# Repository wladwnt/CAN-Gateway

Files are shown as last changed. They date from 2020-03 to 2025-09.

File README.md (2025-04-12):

# CAN-Gateway for Hoval devices (TopTronic&reg; E series)
DEUTSCH: [Wiki](https://github.com/wladwnt/CAN-Gateway/wiki/Deutsche-Wiki) |  [Detailierte Bedienungsanleitung](https://raw.githubusercontent.com/wladwnt/CAN-Gateway/master/Bedienungsanleitung.pdf) | [Zum CAN-Gateway in 7 Schritten](https://github.com/wladwnt/CAN-Gateway/wiki/Schritte-zum-CAN-Gateway) | [Video dazu](https://youtu.be/HU5wEv3FgdE)

ENGLISH: [Wiki](https://github.com/wladwnt/CAN-Gateway/wiki/English-Wiki) |  [Detailed operating manual](https://raw.githubusercontent.com/wladwnt/CAN-Gateway/master/Operating_manual.pdf) | [7 steps to CAN-Gateway](https://github.com/wladwnt/CAN-Gateway/wiki/Steps-to-CAN-Gateway) | [Intro video](https://youtu.be/7HJrZkuCv4k)

Fragen? / Questions? Please contact me via Email: info@myhome-control.de. (I usually answer within of 24 h. Please check your spam folder if you dont receive an answer)

What you need:
 - CAN - Gateway dev board from [MyHome-Control Shop](https://shop.myhome-control.de/CAN-Gateway-development-board/HW10018) (Germany) with optional [housing](https://shop.myhome-control.de/Gehaeuse-fuer-CAN-Gateway-Boards/ZB10001) or board + housing from [WLED SHOP](https://wled.shop/produkt/wladis-can-gateway/) (worldwide shipment). If you have HomeVent with analogue control module (type BG02E with two rotary encoders), please order the CAN-Gateway board version with second CAN interface to be able to use the control module in parallel with CAN-Gateway.
 - CAN - Gateway Software from [MyHome-Control Shop](https://shop.myhome-control.de/CAN-Gateway-Software/SW10000.1)

When you buy the software, you will additionally get access to the [CAN-Gateway online services](https://can-gateway.myhome-control.de/api/) where you can find for example SW updates and the extended database of available parameters.

Android app:  Also in Amazon AppStore: [Link](http://www.amazon.com/gp/mas/dl/android?asin=B099S815PD).

Windows App: [Download Installer](https://raw.githubusercontent.com/wladwnt/CAN-Gateway/master/App/WindowsApp/MyHomeAppSetup_Windows10_x64_v1.1.0.exe)

Bisher getestet mit: TTE-HV (HomeVent), TTE-WEZ (Wärmeerzeuger, wie Wärmepumpe), TTE-HKW (Heizkreis/Warmwasser), TTE-PS (Puffermodul), TTE-SOL (Solar), TTE-BM (Raumbedienmodul), TTE-GW (Gateway), TTE-FW (Fernwärme).

Hier ist die Software nur als eine sogenannte "Demo-Version" in kompilierter Form veröffentlicht. Diese hat im Vergleich zur vollen Version einige Einschränkungen (für Details siehe Bedienungsanleitung, Kapitel "Einschränkungen der Demo-Version").

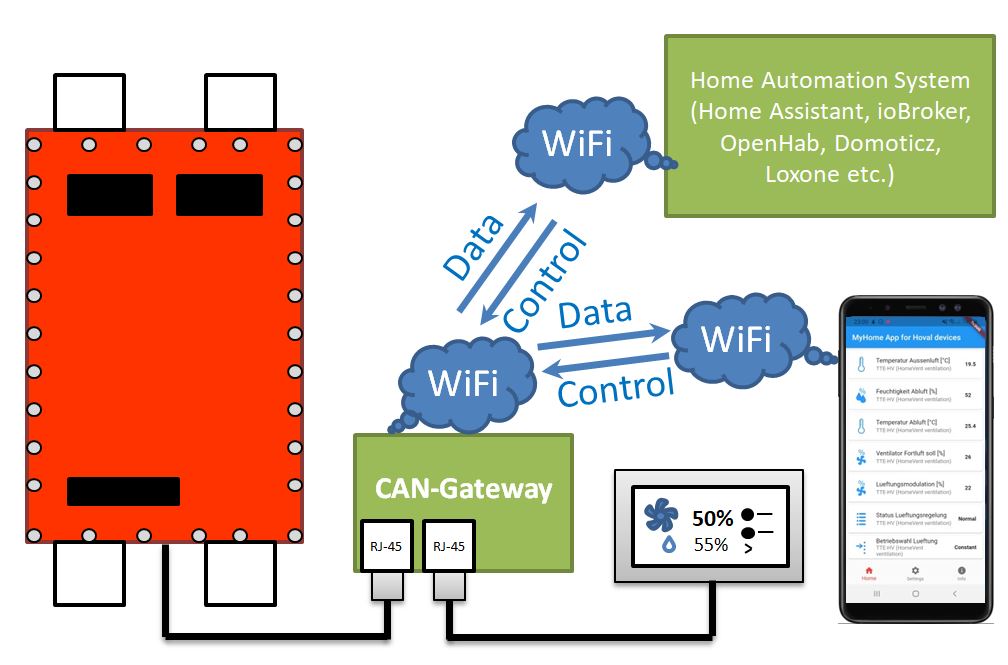
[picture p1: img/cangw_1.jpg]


## Einige Bilder/Screenshots:

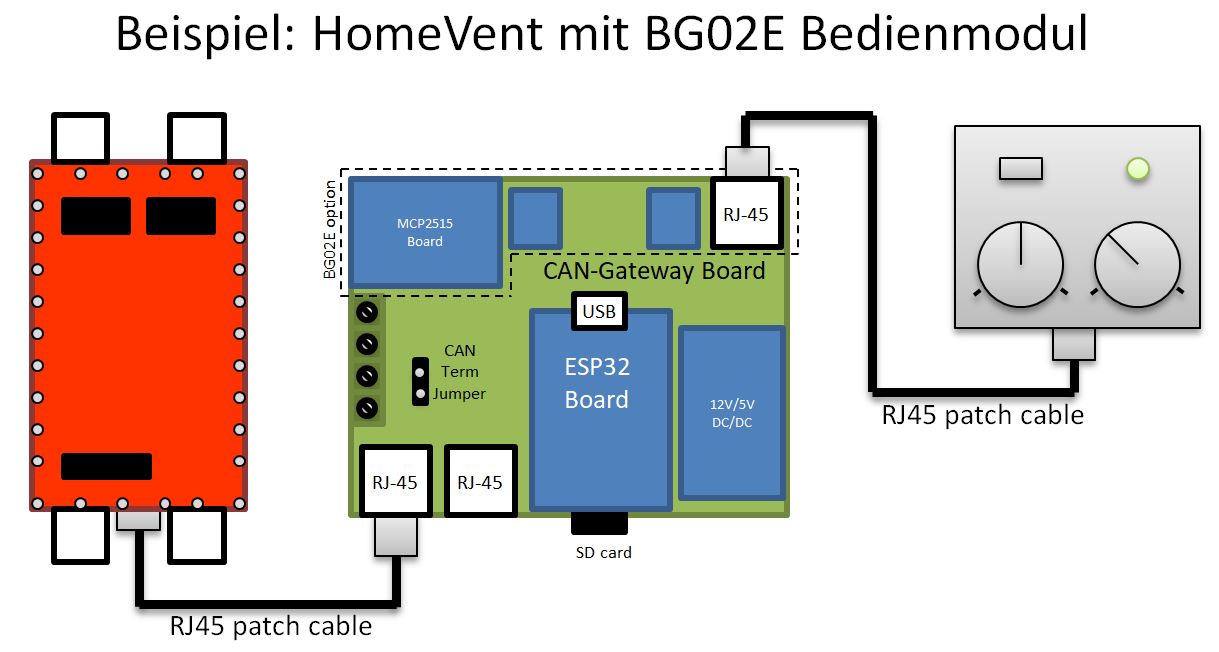
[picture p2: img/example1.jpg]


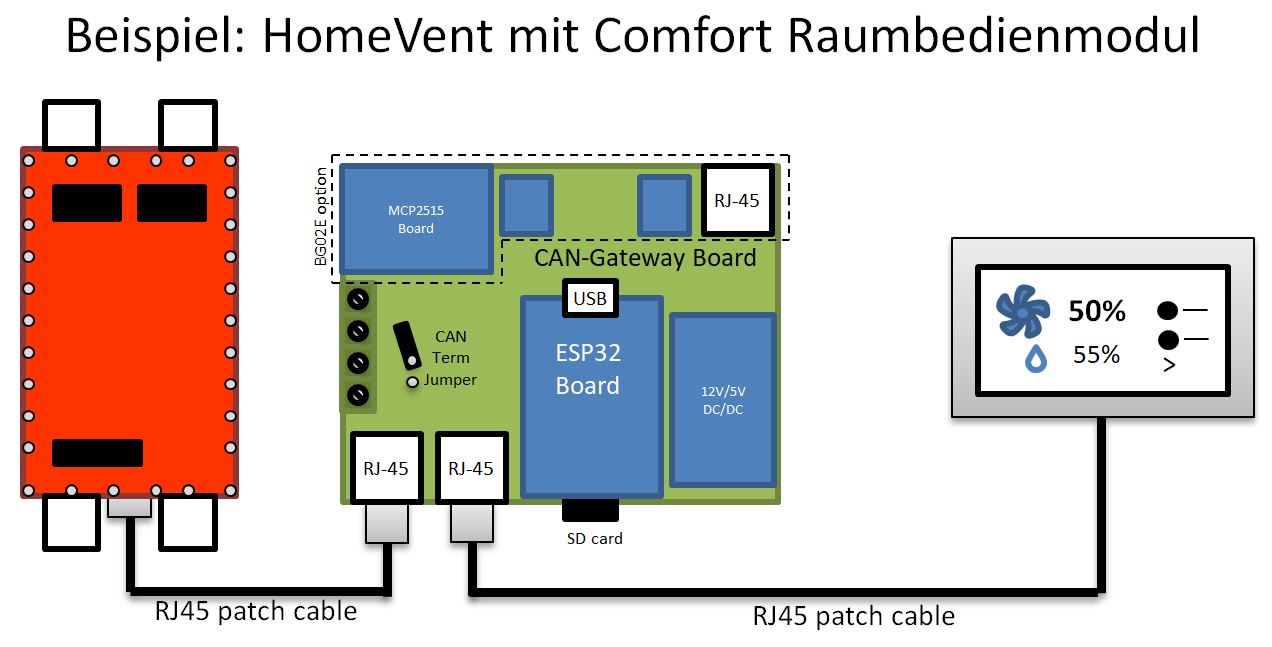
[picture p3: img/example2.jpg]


Screenshots WEB-Interface:

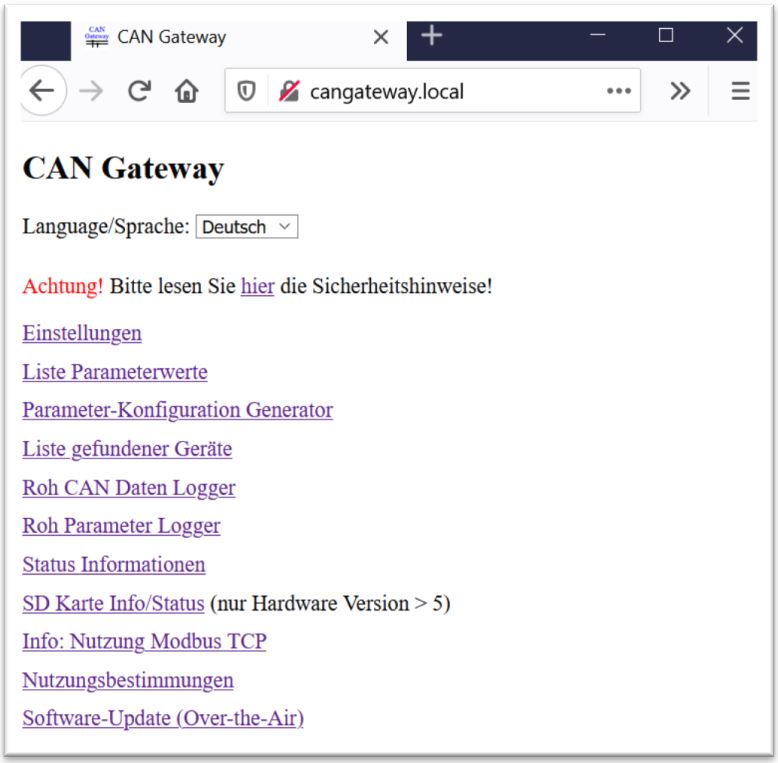
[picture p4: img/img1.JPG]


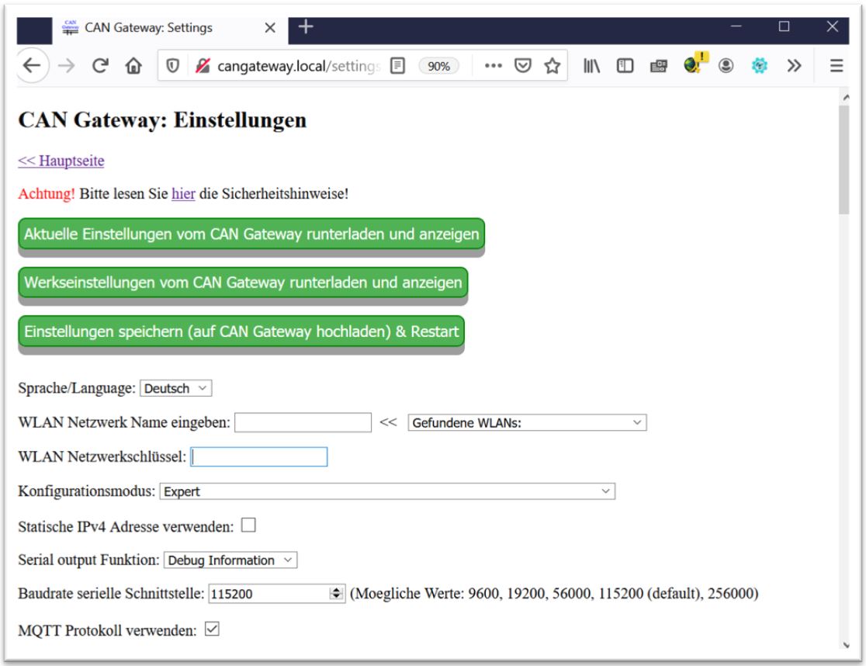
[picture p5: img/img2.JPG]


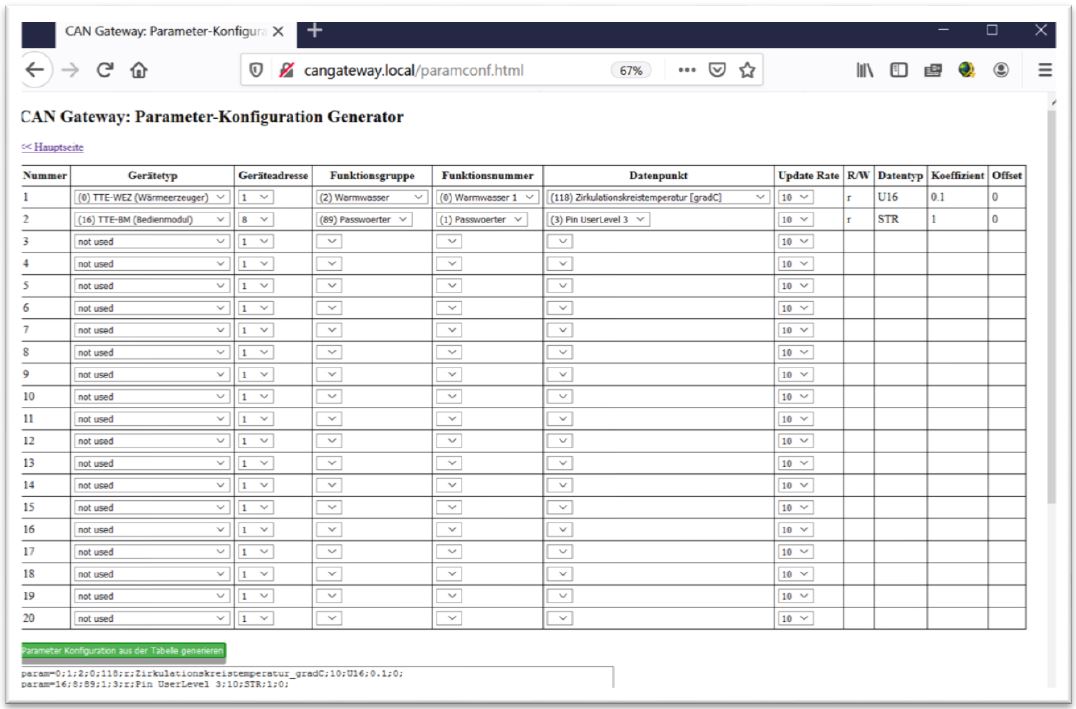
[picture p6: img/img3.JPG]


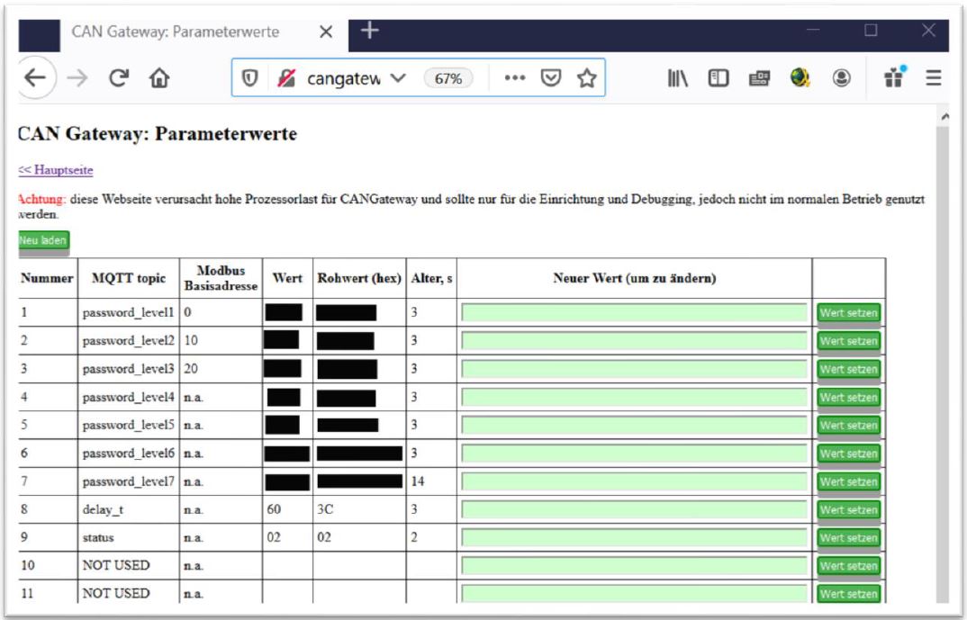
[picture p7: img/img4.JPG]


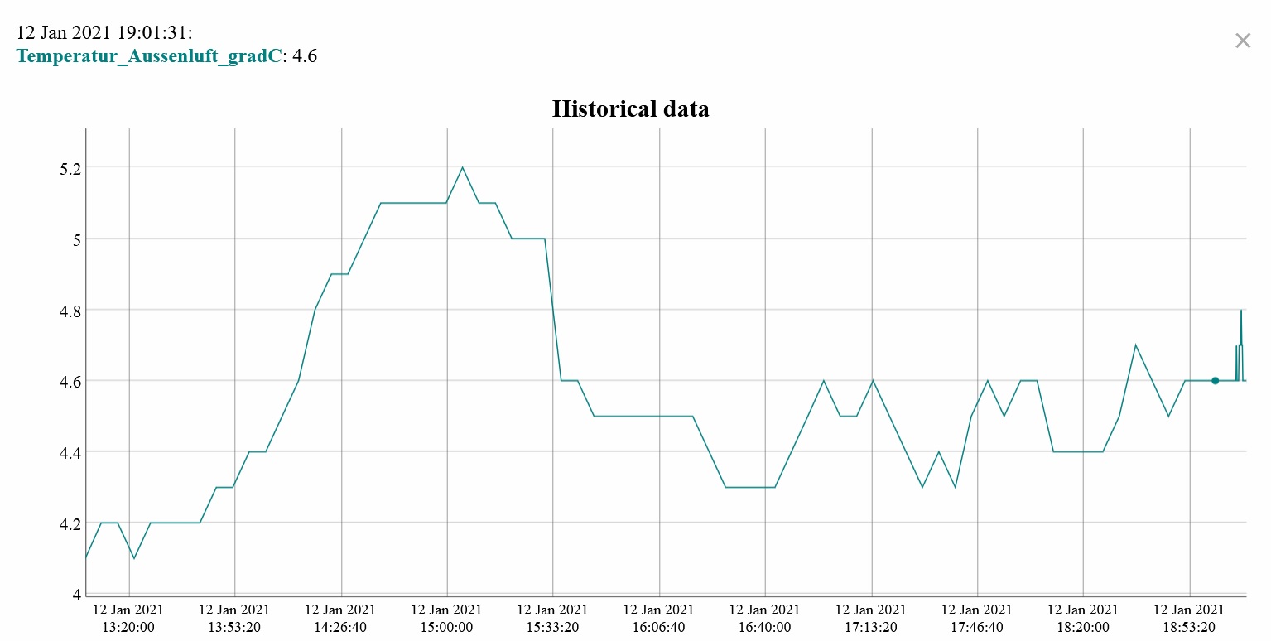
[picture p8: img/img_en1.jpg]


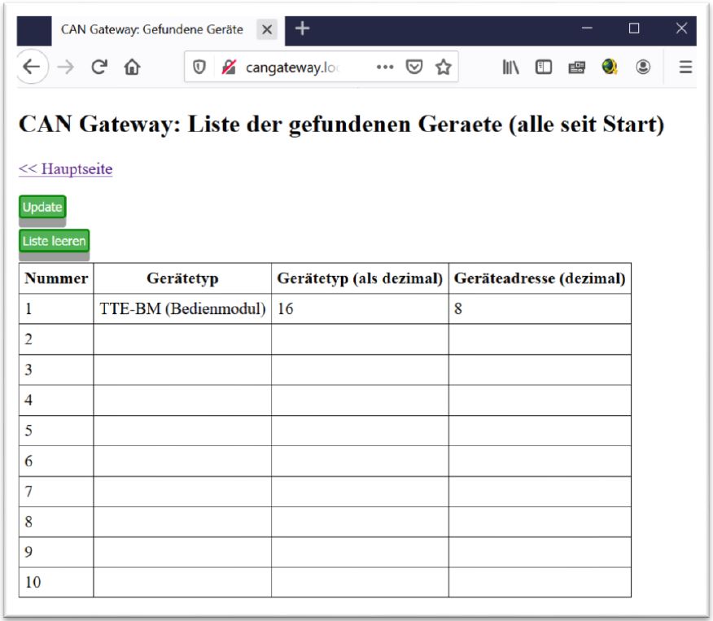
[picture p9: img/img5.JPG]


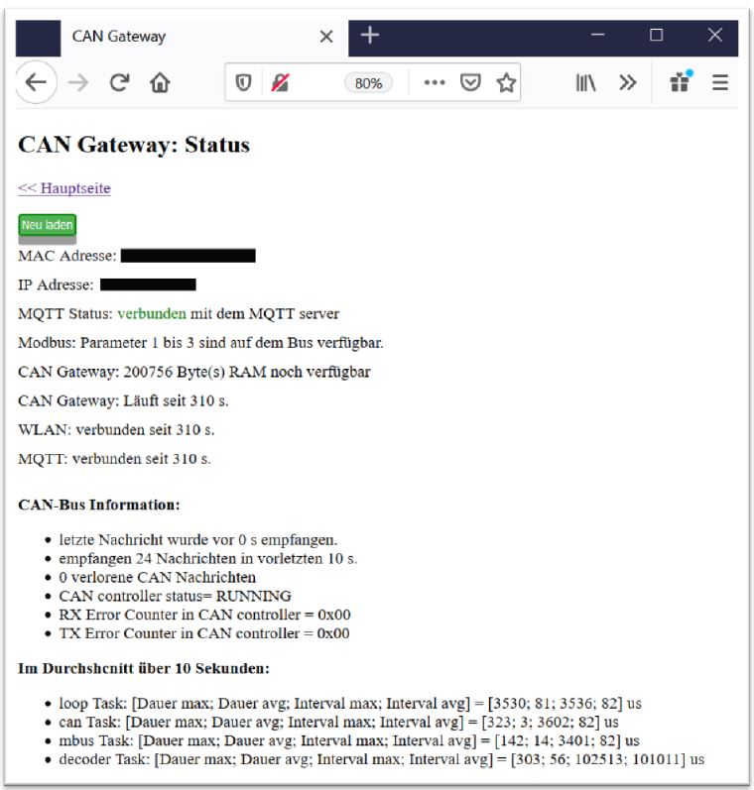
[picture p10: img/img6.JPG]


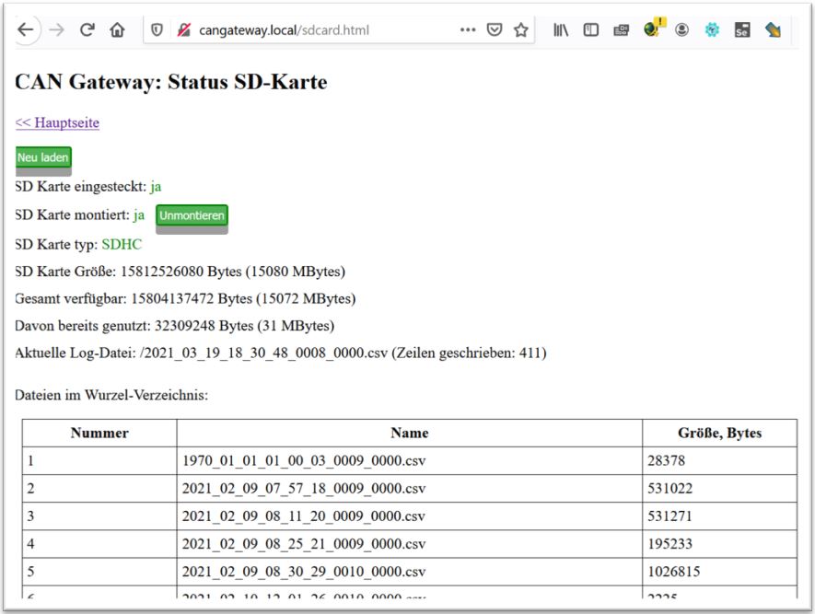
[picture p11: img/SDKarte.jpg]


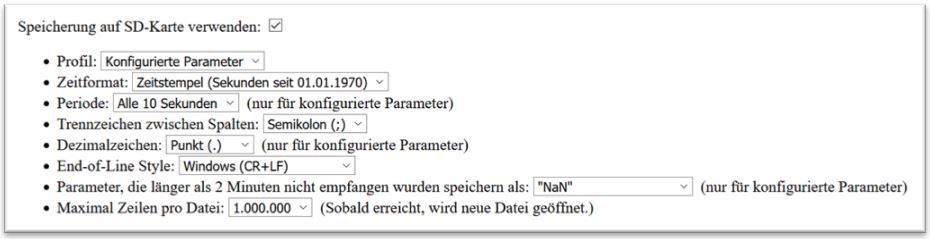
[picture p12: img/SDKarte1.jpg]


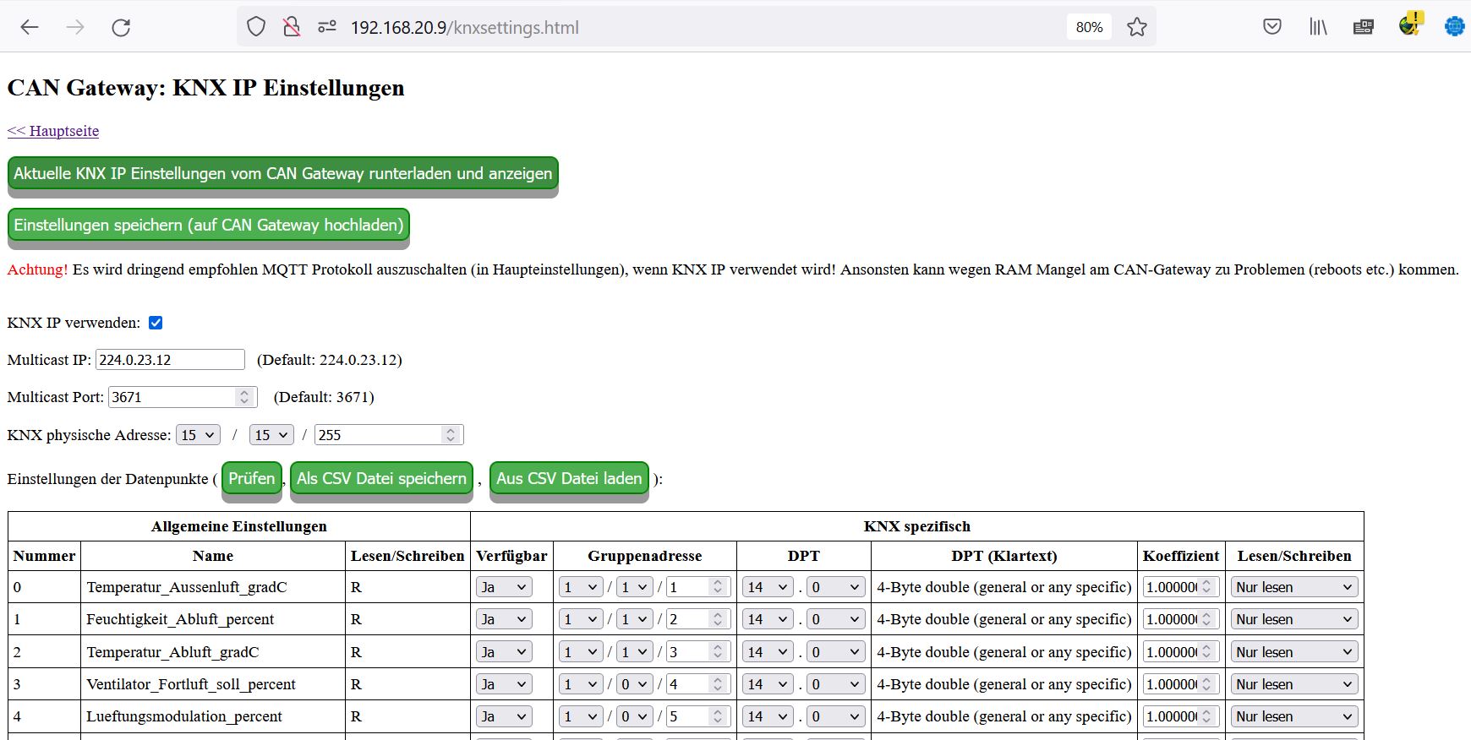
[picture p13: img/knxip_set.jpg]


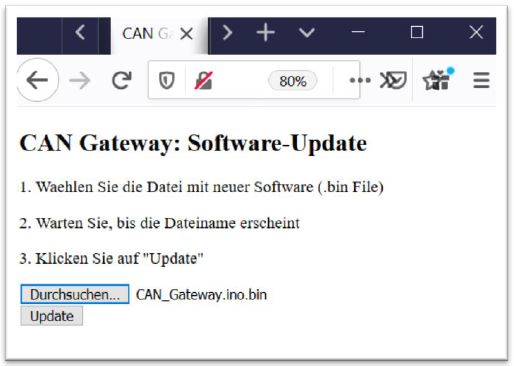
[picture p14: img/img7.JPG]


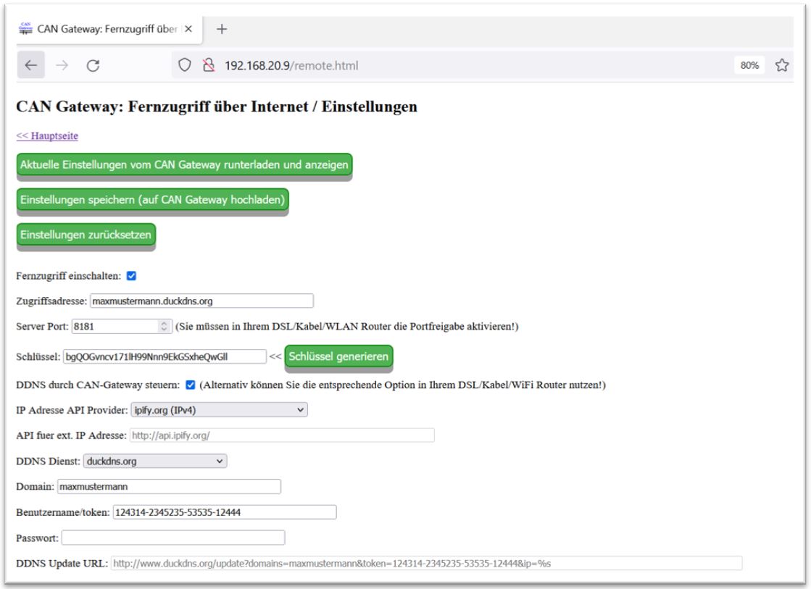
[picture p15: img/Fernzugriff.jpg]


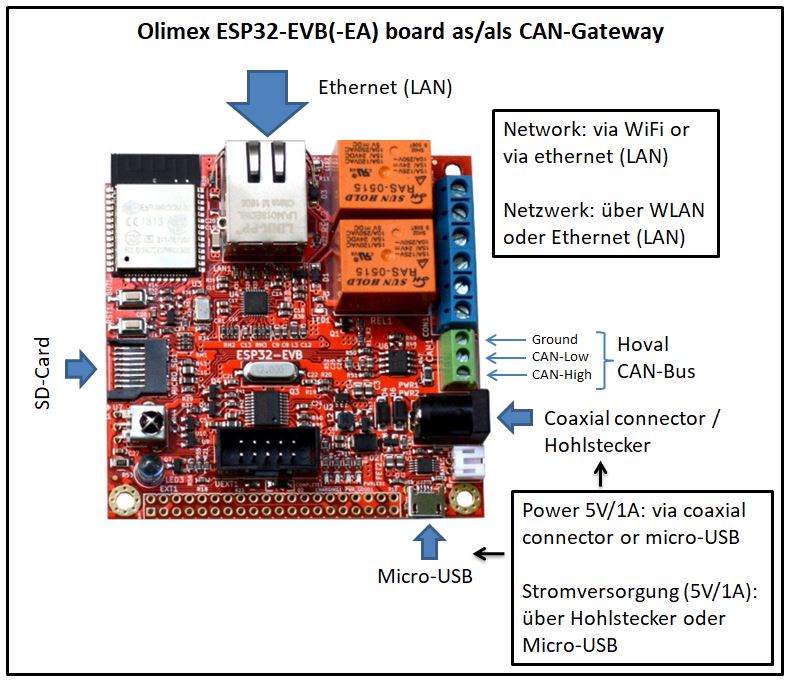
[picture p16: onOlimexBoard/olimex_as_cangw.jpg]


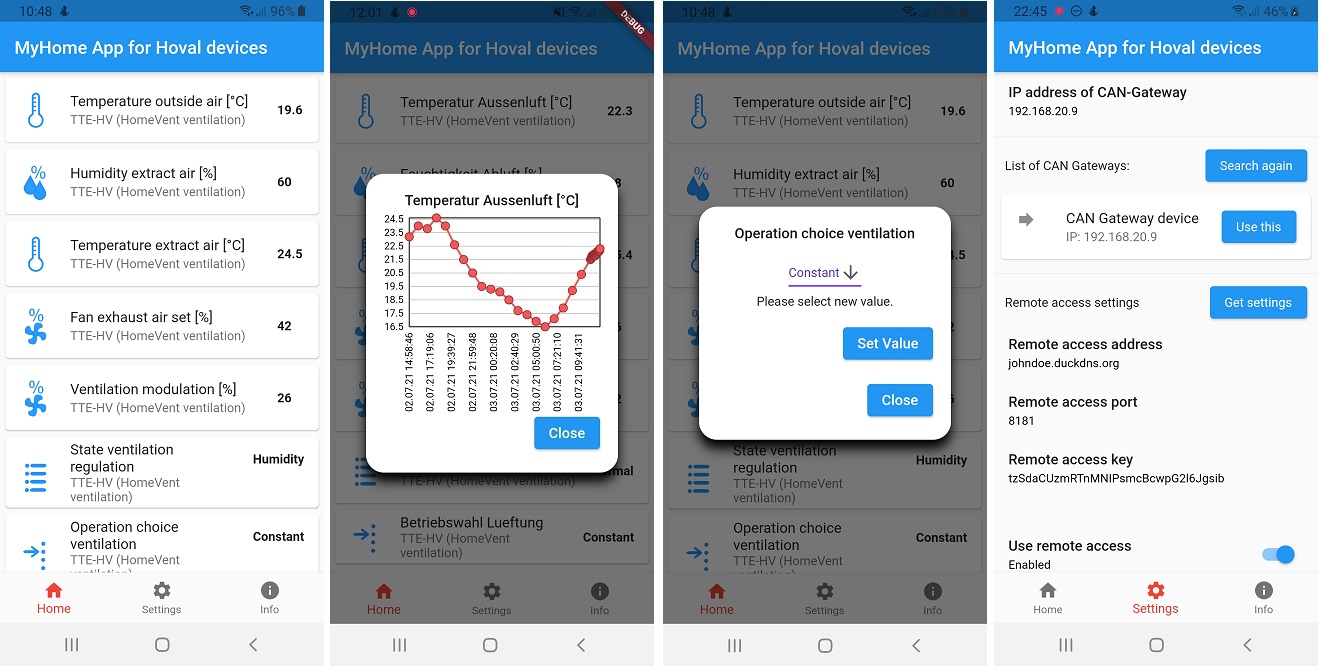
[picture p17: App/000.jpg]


Author: Dr.-Ing. Wladislaw Waag

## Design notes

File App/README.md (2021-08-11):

**NEW**: Android app for communication with CAN-Gateway.

The app is written using Flutter framework. It means iOS Version is also possible. However, I do not have MacBook and iPhone, therefore I cannot compile and test iOS version.

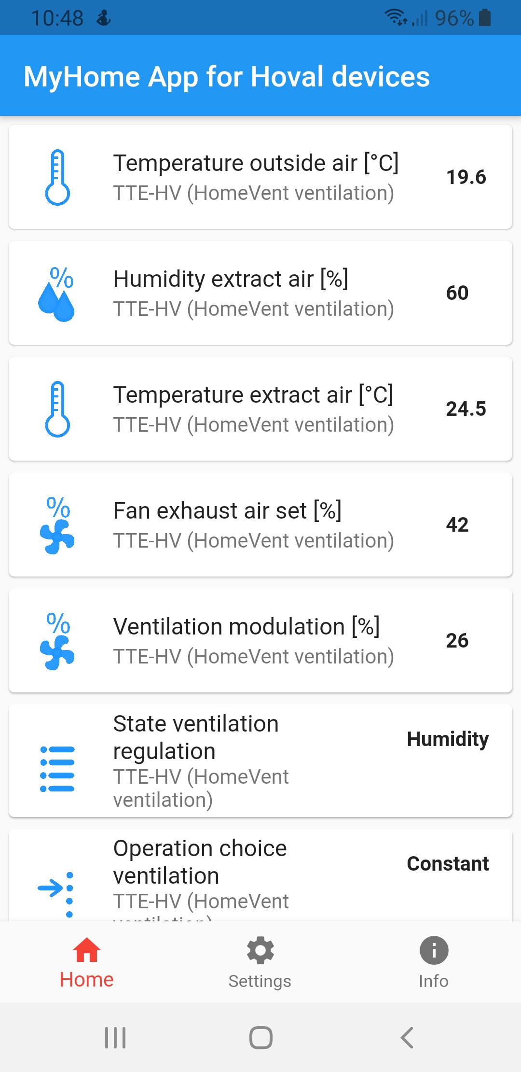
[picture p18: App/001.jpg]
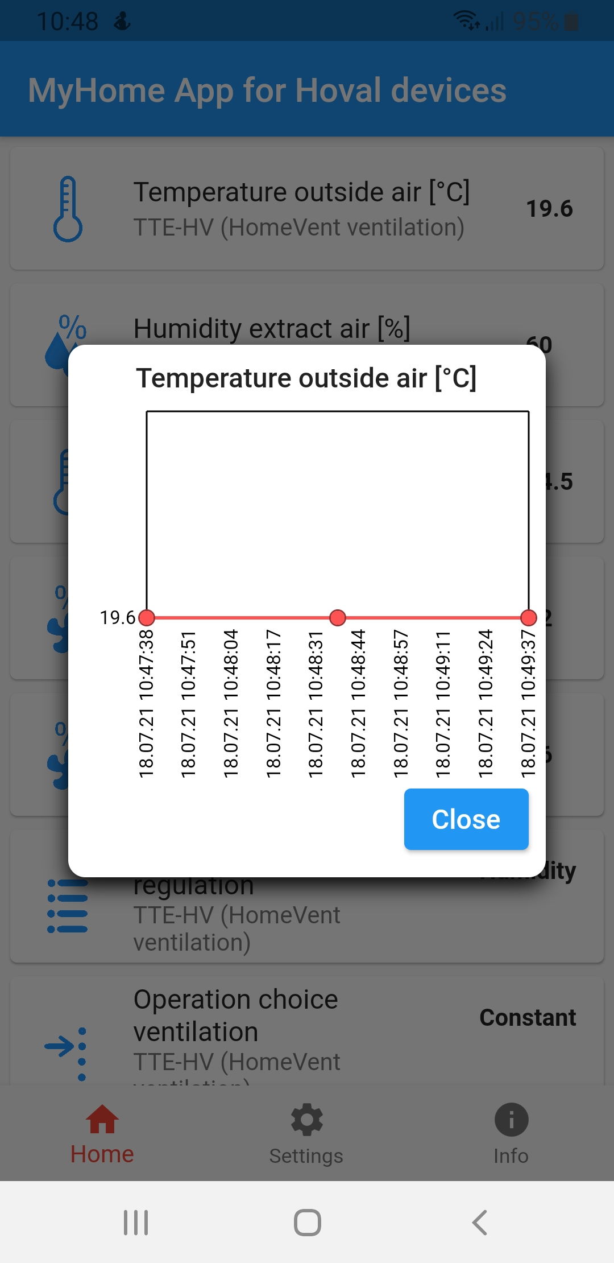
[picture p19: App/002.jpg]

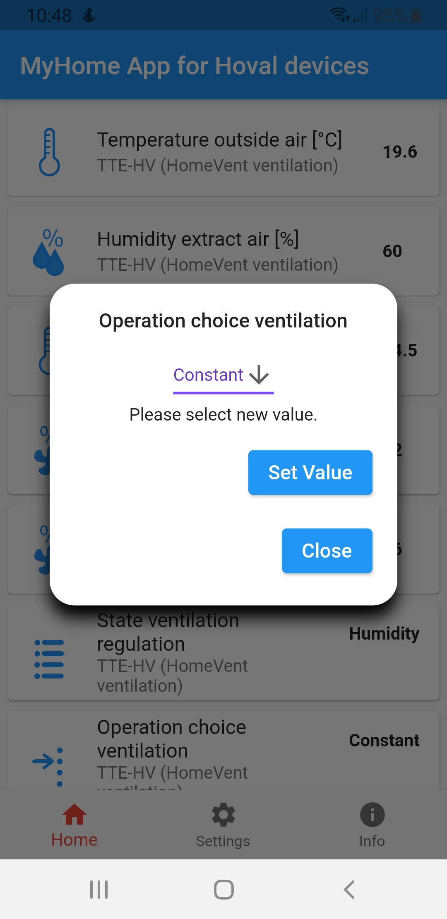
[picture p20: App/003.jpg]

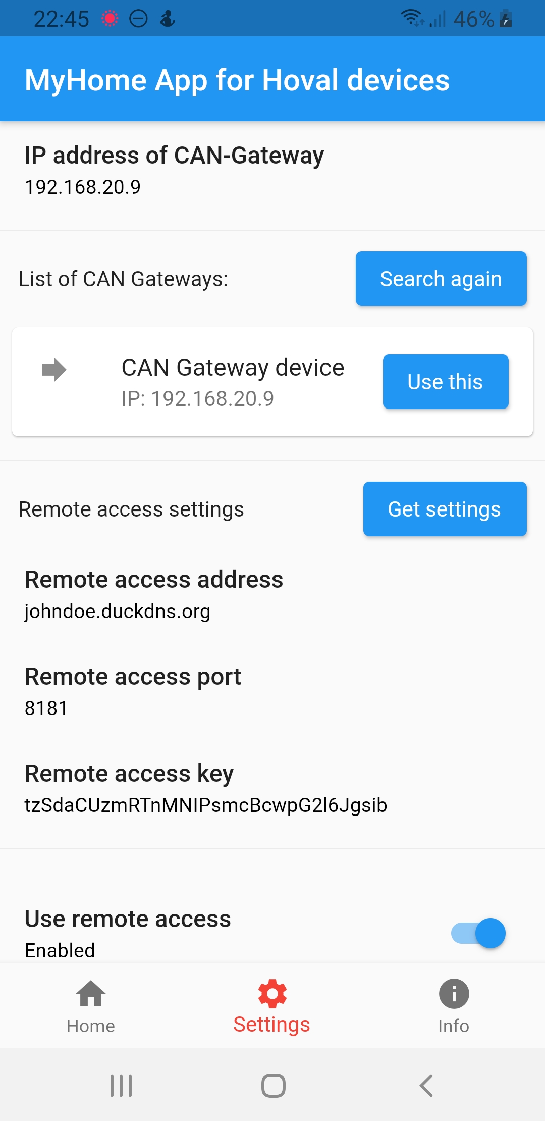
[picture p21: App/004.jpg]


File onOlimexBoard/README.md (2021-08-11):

CAN-Gateway Software can now (since SW Version 28.001) be installed on Olimex ESP32-EVB(**-EA**) boards:

Advantages of ESP32-EVB(-EA) board compared to CAN-Gateway board v5:
* Ethernet (LAN) as an alternative to WiFi (initial configuration is always via WiFi, but then you can switch to ethernet/LAN)
* **-EA** version with external WiFi antenna
* Metal box is available from Olimex for **-EA** version

Drawbacks of ESP32-EVB(-EA) board compared to CAN-Gateway board v5:
* No RJ45 connectors for Hoval CAN-Bus, only screw terminals
* SD-Card: no automatic mount/unmount on insert
* External power source is required, no option for power supply by Hoval CAN-Bus
* No BG02E interface option

You can buy ESP32-EVB(-EA) board from [Olimex](https://www.olimex.com/Products/IoT/ESP32/ESP32-EVB/open-source-hardware) and install [Demo Version of CAN-Gateway](https://github.com/wladwnt/CAN-Gateway/tree/master/Software/Version28) on it.



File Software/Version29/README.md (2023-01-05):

This is old version. For the newest one please refer to [WEB based CAN-Gateway Demo Flasher](https://wladwnt.github.io/)

**Version 29.008 / Demo**
 - for CAN-Gateway HW V5 (DO NOT install it on CAN-Gateway Development Board V7 / V8, use WEB Flasher for that)
 - for Olimex ESP32-EVB(-EA) Board

**How to flash this firmware (on Windows)**

The easiest way is to use the new CAN-Gateway Flasher (based on ESPHome Flasher):
1) Download [CANGateway_Flasher.exe](https://raw.githubusercontent.com/wladwnt/CAN-Gateway/master/Software/Version29/CANGateway-Flasher.exe)
3) Install drivers for your board (CP210x or CH340, see operating manual PDF file for details)
4) Plug your board via USB to your PC/Laptop
5) Start CANGateway_Flasher.exe
6) Select the COM port and Firmware
7) Click on "Flash ESP"

**Attention !!!**
1) CANGateway_Flasher.exe will be recognized as containing generic Malware/Trojan by most of antivirus programs. This is false-positive, the issues is well known: it is written in python and uses PyInstaller to make executable. Unfortunately, PyInstaller is also used by many malware makers. If you have any doubts please use another method described in operating manual PDF file (using ESP32 Download Tool or esptool) or check the CANGateway_Flasher.exe online, for example at https://opentip.kaspersky.com/.
3) Your PC/Laptop must have access to the internet since CANGateway_Flasher.exe will download CAN-Gateway firmware from Github.

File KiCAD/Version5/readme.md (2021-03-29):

V5: SD card slot and BG02E interafce

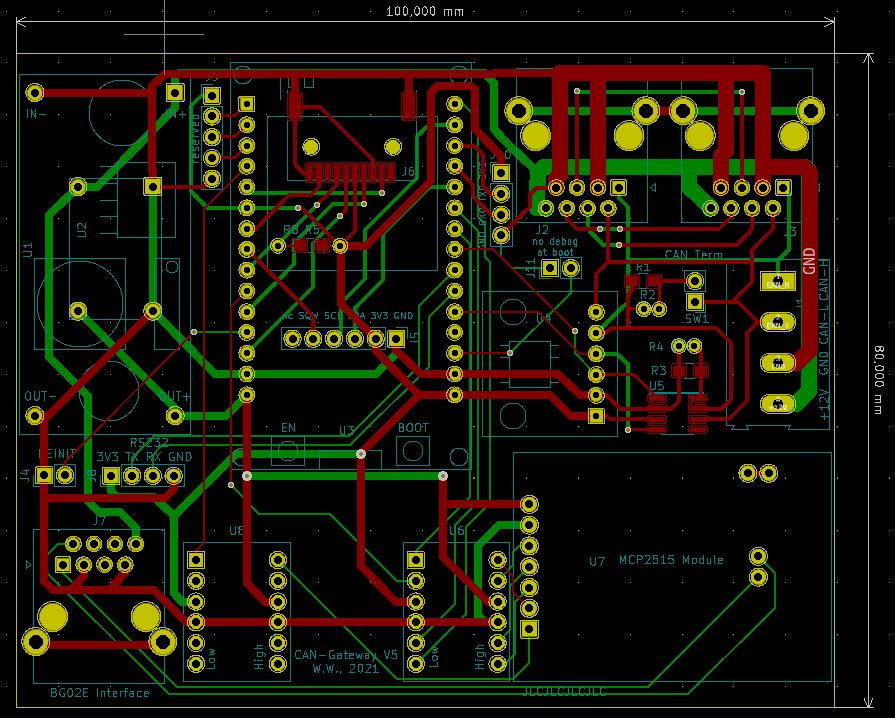
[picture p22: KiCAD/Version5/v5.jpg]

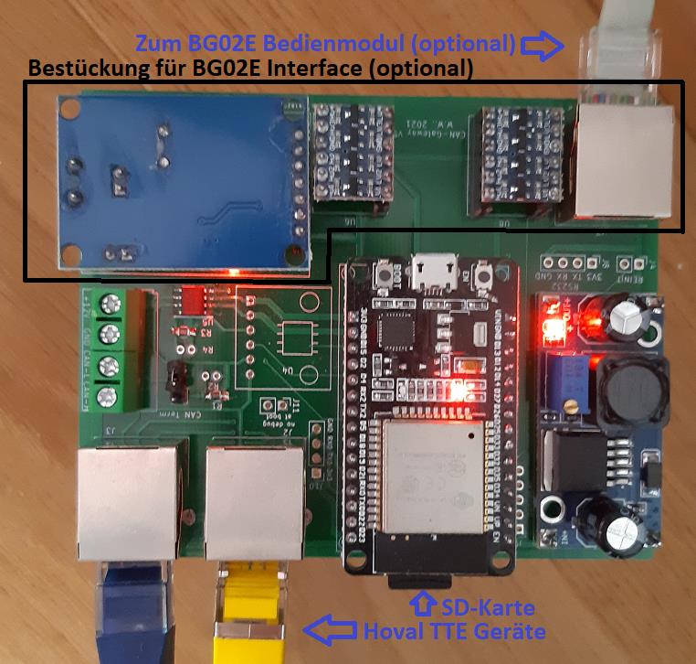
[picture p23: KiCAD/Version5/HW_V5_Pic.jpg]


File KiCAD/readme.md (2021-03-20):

V5: Mit SD-Karte (NEU in SW) und BG02E Interface (SW folgt...)




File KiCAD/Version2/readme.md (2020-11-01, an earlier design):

2. Version: alternative Bestückungsoptionen für CAN-Transceiver und DC/DC Wandler.

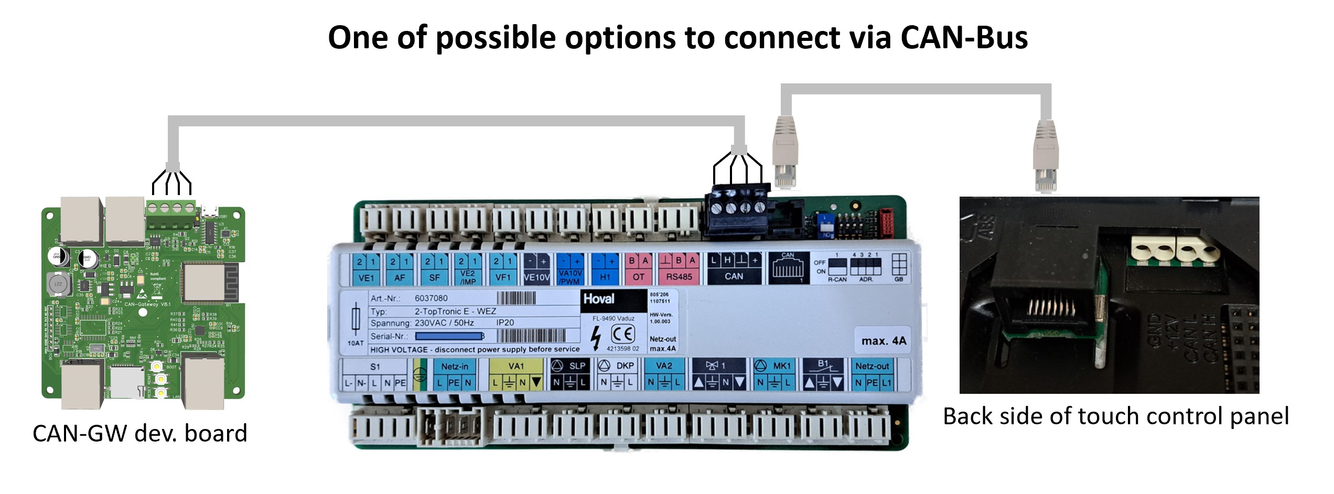
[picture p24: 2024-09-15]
img/CAN_GW_Conn3.jpg

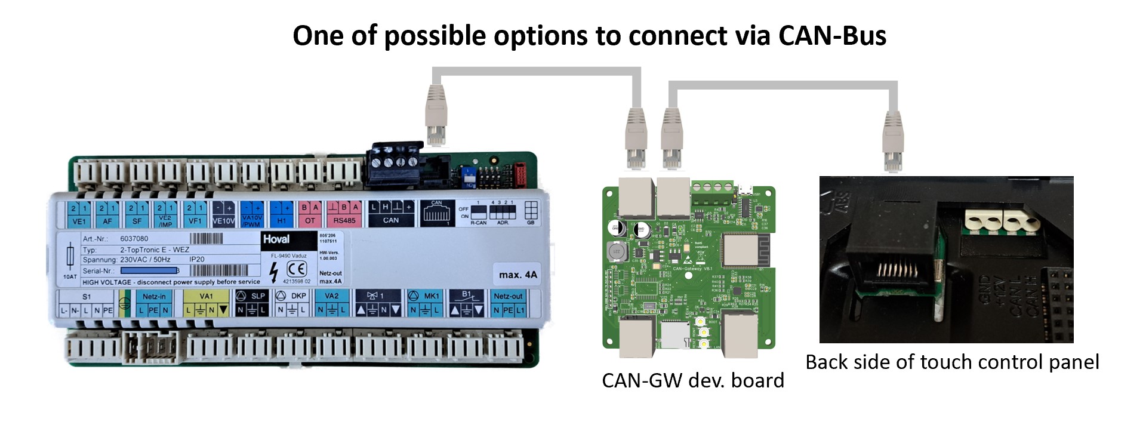
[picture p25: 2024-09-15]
img/CAN_GW_Conn2.jpg

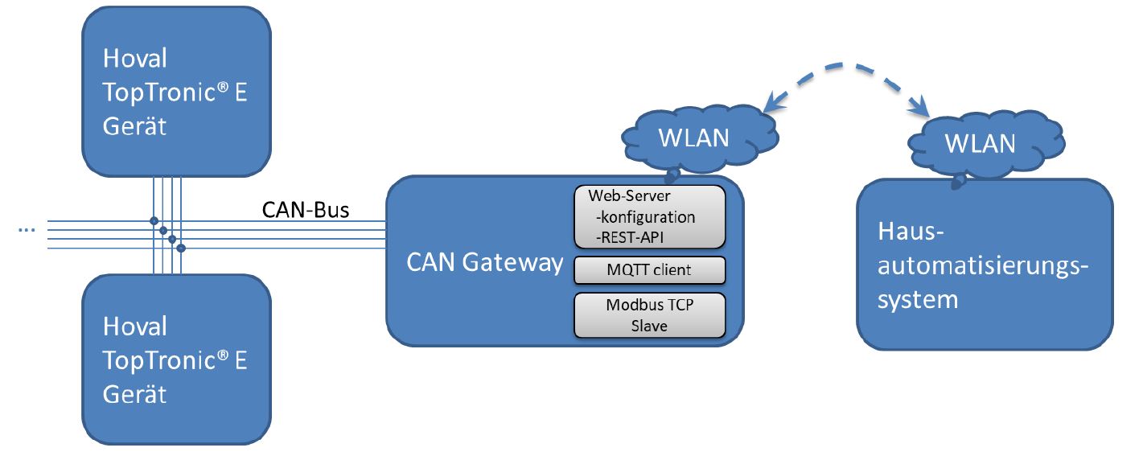
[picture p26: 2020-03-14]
img/intro.jpeg

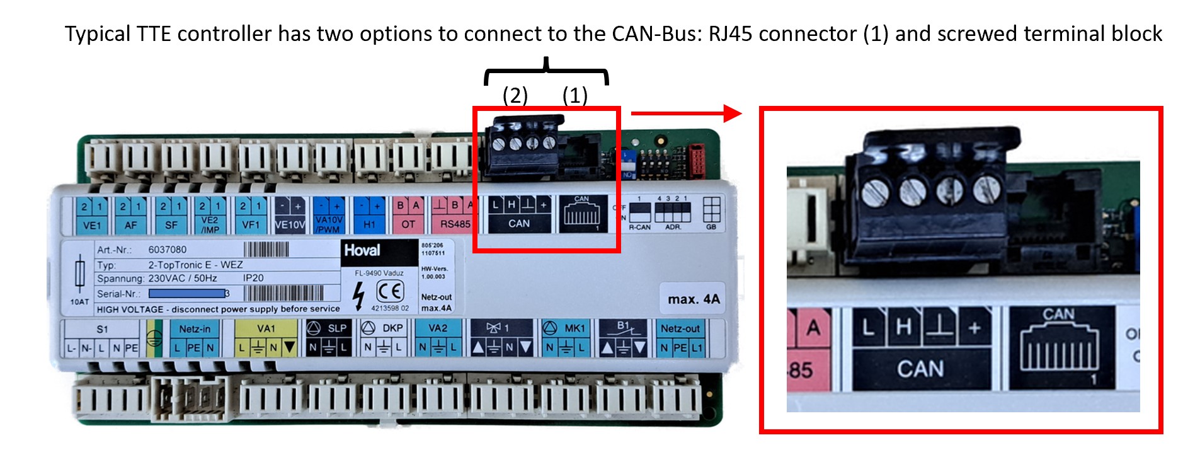
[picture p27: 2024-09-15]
img/CAN_GW_Conn1.jpg

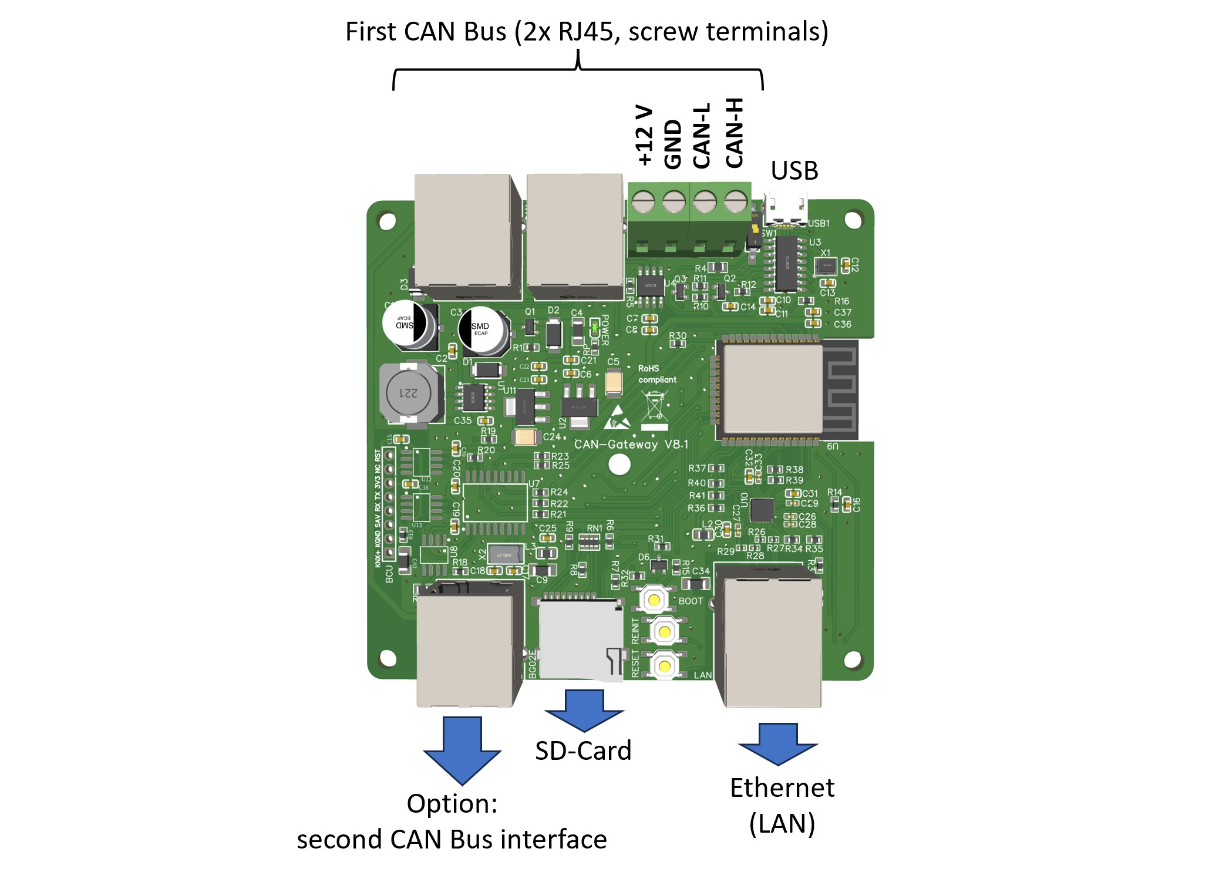
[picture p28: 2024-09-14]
img/CAN_DEV_BOARD_4.jpg

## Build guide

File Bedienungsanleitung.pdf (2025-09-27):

© W. Waag, München, 2020-2025

# Bedienungsanleitung CAN-Gateway Software

Stand: SW Version 31.011 / Android+Windows App 1.1.1

Update 1 (27.09.2025)

### Inhaltsverzeichnis

3.2 Einfacher Aufbau bestehend aus auf dem Markt verfügbaren vorgefertigten Modulen ..... 9

29.1 | Netzwerkname/Schlüssel sind falsch eingestellt, Web-Interface nicht zugänglich. Was tun?
| 57
29.2 | CAN-Gateway startet immer mit Werkeinstellungen. Einstellungen können nicht

### 1 Wichtige Hinweise – unbedingt durchlesen!

### 1.1 Bestimmungsgemäße Anwendung der Software

Diese Software ist dafür bestimmt, Geräte der Firma Hoval AG, die mit einer TopTronic® E Regelung¹ ausgestattet sind (im folgenden TTE Geräte genannt), auszulesen und zu steuern.

Auslesen bedeutet in diesem Sinne, dass die Parameter und Informationen aus TTE Geräten über den Geräte-CAN-Bus ausgelesen und:

1. auf der CAN-Gateway Benutzeroberfläche dem Nutzer dargestellt werden können,
2. über die in der Software zur Verfügung stehenden Kommunikationsprotokolle (REST API, MQTT, KNX IP (Routing), Modbus TCP) an andere mit diesen Kommunikationsprotokollen kompatiblen Geräten übertragen werden können,
3. auf einer Micro-SD Karte gespeichert werden können.

Steuern im obigen Sinne bedeutet, dass diese Software die Änderung der Parameter und der Informationen, die über CAN-Bus in TTE-Geräten geändert werden können, bewirken kann. Diese Änderung kann:

1. direkt durch den Nutzer über die Benutzeroberfläche oder Android App oder Windows App eingesteuert werden

1 TopTronic ist die geschützte und eingetragene Marke der Firma Hoval AG

2. durch ein mit dieser Software über ein der oben aufgelisteten Kommunikationsprotokollen verbundenes Gerät eingesteuert werden.

Die CAN-Gateway Software beinhaltet keinerlei Logik, die selbständig Änderungen der Parameter und Informationen in TTE Geräten initiiert.

Die oben beschrieben Funktionalitäten der Software sollen ermöglichen die TTE-Geräte in ein Hausautomatisierungssystem einzubinden.

Welche Parameter und Informationen ausgelesen und/oder geändert werden können, hängt von dem jeweiligen TTE Gerät ab. Vertraglich garantiert wird die Funktionalität für alle Parameter, die in der folgenden Datei der Firma Hoval AG aufgelistet sind: http://www.hoval.com/misc/TTE/TTE-GW-Modbus-datapoints.xlsx. (http://www.hoval.com/misc/TTE/TTE-GW-Modbus-datapoints.xlsx) In der Regel ist zusätzlich Auslesen aller Parameter, die über ein TTE Bedienmodul im Menu „Service“ bei allen User Levels angezeigt werden, möglich, wird jedoch vertraglich nicht garantiert.

Die Software kann angewendet werden, indem sie auf einem kompatiblen Mikrocontroller ausgeführt wird. Kompatibel sind ESP32 Dual-Core Mikrocontroller der Firma Espressif (https://www.espressif.com/). Zudem muss zwingend eine kompatible Beschaltung des Mikrocontrollers vorhanden sein. Diese Beschaltung muss unter anderem die notwendige Stromversorgung des Mikrocontrollers sowie die Anbindung der physikalischen Schnittstellen wie CAN-Bus und Ethernet ermöglichen. Für die Nutzung der SD-Karte Funktionalität muss an den Mikrocontroller ein SD-Kartenslot angeschlossen werden. Die Beschaltung muss angelehnt an eine der drei Referenzbeispiele erfolgen:

a) CAN-Gateway Hardware V5, wie in Bedienungsanleitung beschrieben
b) CAN-Gateway Development Board, siehe http://wled.shop/wp-content/uploads/2021/11/CAN_Gateway_Nutzungsinformationen.pdf (http://wled.shop/wp-content/uploads/2021/11/CAN_Gateway_Nutzungsinformationen.pdf)
c) Olimex ESP32-EVB(-EA) Entwicklungsboard Rev. I, siehe https://www.olimex.com/Products/IoT/ESP32/ESP32-EVB/open-source-hardware

Entsprechen dieser Referenzbeispiele wird die Software in drei Varianten a, b und c angeboten. Der Kunde muss bei der Bestellung sich für eine der drei Varianten entscheiden.

Aus Performance-Gründen wird es empfohlen gleichzeitig nur ein Kommunikationsprotokoll (MQTT, KNX IP, REST-API) oder Datenspeicherung auf SD-Karte zu verwenden / zu aktivieren. Eine parallele Verwendung ist zwar theoretisch möglich, kann aber zu Performance Problemen führen und wird daher nicht garantiert.

### 1.2 Gefahrenhinweise

WARNUNG: Diese Software basiert auf der Analyse der Kommunikation zwischen TTE Geräten und nicht auf offiziellen Informationen des Geräteherstellers. Es muss angenommen werden, dass die Analyse nicht vollständig, fehlerhaft und lückenhaft ist sowie nicht auf alle Geräte und deren Versionen, vor allem zukünftige Versionen, anwendbar sein kann. Daraus folgt, dass bei sicherheitskritischen TTE Geräten, bei denen Fehler in der Ansteuerung zu Beschädigungen von Personen, Umwelt, Geräten, Gebäuden etc. führen können, der Einsatz dieser Software nur beaufsichtigt erfolgen muss. Beaufsichtigt bedeutet, dass dieses Gerät und alle damit verbundenen TTE Geräte ständig von einer Person überwacht werden müssen, die aufgrund Ihrer Ausbildung oder Erfahrung in der Lage ist Fehler zu erkennen und alle TTE Geräte notfalls innerhalb weniger Sekunden abzuschalten. Das betrifft insbesondere ausdrücklich, aber nicht ausschließlich, Heizungsgeräte mit Verbrennung.

HINWEIS: Der Hersteller Hoval AG vertreibt selbst Gateways für die Anbindung seiner TTE Geräten an die Hausautomatisierungssysteme unter anderem über KNX oder ModBus RTU/TCP Busse/Protokolle. Der Anbieter dieser CAN-Gateway Software empfiehlt diese Gateways der Firma Hoval AG für den produktiven Einsatz bei sicherheitskritischen Systemen zu verwenden.

HINWEIS: Die Verwendung dieser Software in Verbund mit TTE Geräten kann eventuell dazu führen, dass die Garantie- und Gewährleistungsansprüche für diese TTE Geräte sich erlöschen. Der Benutzer dieser Software ist selbst dafür zuständig das Vorhandensein entsprechender Klauseln in Dokumentationen zu seinem TTE Gerät und die gesetzliche Lage dazu in seinem Land zu prüfen.

WARNUNG: Diese Software erlaubt Parameter der TTE Geräte zu ändern. Diese Software prüft keinerlei ob die Änderung der Parameter sinnvoll und ungefährlich für den Betrieb des TTE Gerätes und anderer damit verbundenen TTE Geräten und sonstigen Anlagen, für Nutzer und Bedienpersonal dieser TTE Geräte und Anlagen, für die Umwelt sowie das Gebäude, wo diese Geräte und damit verbundene Anlagen installiert sind, ist. Als Nutzer der Software müssen Sie mit
Parameteränderungen sehr aufmerksam umgehen und nur solche Parametrierungen zulassen und direkt oder indirekt einsteuern, deren Sinn Sie zu 100% verstehen und deren Ungefährlichkeit und Unschädlichkeit für den Betrieb des TTE Gerätes und anderer damit verbundenen TTE Geräten und sonstigen Anlagen, für Nutzer und Bedienpersonal dieser TTE Geräte und Anlagen, für die Umwelt sowie das Gebäude, wo diese Geräte und damit verbundene Anlagen installiert sind zu 100% gegeben ist.

WARNUNG: Wenn Sie den Mikrocontroller, auf dem diese Software installiert ist, in Ihrem WLAN oder LAN Netzwerk verwenden, müssen Sie dafür sorgen, dass keine fremden Personen den Zugang zu diesem Netzwerk bekommen, da alle Personen mit dem Zugang zu Ihrem Netzwerk auf CAN-Gateway uneingeschränkt zugreifen können.

WARNUNG: Der Mikrocontroller, auf dem diese Software installiert ist, muss physikalisch für fremde Personen unzugänglich sein. Alle Personen, die physikalisch auf den Mikrocontroller zugreifen können, können die drauf gespeicherten Informationen inkl. Ihre Einstellungen und Passwörter ohne großen Aufwand auslesen.

HINWEIS: Jede andere Verwendung, als hier beschriebene, ist nicht bestimmungsgemäß und führt zu Gewährleistungs- und Haftungsausschluss.

HINWEIS: Jede Änderung und Modifikation der Software durch den Anwender führen zu Gewährleistungs- und Haftungsausschluss des Anbieters.

### 1.3 Haftung des Softwareherstellers bzw. des Anbieters

Für Mängel der CAN-Gateway Software haftet der Anbieter nach Maßgabe der gesetzlichen Bestimmungen des Kaufrechts (§§ 434 ff. BGB). Bei leichter Fahrlässigkeit haftet der Anbieter nur bei Verletzung vertragswesentlicher Pflichten (Kardinalpflichten) sowie bei Personenschäden nach Maßgabe des Produkthaftungsgesetzes. Im Übrigen ist die vorvertragliche, vertragliche und außervertragliche Haftung des Anbieters auf Vorsatz und grobe Fahrlässigkeit beschränkt,
wobei die Haftungsbegrenzung auch im Falle des Verschuldens eines Erfüllungsgehilfen des Anbieters gilt.

Die Haftung des Anbieters ist in folgenden Fällen vollständig ausgeschlossen:

1. Ein Fehler und die daraus folgenden direkten und/oder indirekten Schäden sind durch eine fehlerhafte Ausführung der Software z.B. aufgrund fehlerhafter Hardware oder aufgrund äußerer Einflüsse auf die Hardware (mechanischer, elektrischer, elektromagnetsicher oder anderer Art) entstanden.
2. Ein Fehler und die daraus folgenden direkten und/oder indirekten Schäden sind durch eine fehlerhafte Bedienung der Software, inklusiv z.B. die Einsteuerung nicht sinnvoller, falscher oder sogar gefährlicher Parameteränderungen durch den Nutzer entstanden. Das beinhaltet eine direkte Steuerung durch die Benutzeroberfläche, über Android oder Windows App, oder eine indirekte Steuerung, indem der Nutzer andere Geräte so programmiert oder eingestellt hat, dass sie die Änderung der Parameter durch ein Kommunikationsprotokoll über CAN-Gateway Software bewirken haben.
3. Ein Fehler und die daraus folgenden direkten und/oder indirekten Schäden sind durch andere Gründe, die der Anbieter der Software nicht zu vertreten hat, entstanden.

### 1.4 Bindung der Software an eine durch den Kunden angegebene MAC Adresse

Diese Software, ausgenommen die Demoversion, wird an eine durch den Kunden angegebene MAC Adresse des WiFi Moduls des ESP32 Mikrocontrollers gebunden. Das bedeutet, dass die Software nur auf diesem Mikrocontroller mit dieser MAC Adresse ihren vollen Funktionsumfang hat.

Der Kunde hat Recht die Software auf einen anderen Mikrocontroller mit einer anderen MAC-Adresse zu übertragen (im Folgenden Übertragung genannt). Dazu muss er sich mit dem Anbieter per Email, telefonisch oder auf dem Postweg in Verbindung setzen und die Übertragung beantragen. Dabei ist die MAC Adresse des alten Mikrocontrollers und die MAC Adresse des neuen Mikrocontrollers (jeweils des WiFi Moduls) anzugeben. Der Anbieter wird die Anfrage innerhalb von 10 Arbeitstagen bearbeiten. Nach Inbetriebnahme der Software auf dem neuen Mikrocontroller muss der Kunde die Software auf dem alten Mikrocontroller sowie alle bei ihm ggf. noch vorhandenen Sicherungskopien der Software vollständig löschen.

Wird die Übertragung der Software von einem Kunden öfter als einmal pro Jahr beantragt, muss er dafür eine plausible Erklärung abgeben. Bei einem begründeten Verdacht auf Missbrauch und Verletzung der Urheberrechte des Anbieters, kann der Anbieter die Übertragung der Software verweigern.

### 2 Einleitung

Diese Software erlaubt es die Geräte der Serie „TopTronic® E“ der Firma Hoval Aktiengesellschaft an das Hausautomatisierungssystem anzubinden. Diese Geräte werden im Folgenden einfach „Geräte“ genannt.

Die Geräte der Serie „TopTronic® E“ der Firma Hoval Aktiengesellschaft besitzen einen CAN-Bus Anschluss. Dieser wird für die Verbindung der Geräte untereinander verwendet. CAN-Gateway kann an dieses CAN-Bus angeschlossen werden und kann die auf dem Bus übertragenen Daten entschlüsseln und selbst die Daten auf dem Bus generieren, so dass damit Auslesen der Informationen aus den Geräten sowie die Steuerung der Geräte möglich ist. Die Schnittstelle für CAN-Bus ist bei den Geräten physikalisch als RJ45 Buchse oder Schraubklemme ausgeführt und beinhaltet außerdem 12V Versorgungspins, die man für Kleinverbraucher (wie CAN-Gateway) nutzen kann.

Diese Software selber muss dafür auf einem ESP32 Dual-Core Mikrocontroller installiert werden. Die genaue Beschreibung der benötigten Hardwarekomponenten und der Aufbau sind im nächsten Kapitel gegeben. Der so aufgebaute ESP32 basiertes Board mit installierter Software wird im Folgenden als „CAN-Gateway“ bezeichnet.

ESP32 Mikrocontroller besitzt einen WLAN Interface, so dass das Hausautomatisierungssystem über WLAN mit dem CAN-Gateway verbunden werden kann. Als Datenübertragungsprotokolle zwischen CAN-Gateway und dem Hausautomatisierungssystem können wahlweise MQTT Protokoll, Modbus TCP Protokoll, KNX IP Protokoll oder REST-API verwendet werden, wobei MQTT Protokoll empfohlen wird und Modbus TCP Protokoll nur mit einigen Einschränkungen funktioniert.

Über WLAN Interface kann CAN-Gateway mithilfe eines Internet Browsers konfiguriert werden.

Zusätzlich hat die Software folgende Funktionen:

- CAN Daten Logger (Rohdaten) über WEB-Interface
- Ausgabe aller Geräte mit Ihrem Typ/Adresse, die auf dem CAN-Bus kommunizieren
- Ausgabe aller auf dem CAN-Bus übertragener Parameter

### 3 Benötigte Hardware und Aufbau

Es stehen verschiedene Optionen zur Verfügung:

Variante | Empfe-hlung? | Gesamte Hardware Kosten (inkl. Versand nach Deutschland, Preise sind inkl. Versand, Stand 15.2.2022, Preise können variieren) | Vorteile / Nachteile
CAN-Gateway development board von https://wled.shop | Ja | ca. 52 € | Vollständig aufgebaut und getestet. EU-weit lieferbar. In Deutschland auch über https://shop.myhome-control.de/ (https://shop.myhome-control.de/) erhältlich.
Olimex ESP32-EVB(-EA) development Board inkl. Gehäuse | Bedingt | ca. 50 € | Kein BG02E Interface möglich, CAN Anschluss: nur Schraubklemmen. Keine Stromversorgung über Hoval CAN-Bus möglich. Als eine Version mit externer Antenne verfügbar. Weltweit lieferbar.
Eigenbau bestehend aus auf dem Markt verfügbaren vorgefertigten Modulen, Referenzdesign V5 | Nein | ca. 15 € bis 30 € je nach Aufbau etc. | Löten etc. notwendig, Tiefes Elektronik Verständnis notwendig, keine Ethernet Schnittstelle möglich.

Im Weiteren sind diese Optionen detaillierter beschrieben.

### 3.1 CAN-Gateway development board (Empfohlen)

Siehe http://wled.shop/wp-content/uploads/2021/11/CAN_Gateway_Nutzungsinformationen.pdf

Das ist die empfohlene Variante. Die CAN-Gateway Software kann auf diesem Board sehr leicht mit weniger Klicks ohne spezielle Kenntnisse installiert werden. Hat Ethernet Schnittstelle, "Plug-and-Play" CAN RJ45 Schnittstellen, Mikro-SD Slot, USB Interface, Gehäuse, DIP-Switch für CAN-Terminierung. Also nur Vorteile. Achtung: Zusatz-CAN-Interface bei diesem Board ist per default nicht bestückt: also spezieller BG02E Interface nur mit Zusatzbestückung möglich!

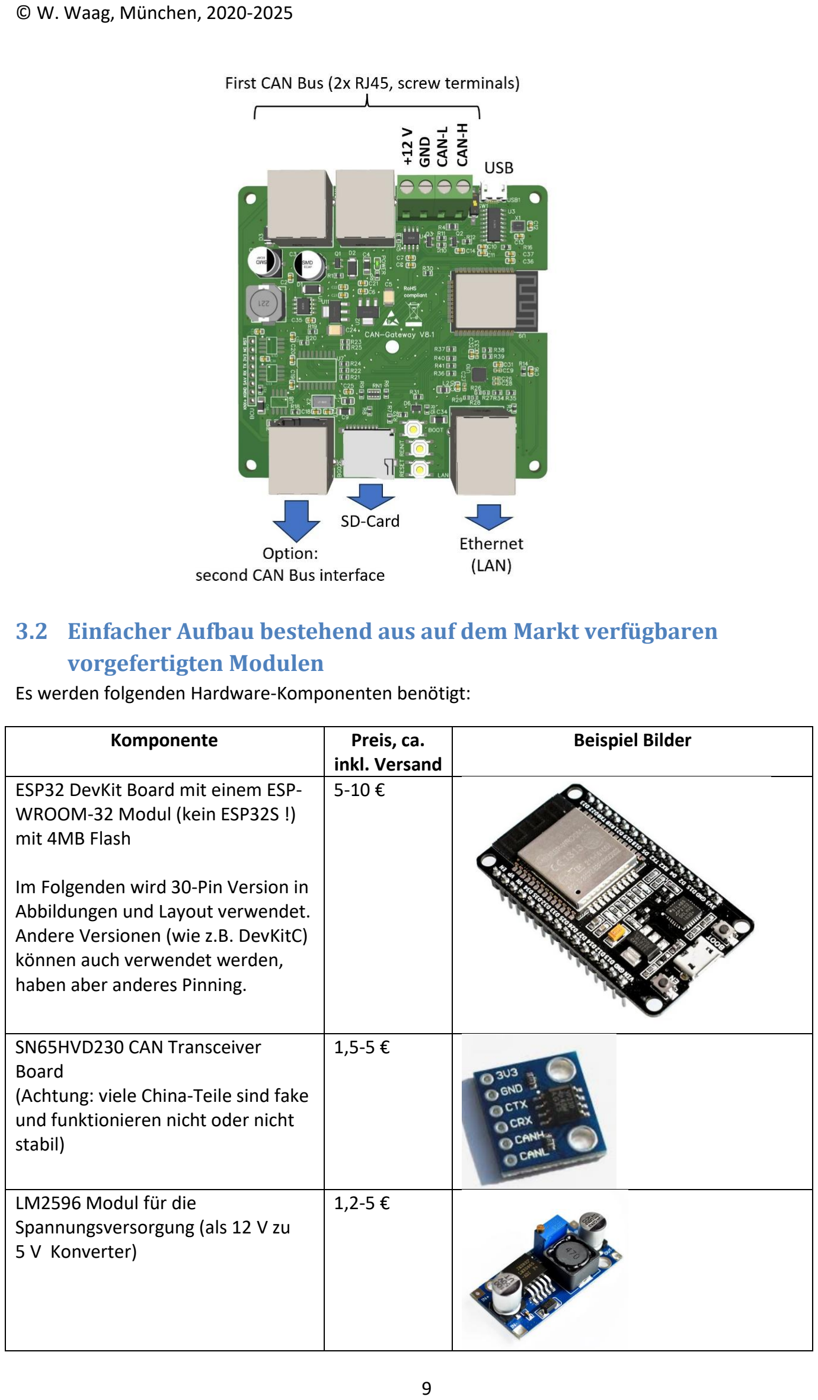
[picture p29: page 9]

### 3.2 Einfacher Aufbau bestehend aus auf dem Markt verfügbaren vorgefertigten Modulen

Es werden folgenden Hardware-Komponenten benötigt:

Komponente | Preis, ca. inkl. Versand | Beispiel Bilder
ESP32 DevKit Board mit einem ESP-WROOM-32 Modul (kein ESP32S !) mit 4MB Flash Im Folgenden wird 30-Pin Version in Abbildungen und Layout verwendet. Andere Versionen (wie z.B. DevKitC) können auch verwendet werden, haben aber anderes Pinning. | 5-10 €
SN65HVD230 CAN Transceiver Board (Achtung: viele China-Teile sind fake und funktionieren nicht oder nicht stabil) | 1,5-5 €
LM2596 Modul für die Spannungsversorgung (als 12 V zu 5 V Konverter) | 1,2-5 €

Ethernet Kabel mit RJ45 Stecker, abgeschnitten (oder Buchse, wenn man das Ganze auf einer Platine aufbaut)

2-5 €

Achtung! Es wird zwar Ethernet Kabel verwendet, das hat aber nichts mit der normalen LAN Kommunikation zu tun. Das Kabel darf nicht in einen Router oder ein PC eingesteckt werden!

Der Aufbau ist wie folgt. Achtung: LM2596 Modul sollte man zuerst mit Hilfe eines Multimeters auf die Ausgangsspannung von ca. 5 V einstellen. Dafür dreht man die Schraube an dem einstellbaren Widerstand (hellblau im Bild). ESP32 Modul kann zwar kurzzeitig auch mit 12 V funktionieren, wird jedoch sehr warm und kann auf Dauer beschädigt werden.

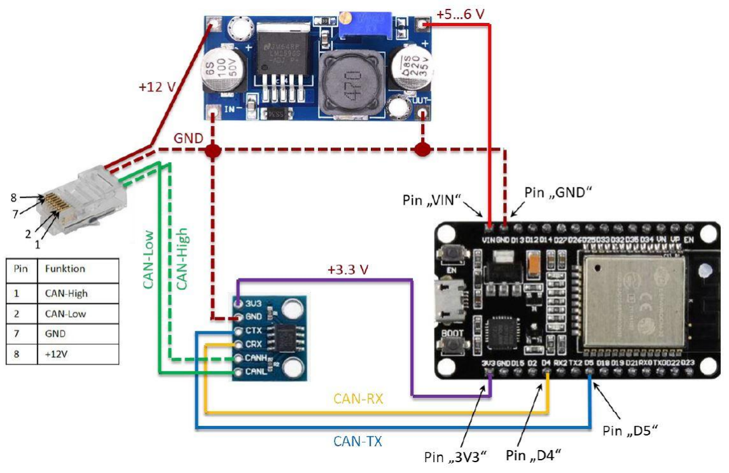
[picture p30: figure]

Wichtige Hinweise

1) GND Pin an RJ45: es kann sein, dass an einigen Geräten nur Pin3 und nicht Pin7, oder beide Pins 3 und 7 als GND verwendet werden. Ich würde empfehlen beide Pins (3 und 7) zusammen mit GND zu verbinden.
2) zum CAN-Bus: CAN-Bus muss beidseitig terminiert werden. Die Geräte von Hoval sind normalerweise bereits terminiert. SN65VHD230 Boards sind normalerweise auch terminiert. Also den Aufbau wie hier kann man normalerweise direkt in die RJ45 Buchse vom Gerät einstecken. Wenn man bereits mehrere Geräte in einem gemeinsamen CAN-Bus hat (z.B. Lüftungsgerät und ein Bedienmodul dazu), dann darf man den Aufbau wie oben nicht direkt verwenden:
- Zu einem hat man dann vermutlich keine freie Buchse, wo man RJ45 Stecker von CAN-Gateway reinstecken kann. Dafür kann man z.B. am CAN-Gateway noch einen zweiten RJ-45 Stecker dazu anlöten und dann einen davon z.B. in das Lüftungsgerät und den anderen in den Bedienmodul einstecken.
- Zu anderem muss man ein Terminierwiderstand entfernen. Am Bedienmodul kann man auch Terminierwiderstand mit zwei DIP-Schaltern auf der Rückseite abschalten. Andere Geräte haben oft diese DIP-Schalter nahe zum CAN-Anschluss und markiert als „R-CAN“. Im Zweifelsfall muss man mit einem Multimeter den Widerstand zwischen CAN-High und CAN-Low Leitungen messen. Es muss ca. 60 Ohm sein, wenn alle Geräte am CAN-Bus angeschlossen sind. Ist der Widerstand deutlich kleiner als 60 Ohm, dann ist CAN „überterminiert“ und man muss eine oder mehrere Terminierwiderstände entfernen und dann noch mal messen. Ist der Widerstand deutlich größer als 60 Ohm, dann ist CAN

„unterterminiert“ und man muss eine oder mehrere Terminierwiderstände dazu schalten und dann noch mal messen. Für mehr Details dazu lesen Sie bitte die Beschreibung zum CAN-Busen (z.B. auf Wikipedia etc.)
- Stromversorgung: man kann CAN-Gateway auf zwei alternativen Wegen versorgen:
- Über 12 V Leitung des Hoval CAN-Busses (empfohlen). Alle Hoval-Hauptsteuergeräte stellen 12 V zur Verfügung. Es dient z.B. zur Stromversorgung der Raumbedienmodule. CAN-Gateway kann sich auch aus dieser 12 V Leitung versorgen und verbraucht nicht mehr als ein Raumbedienmodul. Vorteil: man braucht keine separate Stromversorgung.
- Über Micro-USB Anschluss des ESP32 Boards (optional). Hat man bereits viele Raumbedienmodule, die sich aus 12 V CAN-Bus Leitung versorgen (bitte prüfen Sie Ihre Hoval Dokumentation wie viele Module maximal versorgt werden können), kann man CAN-Gateway über ein Micro-USB Netzteil (5 V / 0,5 A reichen, bitte nur gute qualitative Teile verwenden) versorgen. In diesem Fall darf man die 12 V Leitung zu Hoval Geräten nicht verwenden, also z.B. die entsprechende Litze im RJ-45 Kabel trennen. GND-Leitung muss aber (neben CAN-High und CAN-Low natürlich) unbedingt verbunden bleiben.

Man kann auch eine RJ45 Buchse verwenden und die einzelnen Module auf einer PCB z.B. so einordnen (hier Screenshots aus KiCad). Hier ist ein Beispiel mit zwei RJ45 Buchsen.

Beispiel fertiges Board mit einem zusätzlichen Schraubverbinder:

### 3.3 Hardware „CAN-Gateway Version 5“

Hardware „CAN-Gateway Version 5“ ist eine Referenzhardware für Eigenbau basierend auf dem einfachen Aufbau mit einem zusätzlichen Micro- SD-Kartenslot:

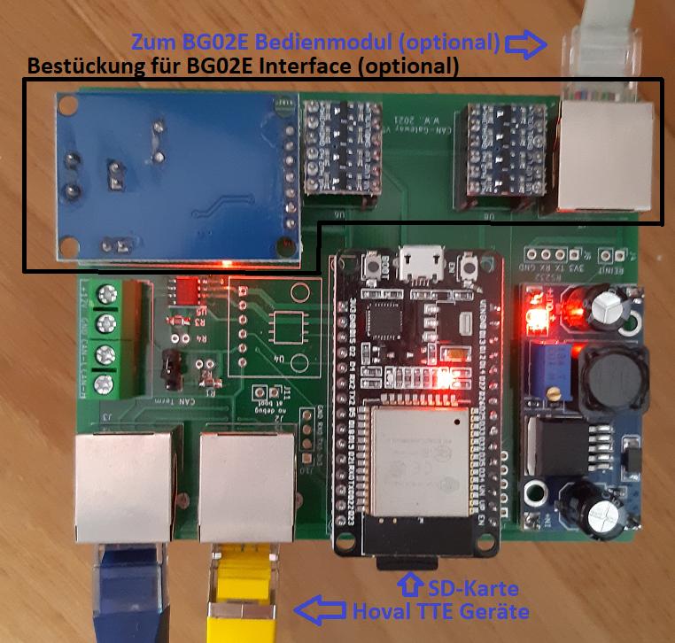
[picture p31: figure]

### 3.4 Nutzung ESP32-EVB(-EA) Entwicklungsboards von Olimex als CAN-Gateway

Firma www.olimex.com bietet ein Entwicklungsboard ESP-32-EVB(-EA), welches als CAN-Gateway Hardware verwendet werden kann [neu seit SW Version 28.001]:

Vorteile des Olimex Boards gegenüber CAN-Gateway HW V5:

- Ethernet (LAN) als Alternative zu WLAN (Erstkonfiguration erfolgt immer über WLAN, dann kann aber auf Ethernet/LAN umgestellt werden)
- -EA -Version mit externer WLAN-Antenne
- Metallisches Gehäuse ist bei Olimex für die -EA -Version erhältlich

Nachteile des ESP32-EVB(-EA) Boards im Vergleich zum CAN-Gateway HW V5:

- Keine RJ45-Stecker für Hoval CAN-Bus, nur Schraubklemmen
- SD-Karte: kein automatisches Montieren/Demontieren beim Einstecken/Auswerfen im laufenden Betrieb
- Externe Stromversorgung erforderlich, keine Möglichkeit zur Stromversorgung über Hoval CAN-Bus
- Keine BG02E-Schnittstellenoption

Anschlüsse:

### 4 Software flashen

### 4.1 Automatisiert (empfohlen)

Die DEMO Version der Software kann ganz leicht über den Web-basierten Installer installiert werden: https://wladwnt.github.io Die DEMO Version kann später auf die erworbene Vollversion über WEB-Interface des CAN-Gateways upgedatet werden.

### 4.2 Automatisiert (empfohlen), nur für CAN-Gateway development board

CAN-Gateway development board von wled.shop wird mit einer Software ausgeliefert, die erlaubt andere Software darauf über Web-interface ganz leicht zu flashen. So kann CAN-Gateway Demo oder Vollversion darauf ganz leicht mit nur wenigen Klicks installiert werden.

### 4.3 Manuell

Die Software wird als eine binäre Datei ausgeliefert und muss zuerst auf ESP32 Mikrocontroller geflasht werden. Dafür muss wiederum zunächst das Board mit dem Rechner über USB Kabel verbunden und der Treiber für den Kommunikationschip muss installiert werden. Insgesamt folgende Schritte sind erforderlich (angenommen, Sie nutzen Windows 10):

1) Den benötigten Treiber herausfinden. Die meisten ESP32 basierte Boards verwenden einen CP210x USB-Kommunikationschips. Den Treiber dafür findet man hier: https://www.silabs.com/products/development-tools/software/usb-to-uart-bridge-vcpdrivers (https://www.silabs.com/products/development-tools/software/usb-to-uart-bridge-vcp-drivers)

Olimex Boards und einige anderen haben CH340 USB-Kommunikationschips. Den Treiber dafür findet man hier: http://www.wch-ic.com/downloads/CH341SER_EXE.html
2) Den Treiber herunterladen und auf Ihrem PC/Laptop installieren.
3) PC neu starten.
4) Schauen Sie, welche COM-Ports in Ihrem System bereits vorhanden sind. Unter Windows 10 geht es so:
a. Geräte-Manager öffnen (rechter Mausklick auf Windows Symbol und dann auf Geräte-Manager klicken).
b. Im Geräte-Manager auf Anschlüsse (COM & LPT) gehen und die Liste anschauen.
5) ESP32 DevKit Board mit dem PC/Laptop verbinden. Dabei wird ein neuer virtueller COM-Port eingerichtet.
6) Im Geräte-Manager erscheint dann ein neuer Port (z.B. COM6), diesen Namen bitte merken.

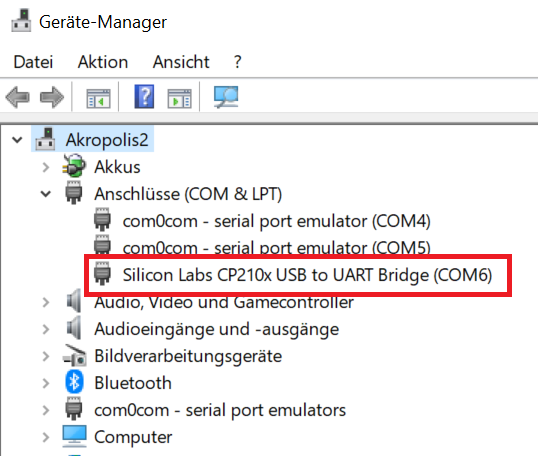
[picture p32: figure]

7) Erstellen Sie ein Verzeichnis auf dem Laufwerk C:, z.B. C:\CGW. Sie können es auch anders benennen, müssen aber dann in weiteren Schritten überall den richtigen Namen verwenden.
8) Herunterladen und entpacken Sie ESP Download Tool in dieses Verzeichnis (https://www.espressif.com/en/support/download/other-tools, dann unter „Flash Download Tools“)
9) Entpacken Sie die CAN-Gateway Software (die Datei „CAN_Gateway.ino.bin“ (bzw. „CAN_Gateway_DEMO.ino.bin“ für DEMO Version)
10) Zudem müssen Sie noch die Dateien (bis einschließlich CAN-Gateway Version 29.101) „boot_app0.bin“ (Quelle:
https://github.com/wladwnt/wladwnt.github.io/blob/main/cangw/boot_app0.bin ), bootloader_qio_80m.bin (Quelle: https://github.com/wladwnt/wladwnt.github.io/blob/main/cangw/bootloader_qio_80m.bin ) in diesem Verzeichnis speichern und CAN_Gateway.ino.partitions.bin (Quelle: https://github.com/wladwnt/wladwnt.github.io/blob/main/cangw/CAN_Gateway.ino.partiti ons.bin). (https://github.com/wladwnt/wladwnt.github.io/blob/main/cangw/CAN_Gateway.ino.partitions.bin)
Ab CAN-Gateway Version 29.201 sind die entsprechenden Dateien https://github.com/wladwnt/wladwnt.github.io/blob/main/cangw/boot_app0_v202.bin,https://github.com/wladwnt/wladwnt.github.io/blob/main/cangw/CAN_Gateway.ino.partitions_v202.bin (https://github.com/wladwnt/wladwnt.github.io/blob/main/cangw/CAN_Gateway.ino.partitions_v202.bin) und https://github.com/wladwnt/wladwnt.github.io/blob/main/cangw/CAN_Gateway.ino.bootloader_v202.bin. (https://github.com/wladwnt/wladwnt.github.io/blob/main/cangw/CAN_Gateway.ino.bootloader_v202.bin)
11) Haben Sie bisher alles korrekt gemacht, haben Sie folgende Dateien:

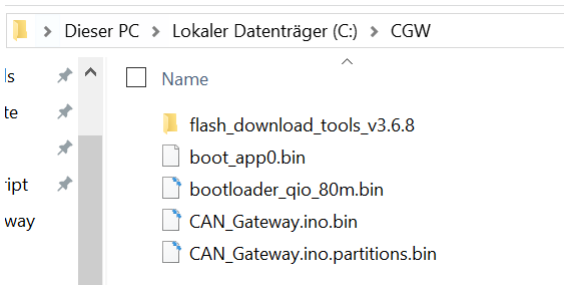
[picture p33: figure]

12) Nun können Sie ESP32 Download Tool starten (exe Datei aus dem Verzeichnis flash_download_tool_vX.X.X, wobei X.X.X die aktuelle Version ist, die Sie runtergeladen haben)
13) Dann erscheint ein Fenster, wo Sie ChipType „ESP32“ und WorkMode „develop “auswählen.
14) Im nächsten Dialog geben Sie die Daten ein, genauso wie hier im Bild zu sehen ist. Das einzige was Sie anpassen müssen, ist den richtigen COM-Port auszuwählen (unten rechts). Wen man Probleme beim Flashen hat, hilft evtl. auch wenn man die Baudrate niedriger wählt. Passen Sie auf, dass alle Hacken korrekt gesetzt sind. Danach könne Sie auf „Start“ unten links klicken. Der Flash-Vorgang beginnt.

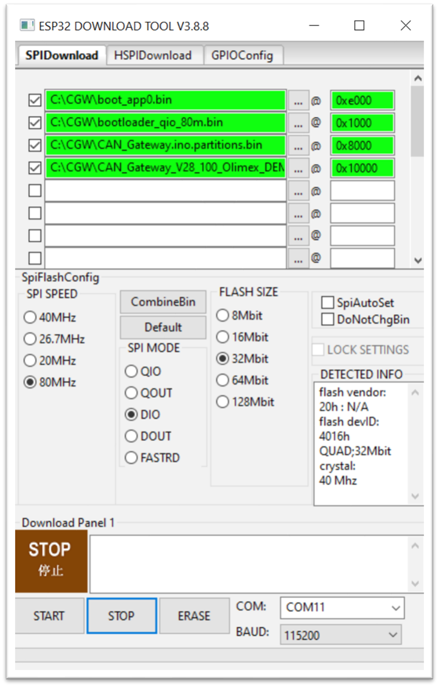
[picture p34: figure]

15) Sobald er beendet wird, erscheint unten im grünen Feld „Finish“. Flash Tool kann nun geschlossen werden. Alternativ zum Flashtool kann man auch die Programme wie esptool.exe oder esptool.py verwenden, die z.B. ein Bestandteil der Arduino Entwicklungsumgebung (mit installierten ESP32 Board-Erweiterungen) sind.

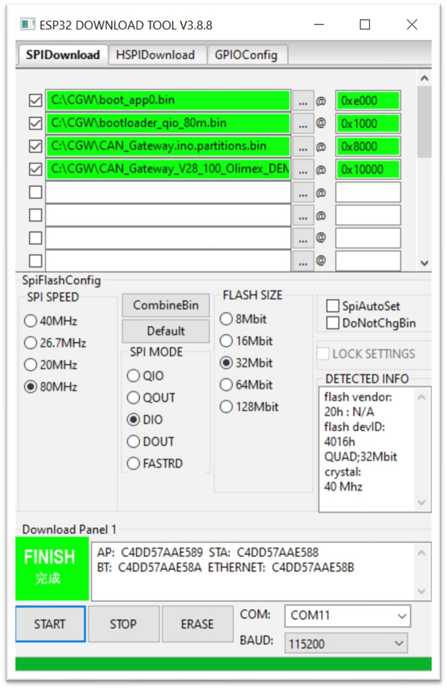
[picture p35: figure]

16) Nun kann man ESP32 DevBord neu starten, entweder indem man ihn vom USB Port entfernt und wieder einsteckt oder durch ein Reset Knopf auf dem Board.

Wenn man esptool.exe fürs Flashen verwendet, muss das Programm mit folgenden Parametern gestartet werden (COM-Port müssen Sie natürlich anpassen):

esptool.exe --chip esp32 --port COM6 --baud 256000 --before default_reset --after hard_reset write_flash -z --flash_mode dio --flash_freq 80m --flash_size detect 0xe000 C:\CGW/boot_app0.bin 0x1000 C:\CGW/bootloader_qio_80m.bin 0x10000 C:\CGW/CAN_Gateway.ino.bin 0x8000 C:\CGW/CAN_Gateway.ino.partitions.bin

### 5 Erste Inbetriebnahme

Im initialen Zustand, also wenn die Software zum ersten Mal auf das ESP32 DevKit geflasht wurde und CAN-Gateway gestartet wird, erzeugt CAN-Gateway einen WLAN Zugangspunkt (Access Point). Man muss ein PC/Laptop/Tablett mit diesem WLAN verbinden (WLAN Name: cangateway, Netzwerkschlüssel: 000999555), einen Internet Browser öffnen, zu der Startadresse gehen (z.B. http://cangateway.de eintippen) und die Einstellungen vornehmen. In Details sind folgende Schritte notwendig (hier angenommen, Sie haben Windows 10):

1) Stellen Sie sicher, dass Sie Ihre aktuellen WLAN Zugangsdaten kennen. Sie werden ihr PC im nächstens Schritt für eine Weile zu einem anderen Netzwerk verbinden müssen, danach müssen Sie aber zurück ins Ihr Heimnetzt und das wird ggf. erfordern, dass Sie Ihre Zugangsdaten (Password) eingeben müssen.
2) Klicken Sie auf der Windows-Leiste unten rechts auf WLAN Symbol, im geöffneten Fenster suchen Sie nach dem Netzwerk „cangateway“, klicken Sie drauf und dann auf „Verbinden“.

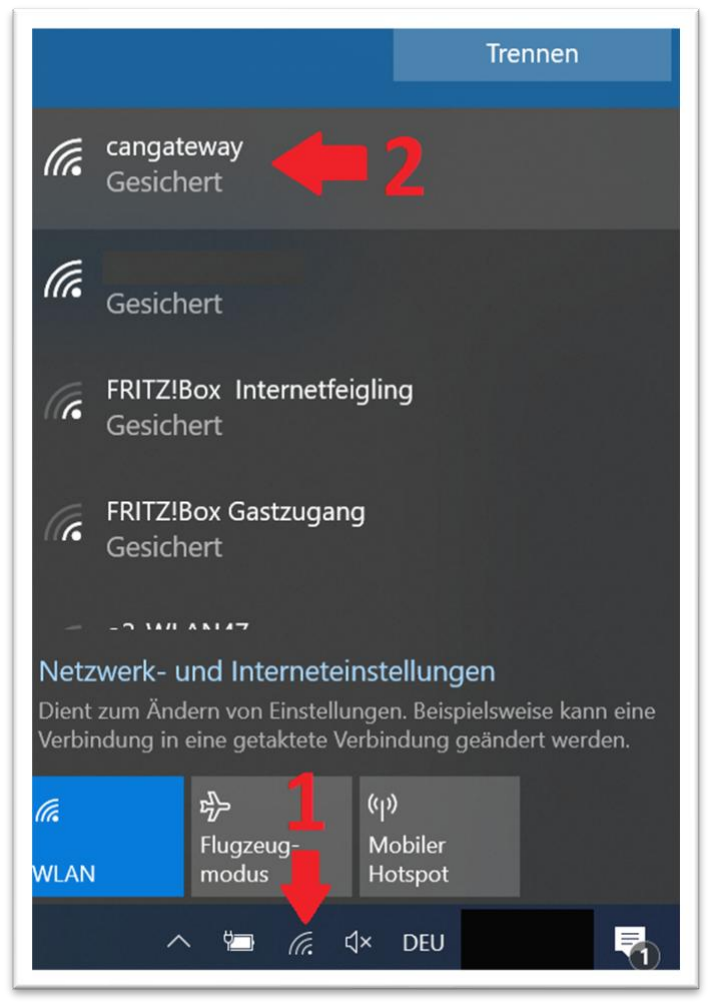
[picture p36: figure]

3) Es werden Netzanforderungen überprüft, danach müssen Sie den Netzwerkschlüssel 000999555 eingeben und auf „Weiter“ klicken.
4) Warten Sie bis die Verbindung zustande kommt und unter „cangateway “ erscheint „Kein Internet, gesichert“
5) Sie sind jetzt mit dem CAN-Gateway verbunden.
6) Öffnen Sie einen Web-Browser und in die Adresse-Leiste tippen Sie cangateway.de ein. Es wird die erste Seite geöffnet. Diese Seite befindet sich nicht wie üblich irgendwo im Internet, sondern wird vom CAN-Gateway erzeugt. Hier können Sie als erstes zwischen deutscher und englischer Sprache wählen.
7) Danach klicken Sie auf „Einstellungen“ und lesen dann aufmerksam die Nutzungsbestimmungen. Diese Nutzungsbestimmungen sind identisch zu den Angaben im Kapitel 1.1 „Gefahrenhinweise“ und 1.2 „Haftung des Softwareherstellers bzw. des Anbieters“ identisch. Sind Sie damit einverstanden, können Sie auf „Ich habe alle Gefahrenhinweise gelesen, akzeptiere die Bedingungen der Mängelhaftung und möchte weiter zu Einstellungen gehen“ klicken.
8) Auf nächster Seite klicken Sie zuerst auf „Aktuelle Einstellungen vom CAN-Gateway runterladen und anzeigen“. Als erstes können Sie Ihre Heim-WLAN Name und Password (Netzwerkschlüssel) eingeben (WiFi Name/Password). Alle andren Einstellungen können Sie erstmal so lassen wie es ist. Danach klicken Sie auf „Einstellungen speichern (auf CAN-Gateway hochladen) & Restart“. Jetzt könne Sie sich vom cangateway Netzwerk trennen und sich wieder mit Ihrem Heim-Netzwerk verbinden. Achtung: sobald Netzwerkname auf einen anderen als „cangateway“ geändert wird, geht die Software davon aus, dass es ein existierendes WLAN ist und erzeugt kein Access Point mehr.

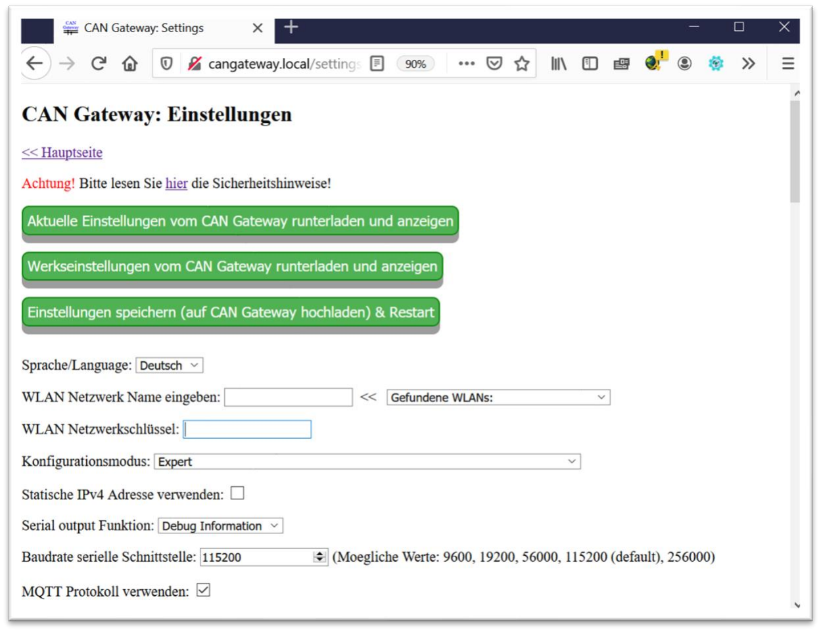
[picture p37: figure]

9) Nach Neustart versucht CAN-Gateway sich mit Ihrem Heim-netzwerk verbinden. Damit es funktioniert, muss Ihr WLAN Router unter anderem 2,4 GHz Band, 802.11 b/g/n Standard und WEP/WPA-TKIP/WPA2-CCMP sowie optional DHCP unterstützen (all das ist typisch für WLAN Netzwerke) und keine neuen Netzwerkteilnehmer blockieren (also nicht z.B. mach MAC-Adresse rausfiltern etc.). Nun Ist der CAN-Gateway mit Ihrem Heim-Netzwerk verbunden. Ich empfehle jetzt auch Ihren PC neu zu starten, damit der CAN-Gateway vom PC unter der Adresse http://cangateway.local gefunden werden kann. CAN-Gateway verwendet mDNS Protokoll. Windows 10 erkennt neue mDNS Geräte nur, wenn Bonjour servcie² installiert ist und nur nach Neustart. iOS und Linux müssten es sofort erkennen. Sie können nun also wieder Web-Browser öffnen und http://cangateway.local als Adresse eingeben. Mit Firefox funktioniert es bei mir, mit Chrome aber z.B. nicht, weil Chrome Browser versucht cangateway im Internet über Google zu suchen, es ist aber ein lokaler Web-Server. Sollte die Adresse http://cangateway.local nicht funktionieren, weil z.B. Ihr Betriebssystem oder Browser mDNS Protokoll nicht unterstützt, müssen Sie über Ihr Router die IPv4 Adresse vom CAN-Gateway ermitteln. Wenn Sie als Router z.B. Fritzbox haben, können sie auch einfach http://cangateway (für CAN-Gateway Software ab Version 19.001) oder http://espressif (für CAN-Gateway Software vor Version 19.001) probieren.
[neu in SW 27.400] CAN-Gateway unterstützt SSDP Protokoll und wird in Windows unter „Netzwerk“ gelistet. Mit dem rechten Mausklick auf dem CAN-Gateway gelangt man zu „Eigenschaften“ und dort kann man die IP-Adresse des CAN-Gateways ablesen.

2 Wie man Bonjour service installiert, findet man z.B. hier: https://softwarekeep.com/help-center/what-isbonjour-service-on-windows-10. (https://softwarekeep.com/help-center/what-is-bonjour-service-on-windows-10) Nach der Installation PC/Laptop neu starten!

### 6 WEB-Interface: Hauptseite

CAN-Gateway besitzt ein WEB-Interface. Über dieses Interface sind verschiedene Funktionen wie Einstellungen, Liste der Parameter und gefundener Geräte, CAN-Datenlogger, Parameter-Datenlogger etc. verfügbar. WEB-Interface kann über die Adresse cangateway.local erreicht werden. Voraussetzung dafür allerdings, dass ihr PC/Laptop-Betriebssystem mDNS Protokoll unterstützt. Siehe dazu auch Schritt 8 in Kapitel „Erste Inbetriebnahme“. Web-Interface kann selbstverständlich auch direkt über IPv4 Adresse angesprochen werden.

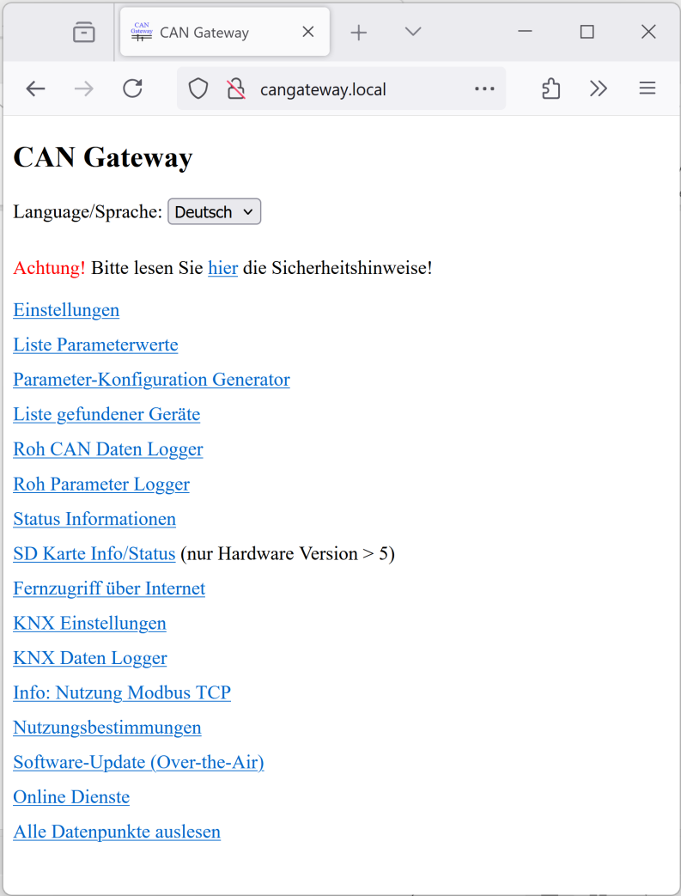
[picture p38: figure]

### 7 Allgemeine Informationen zu Geräte-Parametern

Als Parameter werden hier alle Werte gemeint, die aus den Geräten ausgelesen oder zwecks Ansteuerung eingestellt/geändert werden können. Als Beispiele können z.B. von den Geräten gemessenen Temperaturen, Leistungen, Geräte-Namen oder Sollwerte für Temperatur, Luft-Durchströmung etc. genannt werden. Verschiedene Geräte-Typen haben verschiedene Parameter, die man entweder nur auslesen oder auch einstellen (ändern) kann. Jeder Parameter, auch „Datapoint“ genannt, hat einen Datapoint-ID (also eine eindeutige Nummer), gehört zu einer bestimmten Funktion, die durch einen Funktionsnummer beschrieben wird, und die Funktion gehört einer bestimmten Funktionsgruppe. Da jedes Gerät durch den Gerätetyp und die Geräteadresse eindeutig identifiziert wird, ist jeder Parameter in einem konkreten Gerät in Summe durch 5 Eigenschaften (in Form von 5 Zahlen) eindeutig identifiziert wird: Gerätetyp, Geräte-Adresse, Funktionsgruppe, Funktionsnummer und Datapoint-ID:

- Gerätetyp: Eine Zuordnung der Gerätetypen zu entsprechenden Typ-Nummern ist auf der Seite mit CAN-Gateway Einstellungen (zugänglich über CAN-Gateway Webinterface) zu finden.
- Geräteadresse: Die Geräteadresse kann z.B. durch einen Bedienmodul (mit Touchscreen) eingesehen und im passenden User-Level Modus (siehe dazu User-Level Information) auch geändert werden. (Selbstverständlich auch durch CAN-Gateway möglich). Es gibt aber normalerweise keine Notwendigkeit die Adresse zu ändern, es sei denn, man will ein gleiches Gerät an CAN-Bus anschließen. Stadtartadresse ist wohl 8. Um die vorhandenen Geräte leichter zu identifizieren, Analysiert CAN-Gateway alle Informationen auf dem CAN-Bus und erzeugt eine Liste mit verfügbaren Geräten (inklusiv Gerätetyp und Geräte-Adresse), die dann über CAN-Gateway Webinterface eingesehen werden kann.
- Funktionsgruppe: Die Funktionsgruppe kann zu einem über den Bedienmodul eingesehen werden. Im Bereich „Service“ werden alle Geräte aufgelistet, die vorhanden sind, und dann für jedes Gerät sieht man die Funktionsgruppen, wobei in Klammern dann steht eine Zahl mit der Nummer der Funktionsgruppe. Funktionsgruppe steht auch auf der Liste der Parameter (Excel Datei, die vom Hersteller erhältlich ist und die durch offizielles Gateway vom Hersteller verfügbaren Parameter beschreibt).
- Funktionsnummer: Die Funktionsnummer kann wie die Funktionsgruppe über Bedienmodul (das ist die zweite Ebene nach der Funktionsgruppe) oder in Parameterlisten (Excel-Dateien vom Hersteller) eingesehen werden.
- Datapoint-ID: Datapoint-IDs können wie Funktionsgruppen und Funktionsnummern über Bedienmodul oder in Parameterlisten (Excel-Dateien vom Hersteller) eingesehen werden. Auf dem Bedienmodul ist das die (dezimale) Zahl die im Bereich „Service“ zwischen dem Parameter-Namen und Parameter-Wert in der Form XX-XXX in Grau angezeigt wird. Der Bindestrich muss dabei einfach ignoriert werden.

Alle Parameter, die aus Geräten ausgelesen werden können oder die eingestellt werden können, sind auf dem CAN-Bus grundsätzlich verfügbar. Auf dem CAN-Bus kann man auch auf die Parameter zugreifen, die dem Benutzer im Bedienmodul bei bestimmten User-Levels gar nicht angezeigt werden.

CAN-Gateway hat einen Logger, der alle Parameter, die auf dem CAN-Bus gerade übertragen werden, aufzeichnet und diese können dann über CAN-Gateway WEB-Interface angezeigt werden. Diese Funktion hat allerdings nur dann Sinn, wenn ein Bedienmodul oder ein Gateway im System vorhanden ist, da die Parameter nur auf die Anfrage auf dem CAN-Bus übertragen werden. Wenn auf dem CAN-Bus nichts übertragen wird, wird im Parameter-Logger vom CAN-Gateway auch nichts angezeigt. Parameter, die in den Einstellungen des CAN-Gateways konfiguriert sind, werden vom CAN-Gateway periodisch über CAN-Bus angefragt und wenn die Geräte antworten, erscheinen dann diese Parameter auch im Parameter-Logger.

Grundsätzlich gäbe es die Möglichkeit bei einem Gerät anzufragen, welche Parameter er besitzt. Das macht z.B. jeder Bedienmodul. Diese Funktion ist aber auf dem CAN-Gateway aktuell nicht implementiert.

### 7.1 Beispiel

Im folgenden Beispiel wird ein Parameter betrachtet, welches dem Bedienmodul gehört und die Zeit bis zum abdunkeln des Touchscreens vorgibt.

Da es um ein Parameter des Bedienmoduls habdelt, ist der Gerätetyp=16. Die Adresse des Bedienmoduls wird unter anderem im Bereich „Service“ in Klammern zu TTE-BM dargestellt, in diesem Beispiel ist die Adresse des Bedeinsmoduls = 8. Der Parameter ist in der Funktionsgruppe „Einstellungen“ mit dem Nummer=80 und in der Funktion „Helligkeit“ mit der Nummer=1. Datapoint-ID ist „00-001“, also auch =1. Der aktueller Wert ist 60s.

### 8 User-Levels

User-Level beschreibt die Zugriffsebene, also definiert unter anderem welche Parameter vom Benutzer über einen Bedienmodul ausgelesen und welche auch geändert werden können. Es gibt insgesamt 8 User-Levels: 0 bis 7. User-Level=0 ist der niedrigste (default), User-Level=7 gibt Schreibzugriff auf alles, praktisch unabhängig davon ob die Änderung bestimmter Werte überhaupt Sinn hat oder nicht. Jeder User-Level (außer 0) ist mit einem Password geschützt. Wichtig ist, dass User-Level sich eigentlich nur auf das beziehen, was auf dem Bedienmodul gemacht werden kann bzw. darf. Auf dem CAN-Bus ist alles verfügbar, also der CAN-Gateway kann generell unabhängig vom auf dem Bedienmodul eingestellten User-Level auf alles zugreifen und (Vorsicht!) alles ändern. CAN-Gateway kann auch ganz ohne Bedienmodul direkt mit einem Gerät funktionieren. Mit dem CAN-Gateway kann man sogar die Kennwörter für alle User-Levels aus dem Bedienmodul auslesen und diese auch ändern.

### 9 WEB-Interface: Einstellungen

Über WEB-interface des CAN-Gateways können verschiedene Einstellungen vorgenommen werden:

- Sprache
- [neu in SW 28.001] Auswahl WLAN oder Ethernet (LAN, nur bei Boards, die Ethernet unterstützen: aktuell Olimex ESP32-EVB(-EA) Entwicklungsboards)
- WLAN Netzwerkname und Netzwerkschlüssel
- Benutzung statischer IP Adresse für WLAN Netzwerk
- Funktion der seriellen Schnittstelle. Es gibt drei mögliche Funktionen zur Auswahl:
- CAN-Rohdaten – über serielle Schnittstelle (USB Anschluss) werden die empfangenen CAN Daten ausgegeben: CAN-ID, DLC, Daten-Bytes.
- Parameters - über serielle Schnittstelle (USB Anschluss) werden die empfangenen Parameter ausgegeben.
- Debug-Informationen: über serielle Schnittstelle (USB Anschluss) werden Informationen über den aktuellen Status des CAN-Gateways ausgegeben, was ggf. eine Fehlersuche erleichtert.
- Baudrate Serielle Schnittstelle
- MQTT Server IP, Server Port, Nutzername, Kennwort. Das muss den Einstellungen in Ihrem MQTT Brocker entsprechen.
- MQTT prefix. Das ist der allgemeine Teil für jedes Topic. Siehe dazu Kapitel „Übertragung der Parameter über MQTT Protokoll“.
- [neu ab SW 26.001] Unterstützung Home Assistant (https://www.home-assistant.io/) / MQTT Discovery (https://www.home-assistant.io/docs/mqtt/discovery/) für Sensoren
- Identifikation des CAN-Gateways auf dem CAN-Bus (Gerätetyp, Adresse).
- Einstellung, ob CAN-Gateway im Bedienmodul unter anderen Geräten aufgelistet und gesteuert werden kann (siehe Kapitel „Steuerung über Bedienmodul“).
- [neu ab SW Version 22.001] Zeitserver um Information über die aktuelle Zeit über NTP Protokoll zu erfragen
- [neu ab SW Version 22.001] Offset für die lokale Zeit ggü. UTC in Sekunden
- [neu ab SW Version 23.001] Profil, wie die historischen Parameterdaten in RAM gespeichert werden. Zur Auswahl stehen folgende Optionen:
- Über die letzten 6 Std.: ein Wert alle 5 Min.; über die letzten 6 Minuten: ein Wert alle 10 Sek.
- Über die letzten 12 Std.: ein Wert alle 10 Min.; über die letzten 6 Minuten: ein Wert alle 10 Sek.
- Über die letzten 24 Std.: ein Wert alle 20 Min.; über die letzten 6 Minuten: ein Wert alle 10 Sek.
- Über die letzten 24 Std.: ein Wert alle 20 Min.; über die letzten 36 Minuten: ein Wert pro Min.
- Über die letzten 3 Tage: ein Wert pro Std.; über die letzten 6 Minuten: ein Wert alle 10 Sek.
- Über die letzten 3 Tage: ein Wert pro Std.; über die letzten 36 Minuten: ein Wert pro Min.
- [neu ab SW 26.001, nur in Verbindung mit HW ab V5]: Speicherung auf SD-Karte mit folgenden Optionen bzgl. was muss gespeichert werden: Parameterwerte, CAN Rohdaten, Parameter Rohdaten.

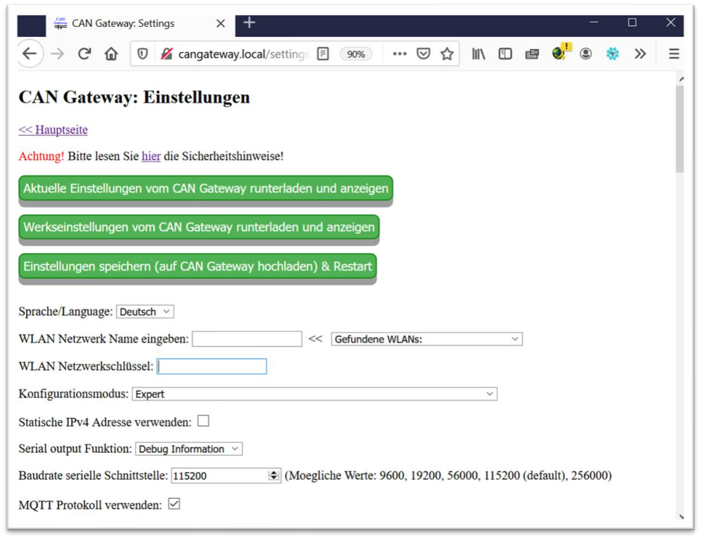
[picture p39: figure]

Bevor man die Parameter ändert, sollte man die aktuellen Einstellungen vom CAN-Gateway runterladen und anzeigen lassen. Danach kann man die Parameter anpassen und auf „Einstellungen speichern“ klicken. Speichern bedeutet, dass CAN-Gateway die Einstellungen im internen nichtflüchtigen elektronischen Speicher speichert und neu startet.

### 10 WEB-Interface: Parameter Einstellungen

Damit der CAN-Gateway die Parameter aus den Geräten ausliest/ändert und diese an Hausautomatisierungssystem überträgt, müssen die Parameter konfiguriert werden. Maximal können 40 (20 bis SW Version 22.001) Parameter konfiguriert werden.

Zur Konfiguration eines Parameters gehören folgende Angaben:

- Gerätetyp, Geräteadresse, Funktionsgruppe, Funktionsnummer, Datapoint-ID – siehe dazu die Beschreibung im Kapitel „Allgemeine Informationen zu Geräte-Parametern“.
- Datentyp – siehe dazu die Beschreibung im Unterkapitel „Datentypen“.
- MQTT Topic – siehe dazu die Beschreibung im Kapitel „Übertragung der Parameter über MQTT Protokoll“.
- Update-Rate. Update Rate kann die Werte 10, 30 oder 60 annehmen und gibt die Periode in Sekunden an, wie oft CAN-Gateway den Parameter bei dem entsprechenden Gerät anfragt. Normalerweise antwortet das Gerät sofort mit dem aktuellen Wert. Dieser Wert wird dann um ca. 100 ms verzögert an den MQTT Brocker aktiv gesendet (published) und steht dann auch zur Abholung über REST-API oder über Modbus-TCP Protokoll bereit. Publishing über

MQTT-Protokoll findet unabhängig davon statt, ob der Wert sich geändert hat oder nicht. Anzumerken ist, dass immer, wenn ein Parameter über CAN-Bus übertragen wird, wird sein Wert von CAN-Gateway erfasst und über MQTT publiziert. Also wenn z. b. andere Geräte den Wert öfter Anfragen als die Update-Rate, wird der Wert auch öfter über MQTT publiziert. CAN-Gateway erzeugt auch die Anfrage nur dann, wenn seit letzter Erfassung eines Parameters mehr Zeit vergangen ist, als über Update-Rate eingestellt ist. Der alter eines Wertes kann über WEB-Interface des CAN-Gateways auf der Seite „Liste der Parameter“ eingesehen werden.
- Lesen/Schreiben (read/write) Attribut. Ein Parameter kann nur zum Lesen (Attribut=r) oder zum Lesen und Ändern (Attribut=w) definiert werden. Wenn ein Parameter mit dem Attribut „w“ definiert wird, kann über WEB-Interface, über MQTT Protokoll, über REST-API oder über Modbus-TCP eine Änderungsanfrage erzeugt werden. Diese Anfrage wird dann vom CAN-Gateway an das Gerät weitergeleitet. Normalerweise bestätigt das Gerät die Änderung, indem er den geänderten Parameterwert zurück schickt. Das wird wiederum vom CAN-Gateway als Parameterübertragung auf dem CAN-Bus erfasst, über MQTT publiziert etc. Da die ganze Kette von der Änderungsanfrage bis zu Bestätigung der Änderung etwas dauert, muss das HAS nach einer Änderungsanfrage etwas warten, bis man den geänderten Wert zurück lesen kann und damit feststellen kann, ob die Änderung umgesetzt wurde. 0,5 s sollte normalerweise reichen, empfohlen wäre 1 s. ein HAS kann die Änderungsanfrage grundsätzlich so oft erzeugen wie es will, CAN-Gateway leitet die Änderungsanfrage an das Gerät maximal einmal pro 3 Sekunden. HAS sollte so programmiert werden, dass sie auch eine Änderungsanfrage nicht zu oft erzeugt. Sonst kann es theoretisch passieren, dass der Prozessor des CAN-Gateways zu stark ausgelastet wird und das ganze System abstürzt bzw. nicht mehr korrekt funktioniert.
- Koeffizient/Offset. Diese Vorgaben müssen immer vorhanden sein, sind aber nicht für Datentypen STR und RAW relevant (in diesem Fall können beliebig sein, z.B. 0/0). Koeffizient und Offset beeinflussen das, wie der auf dem CAN-Bus in binärform übertragene Wert in einen Wert umgerechnet wird, welcher dann über WEB-Interface einsehbar ist, über MQTT Protokoll übertragen wird und über REST-API ausgelesen werden kann. Die Ausnahme dabei ist Modbus-TCP Protokoll, hier werden die Werte immer genau so übertragen wie auf dem CAN-Bus und die ggf. notwendige Umrechnung muss auf dem Modbus-Master stattfinden. Sonst gilt, dass der auf dem CAN-Bus übertragener Wert erst mit dem Koeffizient multipliziert wird und dann dazu ein Offset addiert wird. Der Koeffizient und der Offset können ganzzahlig oder nicht sein, positiv oder negativ. Bei Änderungsanfragen ist die Umrechnung umgekehrt, also wird aus dem für die Änderung eingesteuerten Wert der Offset subtrahiert und dann wird das Ergebnis durch Koeffizient dividiert. Das Ergebnis wird dann in Binärform über CAN-Bus an das Gerät übertragen. Diese Umrechnungen sind deswegen notwendig. Die notwendigen Einstellungen für Koeffizient/Offset kann man rausfinden entweder indem man die Werte, die CAN-Gateway rausgibt mit den auf dem Bedienmodul angezeigten Werten vergleicht oder wenn man die vom Hersteller zur Verfügung gestellten Parameterlisten studiert. Offset ist fast immer (oder wirklich immer?)=0. Koeffizient muss man in Abhängigkeit von der Anzahl der Dezimalstellen (Spalte „Decimal“ in diesen Listen) einstellen. Wenn da der Wert 0 steht, dann ist der Koeffizient=1. Bei Decimal=1 ist der Koeffizient=0.1 (öfter bei Temperaturen), bei Decimal=2 ist der Koeffizient=0.01 und bei Decimal=3 ist der Koeffizient=0.001.

Die Parameter werden auf der Seite „Einstellungen“ des WEB-Interfaces konfiguriert. Dazu wird im Feld Parametereinstellungen für jeden Parameter eine Zeile eingetragen, die mit „param=“ beginnt. Danach kommen die Konfigurationsdaten, jeweils getrennt durch ein Semikolon. Insgesamt können bis zu 40 Parameter (bis SW Version 22.001 nur 20 Parameter) konfiguriert werden. Unter diesem

Feld ist auch eine kurze Beschreibung aller Konfigurationsdaten gegeben. In diesem Beispiel im Bild werden 9 Parameter konfiguriert. Die ersten 7 davon sind die User-Level Passwörter, die aus dem Bedienmodul ausgelesen werden. Dann wird noch ein Parameter „Zeit bis zum Abschalten“ im Bedienmodul konfiguriert (siehe Beispiel im Kapitel „Allgemeine Informationen zu Geräte-Parametern“). Und als letztes wird Status Parameter definiert (siehe Beispiel im Unterkapitel „Hinweise zu Listen“), allerdings als Rohdaten-Format (RAW, sinnvoller als Indes einer Liste wäre hier der Format „U8“).

Es gibt zwei Hilfswerkzeuge, um diese Konfigurationszeilen zu erzeugen ohne sich viel Gedanken über den Inhalt machen zu müssen. Zu einem ist ein in CAN-Gateway Software integrierter „Parameter-Konfiguration Generator“ (sieh nächstes Kapitel). Zum anderen gibt es eine erweiterte Datenbank der Parameter in Online Services, wo man für jedes Parameter auch eine korrekte Konfigurationszeile generieren kann.

### 10.1 Datentypen

Information über den Datentyp beeinflusst das, wie der in Binärform auf dem CAN-Bus übertragene Wert in einen Wert umgerechnet wird, welcher dann über WEB-Interface einsehbar ist, über MQTT Protokoll übertragen wird und über REST-API ausgelesen werden kann. Die Ausnahme dabei ist Modbus-TCP Protokoll, hier werden die Werte immer genau so übertragen wie auf dem CAN-Bus und die ggf. notwendige Umrechnung muss auf dem Modbus-Master stattfinden.

RAW: Der Wert wird in Hexadezimal Darstellung ausgegeben. Also z.B. wenn auf dem CAN-Bus ein Parameterwert als Reihenfolge von 4 Bytes 0x31 0x32 0x61 0x5A übertragen wird, wird das als eine Zeichenfolge „3132615A“ dargestellt. Maximale Byte-Anzahl ist 64.

STR: Der Wert wird als eine ASCII kodierte Zeichenfolge interpretiert. Also z.B. wenn auf dem CAN-Bus ein Parameterwert als Reihenfolge von 4 Bytes 0x31 0x32 0x61 0x5A übertragen wird, wird das als eine Zeichenfolge „12aZ“ dargestellt, weil 0x31 in ASCII Kodierung „1“ entspricht, 0x32=“2“, 0x61=“a“ und 0x5A=“Z“. Maximale Länger der Zeichenfolge ist 64.

U8 (unsigned 8-Bit): ein vorzeichenloser Byte, also ein Wert im Bereich 0 bis 255.

S8 (signed 8-Bit): ein vorzeichenbehafteter Byte, also ein Wert im Bereich -128 bis 127.

U16 (unsigned 16-Bit): ein vorzeichenloser Wort (2 Bytes), also ein Wert im Bereich 0 bis 65535.

S16 (signed 16-Bit): ein vorzeichenbehafteter Wort (2 Bytes), also ein Wert im Bereich -32768 bis 32767.

U32 (unsigned 32-Bit): ein vorzeichenloses doppeltes Wort (4 Bytes), also ein Wert im Bereich 0 bis 4294967295.

S32 (signed 32-Bit): ein vorzeichenbehaftetes doppeltes Wort (4 Bytes), also ein Wert im Bereich -2147483648 bis 2147483647.

[neu in SW 31.011] ERD: das ist ein spezieller Datentyp, der zusammen mit Datenpunkten verwendet werden kann, welche Informationen über aktuellen Fehlern im System beinhalten (Datenpunkte „Aktiver Fehler“ 1 bis 6, IDs 29042 bis 29046.). Diese Datenpunkte beinhalten in RAW-Format eine hexadezimale Byte-Folge, wo verschiedenen Informationen über den Fehler kodiert sind. Diese Reihenfolge kann mithilfe von Fehler Decoder (siehe Online Services) decodiert werden. Wenn man den oben erwähnten Datenpunkten anstatt RAW als Datentyp RED einstellt, dann zeigt CAN-Gateway anstatt der hexadezimale Byte-Folge die Fehlerbeschreibung als Klartext in Deutsch.

[neu in SW 31.011] ERE: das gleiche wie ERD, jedoch ist die Fehlerbeschreibung in English.

Die Bereiche oben sind ohne Berücksichtigung der eingestellten Koeffizient/Offset.

### 10.2 Hinweise zu Listen

Einige Parameter sind als sogenannten Listen definiert. Eine Liste in diesem Sinne ist eine Zuordnung von Nummern 0, 1, 2, … usw. zu jeweils einer bestimmten Bedeutung, die zum Beispiel durch ein Wort oder eine Phrase beschrieben wird. Als Beispiel kann Helligkeit-Modus am Bedienmodul betrachtet werden. Der Parameter Helligkeit-Modus gehört zu Funktionsgruppe 80, Funktionsnummer 1 und hat Datapoint-ID = 0. Am Bedienmodul können verschiedene Modi gewählt werden, wie z.B. „Zeitgesteuert“. Über CAN-Bus wird als Parameter jedoch nicht das Wort „Zeitgesteuert“ übertragen, sondern diesem Wort entsprechende Zahl=2. Wenn man den Modus ändern will, muss man dem Modus entsprechende Zahl kennen und diese als Änderung einsteuern.

### 10.3 Beispiele

### 10.3.1 Beispiel 1: Komfortlüftung – Feuchte Sollwert auslesen und einstellen

Folgende Zeile ist ein Beispiel, um den aktuellen Sollwert für die Feuchte in einem HomeVent Gerät auslesen und einzustellen (Gerätetyp=8; Geräteadresse=8, Funktionsgruppe=50; Funktionsnummer=0; Datapoint-ID=40687; Lesen und Schreiben (w); MQTT topic=feuchte_sollwert; Auslesen jede 10s; Datentyp: U8; Koeffizient=1; Offset=0):

param=8;8;50;0;40687;w;feuchte_sollwert;10;U8;1.000000;0.000000;

### 10.3.2 Beispiel 2: Komfortlüftung – Temperatur Abluft

Folgende Zeile ist ein Beispiel, um die aktuelle Abluft Temperaturn auszulesen (Gerätetyp=8; Geräteadresse=8, Funktionsgruppe=50; Funktionsnummer=0; Datapoint-ID=37602; nur Lesen (r); MQTT topic=temp_abluft; Auslesen jede 10s; Datentyp: S16; Koeffizient=0.1; Offset=0):

param=8;8;50;0;37602;r;temp_abluft;10;S16;0.100000;0.000000;

### 10.3.3 Beispiel 3: Komfortlüftung – Temperatur Außenluft

Folgende Zeile ist ein Beispiel, um die aktuelle Außenluft Temperaturn auszulesen (Gerätetyp=8; Geräteadresse=8, Funktionsgruppe=50; Funktionsnummer=0; Datapoint-ID=0; nur Lesen (r); MQTT topic=temp_aussen; Auslesen jede 10s; Datentyp: S16; Koeffizient=0.1; Offset=0):

param=8;8;50;0;0;r;temp_aussen;10;S16;0.100000;0.000000;

### 10.3.4 Beispiel 4: Raumbedienmodul – Kennwort für UserLevel 7 lesen/ändern

Folgende Zeile ist ein Beispiel, um den Kennwort für UserLevel=7 aus dem Bedienmodul auszulesen und zu ändern (Gerätetyp=16; Geräteadresse=8, Funktionsgruppe=89; Funktionsnummer=1; Datapoint-ID=7; Lesen und Ändern (w); MQTT topic=password_level7; Auslesen jede 60s; Datentyp: STR; Koeffizient=1 und Offset=0 können beliebig sein, da irrelevant):

param=16;8;89;1;7;r;password_level7;60;STR;1;0;

### 10.3.5 Beispiel 5: Komfortlüftung – Betriebsmodus

Folgende Zeile ist ein Beispiel, um den Betriebsmodus auszulesen und zu ändern (Gerätetyp=8; Geräteadresse=8, Funktionsgruppe=50; Funktionsnummer=0; Datapoint-ID=40650; Lesen und Ändern (w); MQTT topic=password_level7; Auslesen jede 60s; Datentyp: U8; Koeffizient=1 und Offset=0):

param=8;8;50;0;40650;w;betriebswahl_lueftung;60;U8;1.000000;0.000000;

Betriebsmodus wird durch die Nummer 0 bis 5 kodiert. Laut dieser Datei (http://www.hoval.com/misc/TTE/TTE-GW-Modbus-datapoints.xlsx) sind folgende Modi möglich (gleiche Liste sieht man über Bedienmodul): Standby=0, Woche 1=1; Woche 2=2; Konstant=4; Sparbetrieb=5.

### 10.3.6 Beispiel 6: Komfortlüftung – Datum/Uhrzeit

Folgende zwei Zeilen sind ein Beispiel, wie man Datum/Uhrzeit auslesen oder ändern kann:

param=8;8;0;0;2070;w;Datum;10;U16;1.000000;0.000000; param=8;8;0;0;2072;w;Uhrzeit;10;U16;1.000000;0.000000;

Dabei ist „Uhrzeit“ die Anzahl der Minuten seit Tagesbeginn; „Datum“ ist die Anzahl der Tage seit 1.1.1900 (Schaltjahre werden korrekt berücksichtigt).

### 11 WEB-Interface: Parameter-Konfiguration Generator

Dieser Generator hilft die Konfigurationszeilen für Parameter zu generieren. In einer Tabelle können aus Listen die Parameter ausgewählt werden und für diese werden dann Konfigurationszeilen generiert, die man dann kopieren und auf der Seite der Einstellungen einfügen und somit für die Konfiguration des CAN-Gateways nutzen kann. Die Auswahllisten beinhalten viele bekannten Parameter für die verschiedenen Geräte.

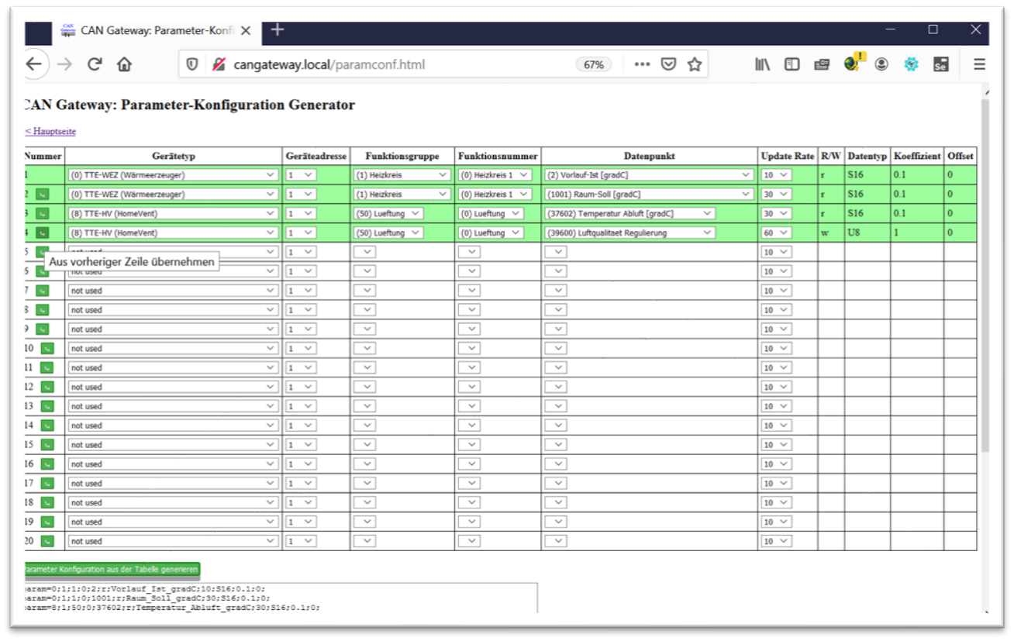
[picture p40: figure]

### 12 WEB-Interface: Liste der Parameter

Im WEB-Interface des CAN-Gateways gibt es die Möglichkeit, die konfigurierten Parameter anzeigen zu lassen und die Änderungsanfragen auch zu generieren. Diese Seite wird nicht periodisch upgedatet. Dafür muss man auf „Neu laden“ klicken. Um ein wert zu ändern (bzw. genauer gesagt eine Änderungsanfrage zu generieren), muss der neue Wert in das entsprechende grüne Feld eingegeben werden und dann muss man auf entsprechende Schaltfläche „Wert setzen“ klicken.

In SW seit Version 21.002 gibt es auch die Möglichkeit die historischen Werte der Parameter anzuschauen (als Tabelle und als Graph, siehe auch Kapitel „WEB-Interface: Einstellungen“). Dafür gibt es für jeden Parameter zwei kleine grüne Buttons „H“ und „P“:

Historische Daten werden für Parameter vom Typ STR und RAW nicht gespeichert.

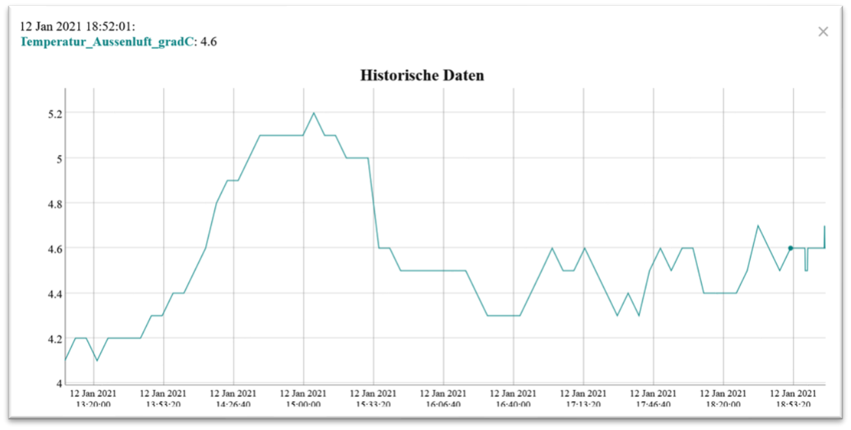
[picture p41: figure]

### 13 WEB-Interface: Liste der Geräte

Wenn ein Gerät auf dem CAN-Bus irgendwas sendet, wird es vom CAN-Gateway detektiert und er speichert das Gerät in der Liste der gefundenen Geräte, die dann über WEB-interface aufgerufen werden kann.

### 14 WEB-Interface: Status Informationen

Über WEB-Interface kann CAN-Gateway Status abgerufen werden, wo verschiedenen Informationen zusammengefasst sind, die bei Problemlösungen etc. helfen können.

### 15 WEB-Interface: SD Karte Info/Status

[neu ab SW 26.001, nur in Verbindung mit HW V5 und höher oder Olimex board]

Hier wird der aktuelle Status der SD-Karte angezeigt. SD-Karte kann grundsätzlich im laufenden Betrieb ein- und ausgesteckt werden. Es wird aber dringend empfohlen, vor dem ausstecken die SD-Karte „unmontieren“. Es werden SD und SDHC Micro SD-Karten unterstützt (keine SDXC!). Die SD-Karte muss vorher mit FAT32 formatiert werden.

Die Daten, wenn aktiviert, werden in Dateien gespeichert. Der Dateiname wird wie folgt gebildet:

Jahr_Monat_Tag_Stunden_Minuten_Sekunden_Konfigurationsnummer_0000.csv

Konfigurationsnummer ist einfach eine Zahl, die bei jeder Änderung der Konfiguration um 1 erhöht wird.

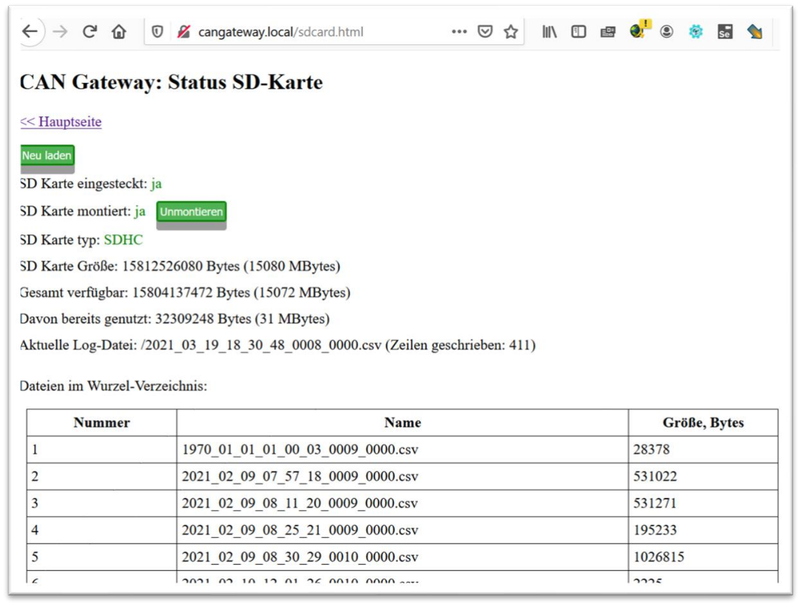
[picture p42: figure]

Der Format der Daten wird ist in den Einstellungen konfigurierbar.

### 16 WEB-Interface: CAN Datenlogger

Alle vom CAN-Gateway empfangenen CAN-Nachrichten können über Web-Interface angezeigt werden:

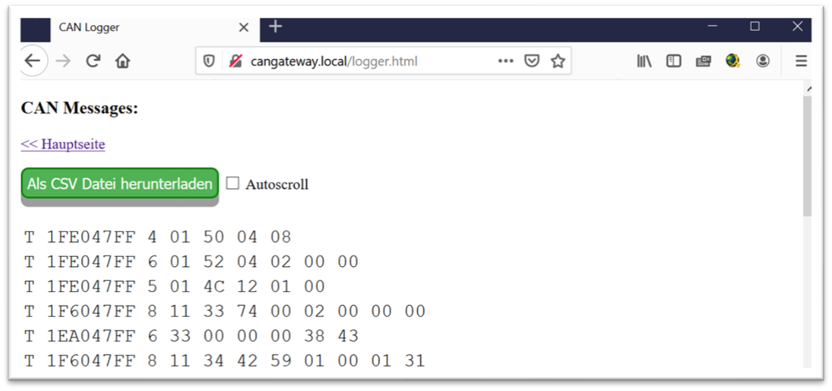
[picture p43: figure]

Die neuen Nachrichten werden automatisch jede 5 s nachgeladen und unten angehängt. Man kann alles in eine CSV Datei exportieren. Der erste Buchstabe „t“ oder „T“ bedeutet eine Standart- oder Extended-Frame. Danach folgt CAN-ID, DLC (Daten-Länge) und 1 bis 8 Datenbytes. Nur Daten-Nachrichten werden aufgezeichnet. RTR- und Error-Frames werden ignoriert.

### 17 WEB-Interface: Parameter Logger

Alle vom CAN-Gateway empfangenen Parameter können über Web-Interface angezeigt werden. (In diesem Beispiel sind die empfangenen User-Level Kennwörter geschwärzt.)

Die neu empfangenen Parameter werden automatisch jede 5 s nachgeladen. Man kann alles in eine CSV Datei exportieren.

### 18 WEB-Interface: KNX IP Einstellungen (ab SW 29.001)

CAN-Gateway unterstützt ab SW Version 29.001 KNX IP Multicasting (aktuell kein Tunneling, kein KNX IP Secure und nicht alle Datapoint Typen werden unterstützt).

Es wird auch dringend empfohlen MQTT Protokoll auszuschalten (in Haupteinstellungen), wenn KNX IP verwendet wird. Ansonsten kann wegen RAM Mangel am CAN-Gateway zu Problemen (reboots, WEB UI nicht erreichbar etc.) kommen.

Sie müssen dazu ein KNX IP Router haben (physikalisch oder knxd Dienst auf einem Linux Rechner). Die Einstellung der KNX IP Parameter erfolgt über CAN-Gateway Web-Interface und nicht via ETS Software. In ETS Software kann man CAN-Gateway als ein Dummy Gerät integrieren.

CAN-Gateway hat eine Option auf SERVICE_REQUEST Anfragen von ETS5 zu reagieren, so dass Sie KNX IP auch dann testen können, wenn Sie kein KNX IP Router / knxd installiert haben.

Wenn man sich mit KNX auskennt, dann sind die meisten Einstellungen selbsterklärend. Detaillierung ist nur für Parameter „Koeffizient“ und DPT (Datapoint Type) notwendig:

Koeffizient: sollte in meisten Fällen „1.0“ sein. Mit diesem Koeffizient werden die realen Werte multipliziert bevor diese über KNX IP gesendet werden. Von „1.0“ abweichende Werte können nach Bedarf in einigen Sondersituationen verwendet werden.

DPT: Es werden DPT(x,y) mit dem folgenden Haupttyp „x“ unterstützt:

- DPT(1,y) [1-Bit Boolean]
- DPT(5,y) [1-Byte unsigned]
- DPT(6,y) [1-Byte signed]
- DPT(7,y) [2-Byte unsigned]
- DPT(8,y) [2-Byte signed]
- DPT(9,y) [2-Byte double]

- DPT(12,y) [4-Byte long unsigned]
- DPT(13,y) [4-Byte long signed]
- DPT(14,y) [4-Byte double]

Der Nutzer kann generell jedem Parameter fei ein DPT zuordnen. Es wird empfohlen für physikalische Werte (wie Temperatur, Feuchtigkeit etc.) DPT(14, y) zu verwenden. Subtyp wird in aktueller Implementierung ignoriert, es erfolgt also z.B. keine dementsprechende Skalierung des Wertes, was aber in meisten Fällen ausreichend ist.

[neu in V 29.310] Es gibt die Option auszuwählen, wann die Sensorwerte über KNX vom CAN-Gateway gesendet werden:

- Immer
- Nur bei Änderung
- Nur bei Änderung und alle 5 Minuten
- Nur bei Änderung und alle 10 Minuten
- Nur bei Änderung und alle 30 Minuten

Unabhängig von der gewählten Option, werden die Werte einmal beim Starten/Reboot von CAN-Gateway gesendet sowie wenn CAN-Gateway wieder ans WLAN/LAN angebunden wird (z.B. nachdem LAN Kabel zeitweise abgesteckt wurde etc.).

Für jeden Parameter gibt es außerdem die Möglichkeit zu definieren, ob für Senden „bei Änderung“ auch eine Hysterese verwendet werden soll. Hysterese Tiefe von „0“ bedeutet, dass der Wert bei jeder Änderung neu gesendet wird. Hysterese Tiefe von „1“ bedeutet, dass die Änderung um einen Schritt ignoriert wird. Z.B. wenn zuletzt der Temperaturwert von 20.5 °C gesendet wurde, wird bei Temperaturerhöhung erst bei 20.7 °C neu gesendet, jedoch nicht bei 20.6 °C.

CAN-Gateway integriert ein KNX IP Datenlogger. Dort können die über KNX IP am CAN-Gateway ankommende KNX Nachrichten eingesehen werden. Die ausgehenden Nachrichten werden nicht angezeigt.

Um KNX zu testen bzw. zu sehen, was CAN-Gateway über KNX IP sendet, können Sie ein Gruppenmonitor oder ein Busmonitor in ETS6 nutzen.

### 19 WEB-Interface: Software Update

CAN-Gateway Software kann über WEB-Interface upgedatet werden.

DEMO Version kann auf eine vollfunktionsfähige Version upgedatet werden und auch umgekehrt.

Achtung: Software Bruch zwischen Version 29.101 und 29.200. Aufgrund geänderter Basissoftware, kann die Version 29.101 oder niedrigere NICHT per WEB-Interface auf die Software 29.200 oder höher upgedatet werden. Für Update bitte updaten Sie erst auf die neue DEMO-Version über den web-basierten Installer (https://wladwnt.github.io/) und dann kann die DEMO-Version per WEB-Interface auf Vollversion upgedatet werden. Das gleiche zwischen Version 30.xxx und 31.xxx

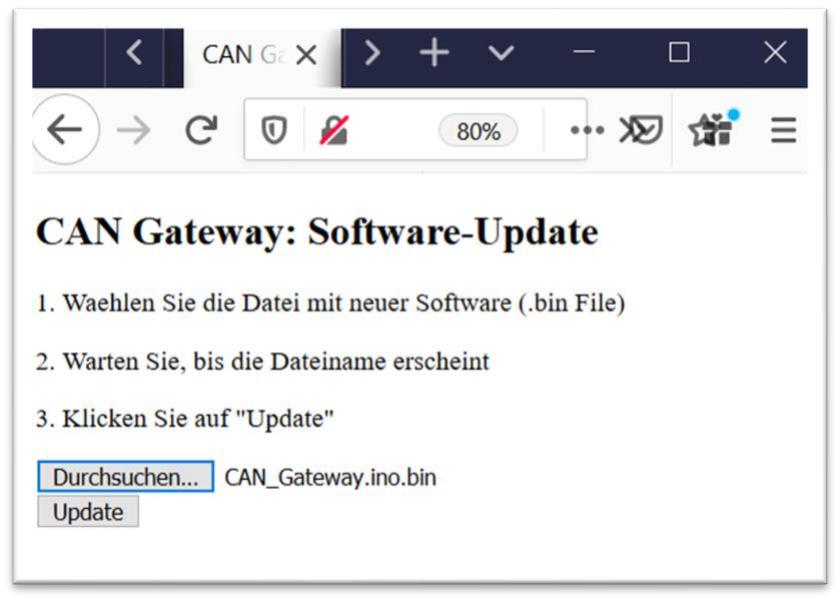
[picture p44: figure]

### 20 WEB-Interface: Alle Datenpunkte auslesen

[neu ab SW 30.020] Diese Funktion ermöglicht alle Datenpunkte eines Geräts (eines Reglers) auszulesen. Diese können dann in einer CSV-Datei gespeichert werden. So kann quasi ein Backup der Geräteparameter erstellt werden. Oder man kann dann die zwei Dateien von zwei Geräten vergleichen um herauszufinden, welche Unterschiede in Konfiguration beide Geräte haben.

Das Auslesen aller Datenpunkte kann recht lange dauern. Be einem TTE-WEZ Regler werden z.B. typischerweise ca. 1500 Datenpunkte ausgelesen.

Vor dem Starten lesen Sie bitte sehr genau die Hinweise zum Vorgang. Diese sind durch einen Klick auf „Bitte diese Hinweise lesen“ sichtbar.

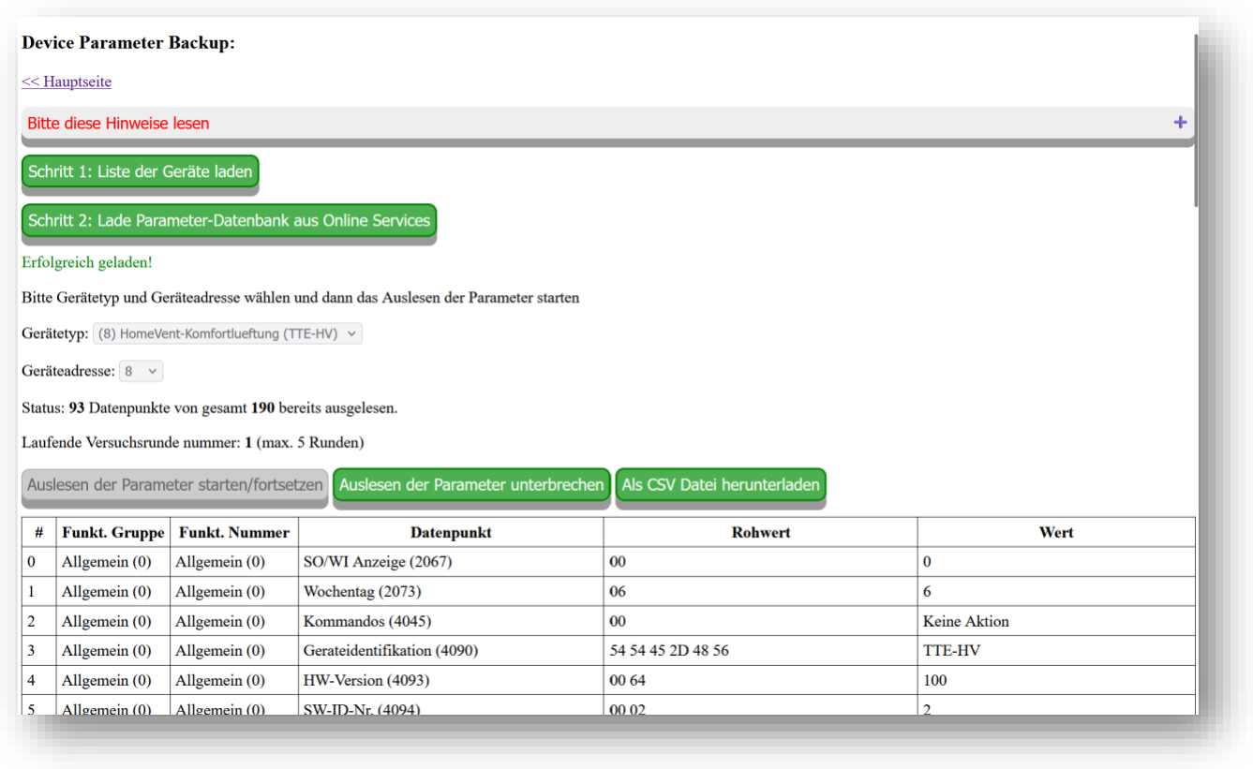
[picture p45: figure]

### 21 Übertragung der Parameter über MQTT Protokoll

Sie brauchen in Ihrem Hausautomatisierungssystem einen MQTT Broker um die Parameterwerte über MQTT Protokoll zu übertragen und dann in Ihrer Hausautomatisierungssoftware nutzen zu können. CAN-Gateway unterstützt aktuell nur eine unverschlüsselte MQTT Kommunikation über TCP. Also jeder, der mit Ihrem WLAN verbunden ist, kann dann auf diese Daten zugreifen und auch z.B. diese Daten manipulieren. Deswegen CAN-Gateway soll nur in einem sicheren, privaten und nicht öffentlichen WLAN eingesetzt werden und vom Internet aus nicht zugänglich sein, also keine Portweiterleitung etc. Ihr MQTT Brocker soll eine Authentifizierung mittels Logins/Passwords unterstützen und unverschlüsselte Kommunikation über TCP zulassen.

Beim MQTT Protokoll muss jede zu übertragende Information (in unserem Fall sind es Parameter) einen eindeutigen Namen besitzen. Diesen Namen nennt man „Topic“. CAN-Gateway ist so eingestellt, dass für jeden konfigurierten Parameter ein Topic erzeugt wird, welches aus einem für alle Parameter gemeinsamen Teil besteht, folgend mit einem Schrägstrich (/-Zeichen) und dann noch konfigurierbarer Parametername dazu. Der gemeinsame Teil wird in allgemeinen Einstellungen definiert. Der Parameter-spezifische Name in Parameter Einstellungen. Z.B. ist dann der resultierende Topic „cangateway/helligkeit“ oder „cangateway/temperatur“ usw. Über dieses Topic kann dann der entsprechende Parameter ausgelesen werden. Parameteränderungen müssen über den Topic mit dem gleichen Namen aber zusätzlich am Ende noch mit „/set“ eingesteuert werden. Also z.B. über „cangateway/temperatur/set“. Das geht natürlich dann nur für Parameter, die mit dem Attribut „w“ (Write) definiert sind.

### 22 Übertragung der Parameter über Modbus TCP

### 22.1 Hinweise zu Modbus TCP Kommunikation

CAN-Gateway unterstützt aktuell nur eine unverschlüsselte Modbus TCP Kommunikation. Also jeder, der mit Ihrem WLAN verbunden ist, kann dann auf diese Daten zugreifen und auch z.B. diese Daten manipulieren. Deswegen CAN-Gateway soll nur in einem sicheren, privaten und nicht öffentlichen WLAN eingesetzt werden und vom Internet aus nicht zugänglich sein, also keine Portweiterleitung etc.

### 22.2 Modbus Adressen

Die Adressen der Parameter auf dem Modbus sind wie folgt definiert. Grundsätzlich bekommt jeder Parameter entsprechend seinem Nummer (1 bis 20) eine Adresse, die nach folgender Formel berechnet wird:

Basisadresse=(Nummer-1)*10

Beim Modbus gilt eine Adresse für einen 16-Bit Wert (ein Register). Daher gilt die oben beschriebene Adressen-Zuordnung exakt nur für Parameter, die in einen Register reinpassen, also Parameter mit Datentyp: U8, S8, U16 und S16.

Parameter mit Datentyp U32 oder S32 bekommen jeweils zwei Adressen (also werden durch zwei Register dargestellt). Die Basisadresse beschreibt die zwei „höchsten“ Bytes (also inklusiv MSB), die nächste Adresse (also BAsisadresse+1) beschreibt die zwei „niedrigsten“ Bytes (also inklusiv LSB). Z.B. wenn ein Parameter Nummer 5 vom Typ U32 ist, dann hat er die Adressen 40 und 41.

Parameter mit Datentyp RAW und STR bekommen jeweils 10 Adressen, werden also in 10 Registern übertragen. Es können also maximal 20 Zeichen (2 Zeichen pro ein Register) beim Typ STR bzw. 20 Bytes an Rohdaten über Modbus ausgelesen werden. Der Rest, falls vorhanden, wird quasi abgeschnitten.

Evtl. sind nicht alle Parameter auf dem Modbus verfügbar. Aufgrund Auslastung des CANGateways können insgesamt nur 32 Register genutzt werden. Parameter mit Datentyp U8, S8, U16 und S16 verbrauchen jeweils ein Register für Lesen und ggf. noch ein fürs Schreiben. Parameter mit Datentyp U32 oder S32 verbrauchen jeweils zwei Register für Lesen und ggf. noch zwei fürs Schreiben. Parameter mit dem Datentyp RAW und STR verbrauchen jeweils 10 Register. Es wird empfohlen die Parameter, die auf dem Modbus nicht unbedingt notwendig sind, am Ende der Parameterliste zu definieren.

### 22.3 Register Typen

Alle Parameter sind als Register vom Typ „Input Register“ definiert und können mit der Modbus Funktion „Read Input Registers (0x04)“ ausgelesen werden.

Parameter, die auch geschrieben werden können (mit dem Attribut „w“), sind zusätzlich als Register vom Typ „Holding Register“ definiert und können mit Modbus Funktionen „Write Single Register (0x06)“ und „Write Multiple Registers (0x10)“ geschrieben werden. Wenn Holding Register mit der Funktion „Read Holding Register (0x03)“ ausgelesen wird, bekommt man NICHT den aktuellen Parameterwert, sondern den letzten Wert, den man geschrieben hat oder 0.

Parameter mit Datentyp RAW und STR können über Modbus generell nur ausgelesen und nicht geändert werden, unabhängig vom r/w Attribut.

### 22.4 Übertragungswerte

Alle Parameter werden als binäre Rohwerte übertragen. Es findet KEINE Korrektur mit Koeffizient/Offset wie bei MQTT statt. Diese Korrektur kann normalerweise auf Ihrem Modbus Master erfolgen und Sie müssen es da richtig einstellen.

Parameter mit Datentyp U8 und S8 werden zu entsprechenden 16-bit Werten umgewandelt, da die Modbus Register 16-bit lang sind.

Parameter mit Datentyp U32 und S32 werden, wie oben beschrieben, jeweils in zwei Register übertragen. Sie müssen ggf. auf Ihrem Modbus Master die korrekte Byte- und Register-Reihenfolge einstellen.

RAW und STR Parameter werden identisch behandelt und generell als Rohdaten übertragen. Das bedeutet zum Beispiel, dass eine Zeichenfolge „Eingeschaltet“ als 16-bit HEX Zahlen 0x4569, 0x6e67, 0x6573,0x6368, 0x616c, 0x7465, 0x7400 übertragen wird (ASCII kodiert, ggf. mit 00 erweitert). Die ersten zwei Zeichen „Ei“ (0x4569) werden im Register mit der Adresse wie oben im Formel übertragen, die nächsten zwei „ng“ (0x6e67) sind im nächsten Register (Adresse+1) usw.

### 23 Steuerung über Bedienmodul

Wenn CAN-Gateway über CAN-Bus mit einem Bedienmodul (Raumbedienmodul, TTE-BM) verbunden ist, kann CAN-Gateway vom Bedienmodul als Gateway (TTE-GW) erkannt werden und kann darüber neu gestartet oder auf die Werkseinstellungen zurückgesetzt werden. Außerdem werden einige Informationen über die Verbindung zum WLAN (Netzwerkname, IP Adresse, Status, Signal-Qualität) angezeigt.

Die Voraussetzung ist, dass über WEB-Interface in den Einstellungen die Option „Ermöglichen CAN Gateway über Bedienmodul zu steuern“ aktiviert wurde. Dann erscheint CAN-Gateway als TTE-GW Gerät im Bedienmodul/Hauptmenu „Service“:

Durch Klicken auf Allgemein(0) → Allgemein Gateway → Information (1), dann scrollen nach unten auf Alle Datenpkt., dann Klicken auf die Liste der Datenpunkte rechts kann man auf die folgenden 5 Optionen zugreifen:

- Zurücksetzen auf Werkseinstellungen
- Neu starten
- Gateway-CAN-ID (Das ist die CAN-Gateway Adresse)
- IP-Adresse (vom CAN-Gateway im WLAN)
- Geräteidentifikation (anzeigt immer “CAN-Gateway”)

Um CAN-Gateway neu zu starten oder auf Werkseinstellungen zurückzusetzen, muss man in der entsprechenden Zeile auf „-“ klicken, dann auf „Neu starten“ bzw. „Zurücksetzen“ und dann auf „OK“:

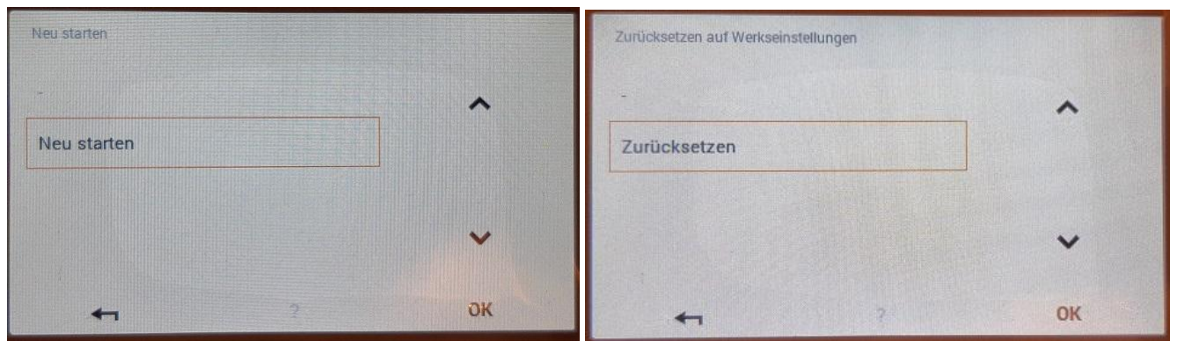
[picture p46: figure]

Zurücksetzen ist allerdings nur verfügbar, wenn man im UserLevel von mindestens 3 sich befindet.

Durch Klicken auf WLAN(2) → Information(0) → Information (1), dann Klicken auf die Liste der Datenpunkte rechts kann man auf die folgenden 3 Werte zugreifen:

- Ausgewähltes WLAN (WLAN Netzwerkname, mit dem CAN-Gateway verbunden ist/werden soll)
- Verbindungsstatus
- Signalqualität

### 24 REST-API

REST-API (Application Interface) stellt die Möglichkeit dar, auf die konfigurierten Parameter über HTTP Protokoll zuzugreifen und noch vieles andere zu erledigen. WEB-interface des CAN-Gateways nutzt selbst auch diesen REST-API um die Parameterwerte anzuzeigen, die Änderungen einzusteuern, Konfiguration an CAN-Gateway zu übertragen usw. In folgender Tabelle ist der REST-API beschrieben (nicht vollständig, nur Auswahl).

URL | GET oder POST Method | Beschreibung
http://cangateway.local/getparam?num=XX | GET | Antwort erhält den aktuellen Parameterwert für Parameter Nummer XX (XX=1 bis 40)
http://cangateway.local/setparam?num=XX | POST | Änderungsanfrage für Parameter Nummer XX, der Wert muss in Body als text/plain übertragen werden
http://cangateway.local/getparamraw?num=XX | GET | Antwort erhält den aktuellen Parameterwert für Parameter Nummer XX (XX=1 bis 40) in Rohformat, also so wie es auf dem CAN-Bus übertragen wird ohne Umrechnungen
http://cangateway.local/getparamage?num=XX | GET | Antwort erhält das Alter in Sekunden für den aktuellen Parameterwert, für Parameter Nummer XX.
http://cangateway.local/getmac | GET | Antwort erhält die MAC Adresse des CAN-Gateways
http://cangateway.local/getip | GET | Antwort erhält die IP Adresse des CAN-Gateways
http://cangateway.local/getmqttstate | GET | Antwort erhält Status der Verbindung zum MQTT Server
http://cangateway.local/json/getallvalues | GET | Antwort enthält die Werte für alle Parameter in JSON Format.

Anstatt von cangateway.local müssen Sie die IP Adresse von Ihrem CAN-Gateway eintragen.

### 25 Besondere Hinweise zu Parameteränderungen

Parameteränderungen müssen mit besonderer Vorsicht vorgenommen/eingesteuert werden. CAN-Gateway erlaubt viele Parameter zu ändern, deren Änderung ggf. überhaupt nicht sinnvoll ist. Wenn CAN-Gateway mit Ihrem Hausautomatisierungssystem verbunden ist und die Änderungsanträgen vom Hausautomatisierungssystem entgegen genommen werden können (also einige oder alle Parameter als änderbar konfiguriert sind), müssen Sie sicherstellen dass auch Ihres Hausautomatisierungssystem nur sinnvolle Änderungen einsteuern kann.

### 26 Android App: MyHome App für Hoval Geräte

App für Android Smartphone: kann direkt mit CAN-Gateway verwendet werden, solange Smartphone und CAN-Gateway im gleichen WLAN Netzwerk sind. Verfügbar auf Google Play: https://play.google.com/store/apps/details?id=com.wladwnt.myhome_for_hoval_devices

CAN-Gateway mit Software Version ≥ 27.001 notwendig.

Ab App Version 1.1 und ab CAN-Gateway Version 28.001 ist auch Zugriff über Internet möglich. Siehe dazu Kapitel 27.

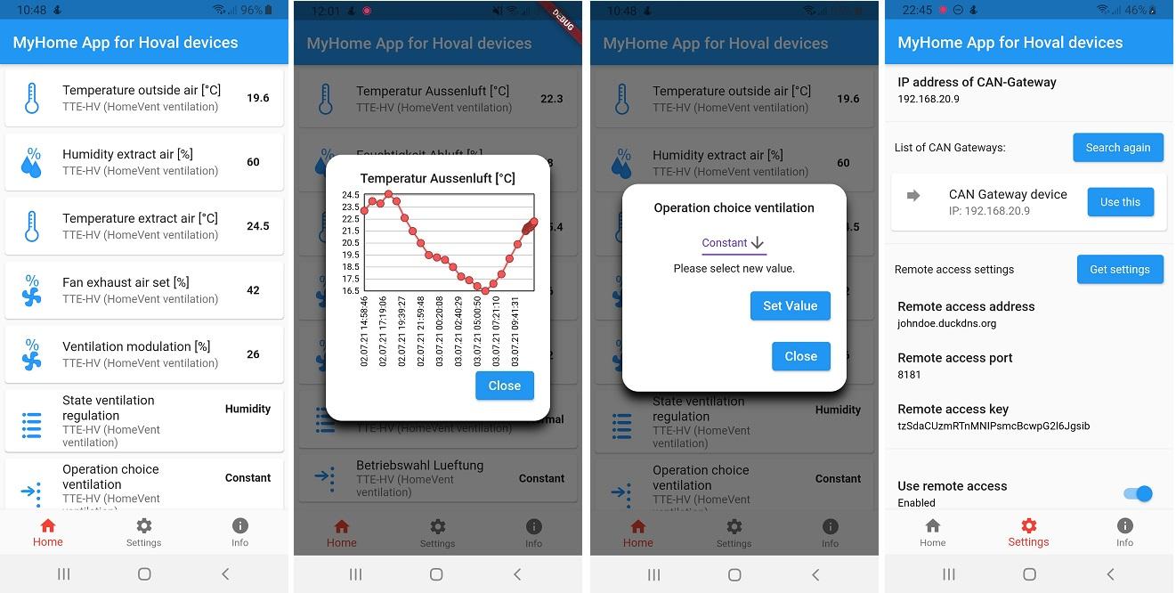
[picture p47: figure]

### 27 Windows App: MyHome App für Hoval Geräte

Windows App ist die gleiche wie Android App. Sie läuft unter Windows 64-bit. 32-Bit Windows wird leider nicht unterstützt. Die Android/Windows App ist in Flutter programmiert. Die Unterstützung von Windows in Flutter ist noch in Beta Stadium, daher könnte es theoretisch sein, dass Windows App noch einige Bugs hat. Ich konnte aber bisher keine Probleme feststellen.

### 28 Fernzugriff auf CAN-Gateway über Internet (ab SW Version ≥

28.100)

Ab SW Version 28.100 ist es möglich auf CAN-Gateway über Internet zuzugreifen. Dabei werden die Daten in beide Richtungen verschlüsselt übertragen. Die Datenübertragung findet über HTTP Protokoll statt. Wegen der Verschlüsselung funktioniert der Zugriff über Internet mit einem normalen WEB-Browser nicht, es muss zwingend die Android oder Windows App verwendet werden. Im Lokalen WLAN/LAN Netz ist dann weiterhin Zugriff über WEB-Browser möglich.

Für einen Zugriff über Internet muss aktuell ihr lokales Netz eine öffentliche IPv4 Adresse (statische oder dynamische) besitzen. Normalerweise das ist der Fall. Allerdings gibt es mittlerweile einige Internet Provider, die standartmäßig nur ein sogenanntes Dual-Stack Lite anbieten (z.B. Vodafone/Kabel Deutschland, Unitymedia). In diesem Fall hat man nur eigene IPv6 Adresse und keine von außen erreichbare eigene IPv4 Adresse und man kann nicht ohne weiteres eine Verbindung vom

Android/Windows App zu CAN-Gateway aufbauen. Erfahrungsgemäß kann man aber um die Aktivierung des Dual Stacks (normal, nicht Lite) bitten und bekommt es auch kostenlos.

### 28.1 Einrichtung des Zugangs

Ein gesicherter Zugriff auf CAN-Gateway kann wie folgt konfiguriert werden:

1) Um über Internet auf CAN-Gateway zu zugreifen, muss CAN-Gateway eine Webadresse besitzen. Das kann man über ein sogenanntes DDNS (Dynamisches DNS) Dienst einrichten. Es gibt verschiedenen kostenlosen DDNS Provider (z.B. duckdns.org, dyndns.org, dynu.com etc.). Sie müssen sich bei einem der Provider registrieren (wenn Sie es nicht bereits für andere Zwecke gemacht haben). Dabei wählt man eine verfügbare Webadresse (wie z.B. maxmustermann.duckdns.org oder maxmustermann1.dyndns.org). Man bekommt auch einen Benutzernamen oder Token und meistens auch noch ein Kennwort. Diese drei wird man im übernächsten Schritt brauchen.
2) CAN-Gateway muss über ein TCP Port (default: 8181, kann aber im nächsten Schritt auch ein anderer gewählt werden) vom Internet aus erreichbar sein. Normalerweise ist man über ein DSL/Kabel/WiFi Router ans Internet angebunden. Dieser verbietet standartmäßig externe Zugriffe vom Internet aus auf andere Geräte im lokalen WLAN/LAN Netzwerk. Sie müssen in Ihrem Router eine Portfreigabe für Port Nummer 8181 für CAN-Gateway einrichten. Bezüglich Portfreigabe lesen Sie bitte dazu die Benutzereinleitung zu Ihrem Router. Bei einem Fritzbox geht es z.B. über Menü „Internet →Freigaben“ und dann unter „Port Freigaben“.

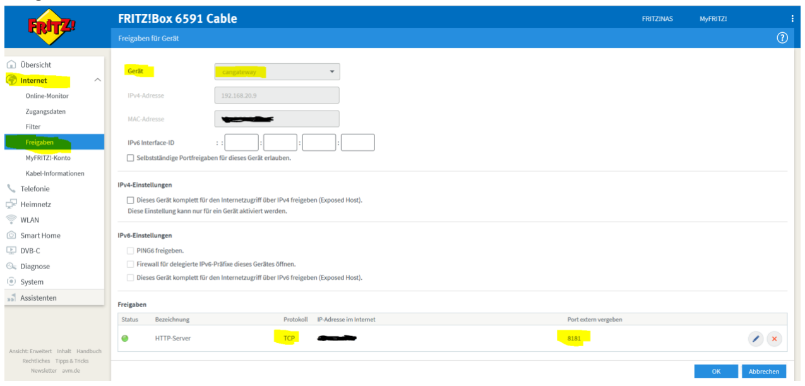
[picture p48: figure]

3) Über WEB-Interface, den Punkt „Fernzugriff über Internet“ wählen.
Folgende Parameter müssen hier eingestellt werden:
Fernzugriff einschalten: muss logischerweise angehakt werden
Zugriffsadresse: die im ersten Schritt gewählte DDNS Webadresse (komplett, z.B. maxmustermann.duckdns.org)
Server Port: lassen Sie hier 8181 stehen. Die fortgeschrittenen Nutzer können auch eine andere Nummer wählen.
Schlüssel: generieren Sie durch klicken auf „Schlüssel generieren“ einen Schlüssel für den Zugang. Dieser Schlüssel wird im nächsten Schritt automatisch in Ihre CAN-Gateway Android/Windows App übertragen, Sie müssen ihn also nicht unbedingt merken. Halten Sie diesen Schlüssel streng geheim! Der Schlüssel ist dazu da, damit nur Sie bzw. Ihre App auf

CAN-Gateway zugreifen kann. Mit diesem Schlüssel werden auch alle übertragenen Daten verschlüsselt.
DDNS durch CAN-Gateway steuern: wenn sie DDNS nicht bereits z.B. durch Router nutzen, muss diese Option angehakt werden.
IP Adresse API Provider: hier einfach eine der verfügbaren Optionen wählen. CAN-Gateway verwendet einen IP API Provider (dafür ist keine Registrierung oder ähnliches notwendig) um eigene von außen zugewiesen IP Adresse zu ermitteln. Diese wird dann an DDNS Provider mitgeteilt.
API fuer ext. IP Adresse: wird bei einem Auswahl des IP API Providers passend automatisch eingestellt (außer man hat „IP API URL manuell einstellen“ ausgewählt, dann hat man hier die Möglichkeit manuell die IP API URL einzustellen, was für fortgeschrittene Nutzer vorgesehen ist)
DDNS Dienst: wählen Sie hier ein DDNS Dienst, bei dem Sie sich im Schritt 1 registriert haben und geben sie im folgenden Domain, Benutzername/Token und ggf. Passwort ein. Domain ist dabei die von Ihnen im ersten Schritt gewählte Adresse (Zugriffsadresse), aber ohne Provider Anteil. Also z.B. „maxmustermann“ ohne „.duckdns.org“.
DDNS Update URL: wird passend zu DDNS Einstellungen automatisch eingestellt (außer man hat „Update URL manuell einstellen“ ausgewählt, was für fortgeschrittene Nutzer vorgesehen ist).
Sobald alles eingestellt ist, müssen Sie auf „Einstellungen Speichern (auf CAN-Gateway hochladen)“ klicken.
Anmerkung: CAN-Gateway speichert intern nur die resultierenden URLs, daher wird nach dem Speichern der Einstellungen oder beim nächsten Mal, wenn man die Einstellungen für Fernzugriff aus dem CAN-Gateway ausließest, die IP API und DDNS Dienst Auswahl auf „Manuell“ gewählt. Das muss man dann nicht erneut ändern, die resultierenden URLs sind dann schon korrekt eingestellt.

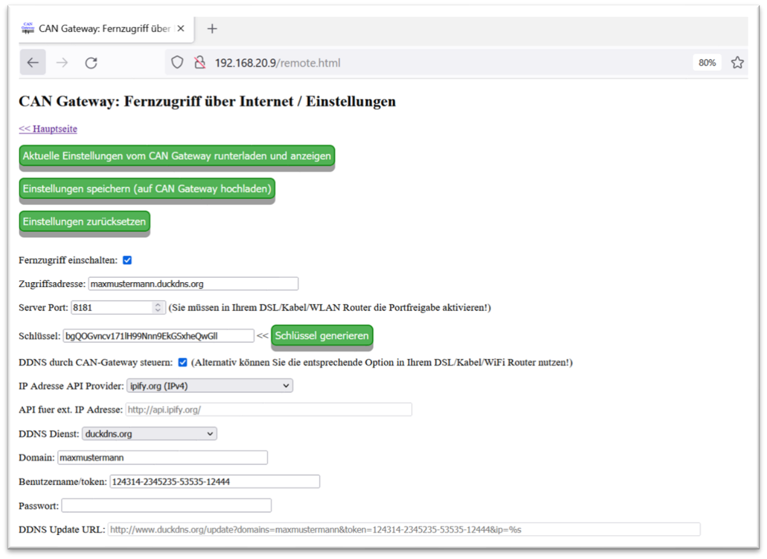
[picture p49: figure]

4) Nun können Sie Ihre CAN-Gateway Android/Windows App auf dem Smartphone/PC/Laptop/Tablet öffnen. Um den Zugriff über Internet zu nutzen, muss die App zunächst für den Zugriff über WLAN/LAN eingerichtet werden. Dafür müssen Sie lediglich die interne IP Adresse des CAN-Gateways in „Einstellungen“ der App konfigurieren. Wenn die App dann im lokalen Netz läuft, kann man im Bereich „Fernzugriff Einstellungen“ auf „Automatisch“ klicken. Die App liest dann über Ihren lokalen WLAN/LAN Netzwerk die erforderlichen Konfigurationen aus dem CAN-Gateway aus (Webadresse, Port und Schlüssel). Nun können Sie weiter unten in Einstellungen den Schalter „Fernzugriff verwenden“ umlegen. Danach können sie mit Ihrem Smartphone/PC/Laptop/Tablet und der App CAN-Gateway auch über Internet steuern und müssen dafür nicht in Ihrem WLAN/LAN Netzwerk sein.

### 28.2 Details zur Verschlüsselung

Für die Datenübertragung wird AES-256 Verschlüsselung in GCM Modus verwendet. Diese Verschlüsselung wird aktuell als sehr sicher eingestuft und beinhaltet auch automatisch die Authentifizierung. Zusätzlich sind auf CAN-Gateway einige anderen Maßnahmen zur Vermeidung der Attacken implementiert.

Bitte unbedingt den Schlüssel geheim halten! Beim Verdacht auf Missbrauch bitte sofort einen neuen Schlüssel generieren!

### 29 Hilfe!

### 29.1 Netzwerkname/Schlüssel sind falsch eingestellt, Web-Interface nicht zugänglich. Was tun?

Wenn im CAN-Gateway falsche Netzwerkname und/oder Netzwerkschlüssel konfiguriert sind, kann CAN-Gateway mit Ihrem WLAN Netzwerk sich nicht verbinden. Dann ist auch der WEB-Interface von CAN-Gateway nicht erreichbar ist. Für diesen Fall gibt es drei Optionen:

1) Die Möglichkeit alle Einstellungen auf die Initiale Werte (inklusiv CAN-Gateway als Access Point mit Netzwerkname cangateway und Netzwerkschlüssel 000999555) über Bedienmodul zurückzusetzen. Diese Option ist allerdings nur verfügbar, wenn in den Einstellungen zuvor die Steuerung des CAN-Gateways über Bedienmodul aktiviert wurde. Siehe dazu Kapitel „Steuerung über Bedienmodul“.
2) Nur wenn Software auf einem CAN-Gateway Development Board verwendet wird: drücken und halten Sie gedrückt „REINIT“ Taster für mindestens 6 Sekunden. CAN-Gateway setzt seine Einstellungen auf den initialen Zustand zurück und restartet als Access Point mit dem Namen „cangateway“.

3) die Möglichkeit, entweder komplett alle Einstellungen oder nur Netzwerkname und Netzwerkschlüssel auf die Initiale Werte (cangateway, 000999555) über USB Schnittstelle zurückzusetzen. Dafür müssen Sie CAN-Gateway über USB Schnittstelle mit Ihrem Laptop/PC verbinden (sieh dazu Schritte 1 bis 6 in Kapitel „Software flashen“). Danach müssen Sie ein Terminalprogramm für serielle Schnittstelle aus dem Internet herunterladen, installieren und starten, die Verbindung zum CAN-Gateway herstellen und an CAN-Gateway die Zeichenfolge „RESET_TO_INITIAL_SETTINGS“ (für vollständiges Zurücksetzen aller Parameter) oder „RESET_WLAN_SETTINGS“ (um nur Netzwerkname/Netzwerkschlüssel zurück zu setzen) senden. Es muss auf Großbuchstaben geachtet werden und die Zeichenfolge muss am Ende zusätzlich ein „Carriage Return“ (CR, ASCII Code = 13 (hexadezimal 0D )) Zeichen beinhalten. CAN-Gateway antwortet dann mit „OK! Restart...“ und startet neu. Dabei startet WLAN wie im initialen Zustand als Access Point (sieh Kapitel „Erste Inbetriebnahme“).

Wichtig: wenn man sich im Terminalprogramm mit dem CAN-Gateway verbindet, muss die richtige Baudrate vorgegeben werden. Initial sind es 115200 Baud. Wenn Sie aber diese Baud-Rate bereits geändert haben, müssen sie die richtige einstellen. Wenn Sie vergessen haben, welche Baudrate die richtige ist, kann man einfach versuchen alle zulässigen Baudraten durchzuprobieren. Dabei muss man nach jedem Versuch cangateway aus- und einschalten.

[Neu ab SW 26.001] Wenn CAN-Gateway mit aktuell eingestellten WLAN Netzwerkname und Netzwerkschlüssel noch nie mit WLAN verbunden war, versucht er lediglich ca. 45 Sekunden sich mit dem Netzwerk zu verbinden. Klappt es nicht, schaltet er automatisch in AP Mode (Name: cangateway, Schlüssel: 000999555). Also wenn man die WLAN Zugangsdaten einfach falsch eingegeben hat, riecht es einfach ca. eine Minute zu warten bis CAN-Gateway in AP Mode geht. Wenn CAN-Gateway aber die richtigen WLAN Zugangsdaten hatte und man jetzt einfach ein anderes Netzwerk hat, wird er weiterhin unendlich lange versuchen sich mit dem Netzwerk zu verbinden. Also dann muss man eine der beiden oben beschriebenen Optionen nutzen.

Im Folgenden ist die Vorgehensweise mit zwei Terminal Programme beschrieben:

### 29.1.1 Mit Bray Terminal

1) Das Programm hier downloaden, ggf. entpacken und starten: https://sites.google.com/site/terminalbpp/
2) Richtigen COM-Port und Baudrate wählen. Die Anderen Einstellungen wie auf dem Bild unten.
3) Auf „Connect“ klicken.

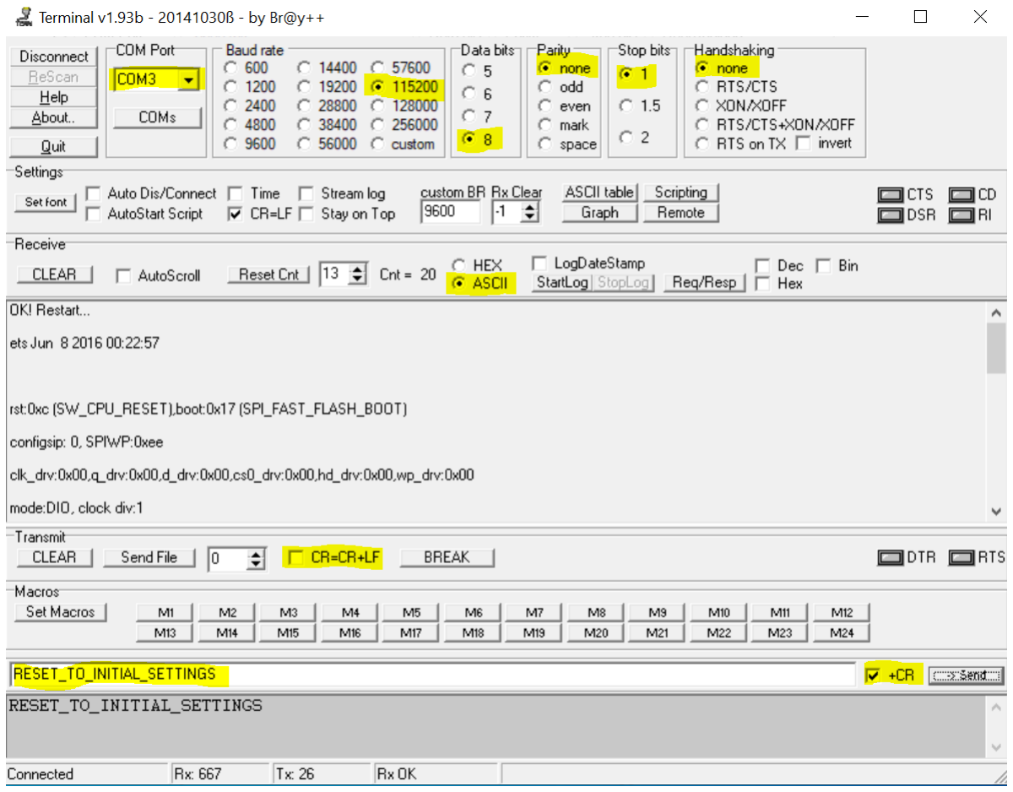
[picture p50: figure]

4) „RESET_TO_INITIAL_SETTINGS“ eintippen und dann auf „->Send“ klicken.
5) Cangateway antwortet mit „OK! Restart“ wie im Bild.
6) Dann auf „Disconnect“ klicken und das Programm kann beendet werden.

### 29.1.2 Mit HTerm

1) Das Programm hier downloaden, ggf. entpacken und starten: http://www.der-hammer.info/pages/terminal.html
2) Richtigen COM-Port und Baudrate wählen. Die Anderen Einstellungen wie auf dem Bild unten.
3) Auf „Connect“ klicken.

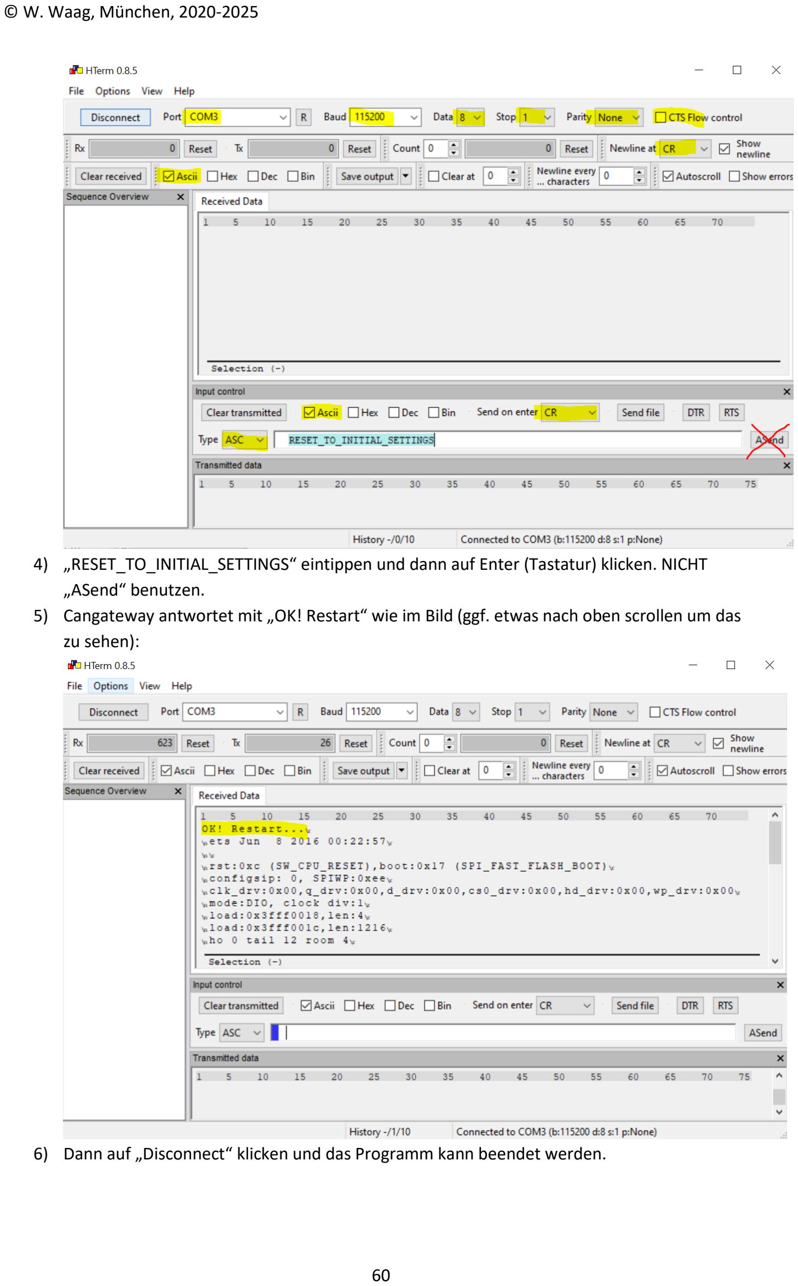
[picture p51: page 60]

4) „RESET_TO_INITIAL_SETTINGS“ eintippen und dann auf Enter (Tastatur) klicken. NICHT „ASend“ benutzen.
5) Cangateway antwortet mit „OK! Restart“ wie im Bild (ggf. etwas nach oben scrollen um das zu sehen):
6) Dann auf „Disconnect“ klicken und das Programm kann beendet werden.

### 29.2 CAN-Gateway startet immer mit Werkeinstellungen. Einstellungen

können nicht gespeichert werden.
Die wahrscheinlichste Ursache ist, dass die Hardware (Flash Speicher) beschädigt ist. CAN-Gateway Software bildet über alle Einstellungen eine Prüfsumme, diese wird zusammen mit den Einstellungen in Flash Speicher des ESP32 gespeichert. Beim Aufstarten werden die Einstellungen und die Prüfsumme aus dem Flash Speicher ausgelesen. Stimmt die Prüfsumme nicht, werden die Einstellungen automatisch auf die Werkseinstellungen zurückgesetzt, weil die Korrektheit/Integrität der ausgelesenen Einstellungen dann nicht gewährleistet werden kann. Sie müssen dann wohl ESP32 DevKit austauschen.

### 30 Hinweise zu HomeVent Komfortlüftung mit dem einfachen Bediengerät BG02E

HomeVent Geräte der Firma Hoval vom TTE Typ (Typ z.B. FR201, FR251, FR351, FRT351 etc.) werden in einfacher Variante mit einem Bediengerät BG02E (kein Touch, zwei Einstellräder für
Volumenstrom und Feuchte sowie ein Taster für Party-Modus) betrieben. In diesem Fall muss man Folgendes beachten, wenn man CAN-Gateway einsetzen will. BG02E Bediengerät ist recht „dumm“, er sendet einfach ca. jede Sekunde oder so die Sollwerte für Volumenstrom und Feuchte an die Komfortlüftung. Wenn man in diesem Verbund CAN-Gateway anschließt, dann kann man über CAN-Gateway nichts ansteuern. Genauer gesagt, wenn CAN-Gateway einen Sollwert für Volumenstrom oder Feuchte an Komfortlüftung sendet, wird er in nächster Sekunde durch BG02E Bediengerät wieder geändert bzw. „überschrieben“. Also praktisch in diesem Verbund kann man nur CAN-Gateway zum Auslesen der Parameter nutzen, nicht aber zum Steuern. Will man auch steuern können, muss man dann die Komfortlüftung nur mit dem CAN-Gateway betreiben und BG02E Bediengerät abstecken. Schließlich kann man ja auch über WEB-Interface vom CAN-Gateway die Sollwerte einstellen und ändern (oder halt über MQTT Protokoll etc.). Will man auch einen Bediengerät von Hoval haben, dann geht es nur mit dem deutlich teureren Bedienmodul von Hoval, dem mit dem Touchscreen. Dieser sendet nämlich (wie auch CAN-Gateway) die Sollwerte nur einmal bei deren Änderung, kann also in einem Verbind mit CAN-Gateway gut funktionieren.

Die andere Implikation: BG02E Bediengerät wird vom CAN-Gateway als TTE-WEZ Gerät vom Typ=0 und Adresse=0 erkannt und auf der „WEB-Interface: Liste der Geräte“ Seite angezeigt. Das hat an sich aber keinerlei negative Auswirkung auf die Funktionalität des CAN-Gateways.

CAN-Gateway Development Board besitzt (OPTIONAL, sofern bestückt) eine zusätzliche CAN-Schnittstelle (implementiert als RJ45 Buchse), die speziell für Anschluss eines BG02E Bedienmoduls bestimmt ist. Diese zusätzliche Schnittstelle ermöglicht die oben genannten Nachteile zu umgehen und CAN-Gateway zusammen mit einem BG02E Bedienmodul vollumfänglich zu nutzen. Es funktioniert so, dass CAN-Gateway die Vorgaben des Bedienmoduls bzgl. Volumenstrom und Feuchte-Sollwert an Lüftungsgerät nur dann weiterleitet, wenn man die Stellräder gerade gedreht oder Party-Taster gedrückt hat. So können die Sollwerte auch über CAN-Gateway geändert werden und gelten so lange, bis man sie über BG02E Betätigung „überschreibt“. Status-LED am BG02E zeigt -mindestens 20 Sekunden lang nachdem man Stellräder oder Party-Taste betätigt hat – den aktuellen Status des Lüftungsgeräts gemäß der originalen Herstellerbeschreibung. Ansonsten leuchtet es immer grün, wenn BG02E korrekt mit dem CAN-Gateway verbunden ist.

### 31 Zeiteinstellung in CAN-Gateway [neu ab SW 22.001]

Um z.B. den richtigen Zeitstempel für geloggte Daten zu bekommen, fragt CAN-Gateway über Internet bei einem Zeitserver (siehe Einstellungen) nach aktueller Zeit. Die Abfrage wird einmal pro Stunde durchgeführt. Dazwischen rechnet CAN-Gateway die Zeit selbst.

Wenn der Zeitserver gar nicht erreichbar ist, verwendet CAN-Gateway eine fiktive interne Zeit, die bei jedem Power-Up mit 1.1.1970, 00:00:00 startet. Das ist z.B. der Fall, wenn Zeitserver falsch eingestellt ist oder wenn man CAN-Gateway ausschließlich im lokalen Netzwerk ohne Internet Zugang betreibt.

Wenn CAN-Gateway mindestens einmal vom Zeitserver die Zeit bekommen hat, versucht er bis auf weiteres die Zeit selber zu rechnen. Das läuft auch über ein Reset hinaus, also solange die Stromversorgung da ist. Da aber die interne Uhr nicht besonders genau ist, kann es sein, dass diese Zeit nach vielen Stunden von der realen Zeit abweicht, wenn die Verbindung zum Zeitserver nicht mehr da ist. Sobald die Verbindung wieder möglich, wird CAN-Gateway die interne Zeit korrigieren.

Bei der Darstellung der historischen (geloggten) Daten über WEB-Interface, versucht WEB-Interface die Zeiten korrekt zum aktuellen Zeitpunkt umzurechnen wenn er feststellt, dass diese mit fiktiver interner Zeit (also Jahr 1970 etc.) gespeichert sind.

### 32 Autorecovery

Wenn CAN-Gateway ein schwerwiegendes Problem feststellt, wird automatisch ein Reset durchgeführt. Dadurch wird versucht sich vom Problem zu befreien. Ein schwerwiegendes Problem kann z.B. sein, dass WLAN Verbindung so grenzwertig wird, dass man sie ständig verliert und wieder verbindet. Oder wenn z.B. in der Kommunikation mit dem MQTT Server Probleme auftreten. In vielen Fällen läuft CAN-Gateway monatelang ohne Probleme. Erfahrungsgemäß kann jedoch Reset einmal pro Woche passieren. Das ist immer noch normal und führt nicht zu Funktionalitätseinschränkungen. Wenn es deutlich öfter auftritt, also z.B. mehrmals pro Tag, sollten Sie schauen ob WLAN ausreichend gut ist und ggf. logging Dateien von Ihrem MQTT Server prüfen.

### 33 Einbindung in Home Assistant

### 33.1 Einleitung

Home Assistant hat sehr viele Möglichkeiten, wie man externe Geräte einbinden kann. CAN-Gateway stellt auch verschiedene Interfaces zur Verfügung (MQTT, REST-API, ...), die verwendet werden können.

Im Folgenden wird nur eine der möglichen Optionen erläutert. Dabei wird davon ausgegangen, dass

1) Home Assistant korrekt eingerichtet ist (Version 2023.06 oder neuer).
2) Ein MQTT Broker ist installiert und in Home Assistant integriert, z.B. als Add-on: https://github.com/home-assistant/addons/blob/master/mosquitto/DOCS.md
3) CAN-Gateway ist für die Kommunikation mit dem MQTT Broker eingerichtet (siehe Bedienungseinleitung/MQTT Einstellungen) und Zeigt unter „Status“ in CAN-Gateway Web Interface „mit MQTT verbunden“.

### 33.2 Konfiguration

### 33.2.1 Automatische Konfiguration mit MQTT Discovery

CAN Gateway unterstützt eine automatische Erkennung aller Parameter in Home Assistant via MQTT. Bis CAN-Gateway Version 29.326 werden alle Parameter als Sensoren erkannt. Ab Version 29.327 ist eine deutlich verbesserte MQTT Discovery Unterstützung implementiert: Parameter werden entweder als Sensoren, als einstellbare numerische Werte, als binäre Sensoren, als Schalter oder als Auswahllisten erkannt und automatisch konfiguriert: je nachdem, wie der Parameter in CAN-Gateway konfiguriert ist.

Die Zuordnung erfolgt wie folgt:

- Als einstellbare numerische Werte werden Parameter konfiguriert, welche in CAN-Gateway als ein numerischer Typ eingestellt sind (U8, S8, U16, S16, U32, S32) und für Lesen und Schreiben (Attribut „w“) konfiguriert sind. Das betrifft z.B. die einstellbaren Solltemperaturen, Soll-Luftungsmodulation oder Soll-Feuchtigkeit beim HomeVent etc.
- Als Binäre Sensoren werden Parameter konfiguriert, welche in „Parameter-Konfiguration Generator“ beinhaltet sind, nur Werte „0“ (Aus) oder „1“ (Ein) einnehmen können und in CAN-Gateway Einstellungen nur für Lesen (Attribut „r“) konfiguriert sind.
- Als Binäre Sensoren werden Parameter konfiguriert, welche in „Parameter-Konfiguration Generator“ beinhaltet sind, nur Werte „0“ (Aus) oder „1“ (Ein) einnehmen können und in CAN-Gateway Einstellungen für Lesen und Schreiben (Attribut „w“) konfiguriert sind. Ein Beispiel ist die Aktivierung der CoolVent Funktion beim HomeVent.
- Als Auswahllisten werden Parameter konfiguriert, welche in „Parameter-Konfiguration Generator“ beinhaltet sind, Werte zwischen 0 und 255 einnehmen können wobei jedem Wert ein bestimmter Zustand zugeordnet ist und in CAN-Gateway Einstellungen für Lesen und Schreiben (Attribut „w“) konfiguriert sind. Beispiele sind die Parameter „Betriebswahl Lüftung“ oder „Betriebswahl Heizung“.
- Wenn nichts oben zutrifft, wird ein Parameter als ein Sensor konfiguriert.

Wenn die Option „Unterstützung Home Assistant (https://www.home-assistant.io/) / MQTT Discovery“ (https://www.home-assistant.io/docs/mqtt/discovery/) aktiviert ist, CAN-Gateway mit dem MQTT Broker verbunden ist und Home Assistant die MQTT Integration eingerichtet hat, dann kann man in Home Assistant unter „Einstellungen“-> „Geräte & Dienste“ die MQTT Integration finden. Dabei muss stehen, dass mindestens ein Gerät und mehrere Entitäten verfügbar sind. Darunter sind CAN-Gateway (Gerät mit dem Namen „Hoval-CANGW“) und die Parameter als Entitäten. Nun kann man die Steuerelemente und Sensoren zum Dashboard hinzufügen.

Auf dem Dashboard erscheinen dann die Steuerelemente sowie die Sensoren:

Diese können dann bearbeitet werden: man kann z.B. einen anderen Symbol zuordnen oder anders benennen.

Der Vorteil der automatisierten Konfiguration ist, dass man in Home Assistant nichts manuell einstellen muss. Sie funktioniert jedoch nur für die meist verwendete Parameter korrekt. Parameter, die in dem Konfigurator nicht beinhaltet sind und der Nutzer selber eingestellt hat, müssen unter Umständen manuell konfiguriert werden, wie im Folgenden beschrieben ist.

### 33.2.2 Manuelle Konfiguration

Siehe https://www.home-assistant.io/integrations/mqtt/#manual-configured-mqtt-items. Vorteil: man hat volle Kontrolle. Man kann z.B. die Parameter schöner oder anders darstellen lassen, als MQTT Discovery es erlaubt. Dazu hat Home Assistant umfangreiche Optionen. Die Einstellungen müssen in der Datei configuration.yaml (siehe https://www.home-assistant.io/gettingstarted/configuration/) (https://www.home-assistant.io/getting-started/configuration/) gespeichert werden. Im folgenden werden einige

Beispiel 1: (angenommen, man hat in CAN-Gateway ein Parameter wie folgt eingestellt: param=8;8;50;0;39652;r;Status_Lueftungsregelung;10;U8;1.000000;0.000000;
):

mqtt:
sensor:
- name: "Luftung Status"
state_topic: "cangateway/Status_Lueftungsregelung" value_template: >-
{% set mapper = {
'0' : 'Aus/Standby',
'1' : 'Normal',
'2' : 'VOC aktiv',
'3' : 'Feuchtigkeitsmodus', '4' : 'Frostschutz',
'5' : 'CoolVent',
'6' : 'Fehler'} %}
{{ mapper[value] if value in mapper else 'Unbekannt' }}

Dieses Beispiel entspricht genau dem, wie auch MQTT Discovery dieser Parameter einstellen würde. Sie können aber durch die manuelle Konfiguration z.B. die Übersetzung in eine andere Sprache machen.
Im nächsten Beispiel wird ein HomeVent in Home Assistant als ein Ventilator dargestellt. Zur Erläuterung wird auf die Dokumentation zu Home Assistant verwiesen.

Beispiel 2: Angenommen man hat im CAN-Gateway folgende Parameter eingerichtet:

param=8;8;50;0;38606;r;Lueftungsmodulation_percent;10;U8;1.000000;0.000000; param=8;8;50;0;40650;w;Betriebswahl_Lueftung;10;U8;1.000000;0.000000; param=8;8;50;0;40651;w;Normal_Lueftungsmodulation_percent;10;U8;1.000000;0.000000;

Dann kann die Konfiguration in configuration.yaml wie folgt aussehen:

mqtt:
fan:
- name: "Luftung"
unique_id: "ID_custom001"
state_topic: "cangateway/Betriebswahl_Lueftung"
command_topic: "cangateway/Betriebswahl_Lueftung/set" percentage_state_topic: "cangateway/Lueftungsmodulation_percent" percentage_command_topic: "cangateway/Normal_Lueftungsmodulation_percent/set" payload_on: "4"
payload_off: "0"
speed_range_min: 1
speed_range_max: 100

Für die Erklärung der Parameter siehe https://www.home-assistant.io/integrations/fan.mqtt/

Bzgl. der Konfigurationsdatei configuration.yaml siehe https://www.home-assistant.io/docs/configuration/ (https://www.home-assistant.io/docs/configuration/)

Damit kann man die Lüftung ein- und ausschalten sowie Luftmenge einstellen (in neueren Home Assistant Versionen sieht es etwas anders aus):

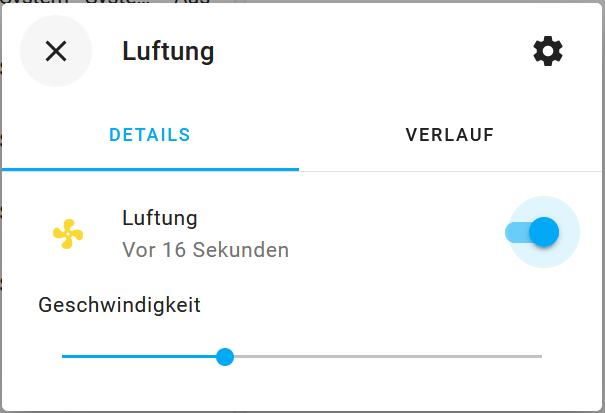
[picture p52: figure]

Die gleiche Steuerung ist auch mit automatischer MQTT Discovery möglich, wird jedoch anders dargestellt.

Beispiel 3: Betriebsauswahl für Lüftung. Angenommen man hat im CAN-Gateway folgende Parameter eingerichtet:

param=8;8;50;0;40650;w;Betriebswahl_Lueftung;10;U8;1.000000;0.000000;

Dieser Parameter kann laut Dokumentation (z.B. siehe http://www.hoval.com/misc/TTE/TTE-GW-Modbus-datapoints.xlsx) (http://www.hoval.com/misc/TTE/TTE-GW-Modbus-datapoints.xlsx) folgende Werte einnehmen: 0 (=“Standby“), 1 (=“Woche 1“), 2 (=“Woche 2“), 4 (=“Konstantbetrieb“), 5 (=“Sparbetrieb“). Man kann es in Home Assistant z.B. als MQTT „Select“ Element implementieren (siehe https://www.home-assistant.io/integrations/select.mqtt/): dafür in configuration.yaml folgendes einfügen:

mqtt:
select:
- command_topic: "cangateway/Betriebswahl_Lueftung/set" command_template: >-
{% set mapper = {
'Standby' : '0',
'Woche 1' : '1',
'Woche 2' : '2',
'Konstantbetrieb' : '4',
'Sparbetrieb' : '5'} %}
{{ mapper[value] if value in mapper else 'Unbekannt' }} state_topic: "cangateway/Betriebswahl_Lueftung" value_template: >-
{% set mapper = {
'0' : 'Standby',
'1' : 'Woche 1',
'2' : 'Woche 2',
'4' : 'Konstantbetrieb',
'5' : 'Sparbetrieb'} %}

{{ mapper[value] if value in mapper else 'Unbekannt' }} name: "Lüftung: Betriebsauswahl"
unique_id: "ID_custom002"
options:
- "Standby"
- "Woche 1"
- "Woche 2"
- "Konstantbetrieb"
- "Sparbetrieb"

Durch die Verwendung der Templates werden die Werte (0, 1, 2, 4, 5), die eine Betriebsart kodieren, dann als verständlicher Klartext dargestellt und können ausgewählt werden:

Dieses Beispiel entspricht genau dem, wie auch MQTT Discovery dieser Parameter einstellen würde. Sie können aber durch die manuelle Konfiguration z.B. die Übersetzung in eine andere Sprache machen.

Beispiel 4: Lüftungsstaus anzeigen. Angenommen man hat im CAN-Gateway folgende Parameter eingerichtet:

param=8;8;50;0;39652;r;Status_Lueftungsregelung;10;U8;1.000000;0.000000;

Dieser Parameter kann laut Dokumentation (z.B. siehe http://www.hoval.com/misc/TTE/TTE-GW-Modbus-datapoints.xlsx (http://www.hoval.com/misc/TTE/TTE-GW-Modbus-datapoints.xlsx) oder in CAN-Gateway unter „Liste der Parameterwerte“ bei diesem Parameter auf grünes „i“ klicken) folgende Werte einnehmen: 0 (=“Aus/Standby“), 1 (=“Normal“), 2 (=“VOC aktiv“), 3 (=“Feuchtigkeitsmodus“), 4 (=“Frostschutz“), 5 (=“Coolvent“), 6 (=“Fehler“), 7 (=Sommerfeuchtigkeit“).

Dieser Status kann man in Home Assistant z.B. als MQTT „Sensor“ Element implementieren und so konfigurieren, dass nicht die numerische Werte, sondern der Status in Klartext angezeigt wird: dafür in configuration.yaml folgendes einfügen:

mqtt:
sensor:
- name: "Luftung Status"
unique_id: "ID_custom003"
state_topic: "cangateway/Status_Lueftungsregelung" value_template: >-
{% set mapper = {
'0' : 'Aus/Standby',

'1' : 'Normal',
'2' : 'VOC aktiv',
'3' : 'Feuchtigkeitsmodus', '4' : 'Frostschutz',
'5' : 'CoolVent',
'6' : 'Fehler',
'7' : 'Sommerfeuchte'} %}
{{ mapper[value] if value in mapper else 'Unbekannt' }}

Der Status wird dann wie folgt dargestellt:

Auch dieses Beispiel entspricht genau dem, wie auch MQTT Discovery dieser Parameter einstellen würde. Sie können aber auch hier durch die manuelle Konfiguration z.B. die Übersetzung in eine andere Sprache machen.

### 34 Einbindung in OpenHab

OpenHab unterstützt MQTT Discovery ähnlich wie Home Assistant. Damit ist es möglich mit einigen einfachen Klicks die Einbindung in OpenHab mittels MQTT Protokolls einzurichten. Die notwendigen Schritte sind in folgender Anleitung bildlich zusammengefasst:

https://raw.githubusercontent.com/wladwnt/CAN-Gateway/master/OpenHab_configuration.pdf

Erfahrene Anwender können auch andere Methoden verwenden, wie z.B. Einbindung über HTTP REST API.

### 35 Einbindung in Loxone

Einbindung in Loxone kann über zwei alternative Wege erfolgen: als virtuelle HTTP Eingänge und Ausgänge oder als Modbus TCP. Für beide Optionen bietet CAN-Gateway ab SW Version 29.330 eine Hilfestellung in Form von einem Template-Generator. Dieser generiert XML Vorlagen für die in CAN-Gateway konfigurierte Parameter. Diese Vorlagen können dann in Loxone importiert werden. So muss man in Loxone dann nur ggf. ganz wenige, optionale Einstellungen (z.B. min/max Werte etc.) manuell nachbearbeiten.
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

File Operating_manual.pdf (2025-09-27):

© W. Waag, Munich, 2020-2025

# Operating manual CAN-Gateway software

SW Version 31.011 / Android+Windows App 1.1.1

Update 1 (27.09.2025)

### Table of contents

3.3 | Simple Do-It-Yourself hardware based on hardware modules available on the market ...... 9
10.3.1 | Example number 1: Ventilation (HomeVent) – read and write humidity set value.... 34

10.3.4 | Example number 4: Room control unit – read and write password for user level 7 .. 35
10.3.5 | Example number 5: Ventilation (HomeVent) – operating mode for ventilation ........ 35
29.1 | Incorrect WiFi network name and/or network key are entered, I cannot reach Web

29.3 CAN-Gateway starts WiFi in access point mode, but I cannot connect my PC/notebook to

### 1 Important notes – please read carefully!

The German version of the operating instructions is legally binding.

### 1.1 Intended use of the software

This software is intended to read out and control devices from Hoval AG that are equipped with a TopTronic® E control (hereinafter referred to as TTE devices).

In this sense, reading out means that the parameters and information are read out from TTE devices via the device CAN bus and:

1. can be displayed to the user on the CAN-Gateway user interface,
2. Can be transmitted to other devices compatible with these communication protocols using the communication protocols available in the software (REST API, MQTT, KNX IP (routing), Modbus TCP),
3. Can be saved on a micro SD card.

Control in the above sense means that this software can change the parameters and information that can be changed in TTE devices via the CAN bus. This change can:

1. Can be controlled directly by the user via the user interface or Android app or Windows app

2. Controlled by a device connected to this software via one of the communication protocols listed above.

The CAN-Gateway software does not contain any logic that independently initiates changes to the parameters and information in TTE devices.

The software functionalities described above should enable the TTE devices to be integrated into a home automation system.

Which parameters and information can be read out and / or changed depends on the respective TTE device. The functionality of all parameters listed in the following file from Hoval AG is contractually guaranteed: http://www.hoval.com/misc/TTE/TTE-GW-Modbus-datapoints.xlsx. As a rule, it is also possible to read out all parameters that are displayed via a TTE operating module in the "Service" menu for all user levels, but this is not contractually guaranteed.

The software can be applied by running it on a compatible microcontroller. ESP32 dual-core microcontrollers from Espressif (https://www.espressif.com/) are compatible. In addition, a compatible wiring of the microcontroller must be available. Among other things, this wiring must enable the necessary power supply for the microcontroller as well as the connection of the physical interfaces such as CAN bus and Ethernet. To use the SD card functionality, an SD card slot must be connected to the microcontroller. The wiring must be based on one of the three reference examples:

a. CAN gateway hardware V5, as described in the operating instructions
b. CAN Gateway Development Board, see http://wled.shop/wpcontent/uploads/2021/11/CAN_Gateway_Nutzungsinformationen.pdf (http://wled.shop/wp-content/uploads/2021/11/CAN_Gateway_Nutzungsinformationen.pdf)
c. Olimex ESP32-EVB (-EA) development board Rev. I, see https://www.olimex.com/Products/IoT/ESP32/ESP32-EVB/open-source-hardware

According to these reference examples, the software is offered in three variants: a, b and c. When ordering, the customer must choose one of the three options.

For performance reasons, it is possible to use/activate only one communication protocol (MQTT, KNX IP, REST-API) or data storage on an SD card at the same time. Although parallel use is theoretically possible, it can lead to performance problems and is therefore not guaranteed.

### 1.2 Hazard warnings

WARNING: This software is based on the analysis of the communication between TTE devices and not on official information from the device manufacturer. It must be assumed that the analysis is incomplete, faulty and cannot be applicable to all devices and their versions, especially future versions. Therefore, the use of this software with safety-critical TTE devices must be supervised. As safety-critical those TTE devices are meant, in which errors in the control can lead to damage to people, the environment, other devices, buildings etc. Supervised means that this device and all TTE devices connected to it must be constantly monitored by a person who, based on their training or experience, is able to recognize errors and, if necessary, switch off all TTE devices within a few seconds. This particularly expressly, but not exclusively, applies to combustion heating appliances.

IMPORTANT NOTE: The Hoval AG itself sells gateways for the connection of its TTE devices to the home automation systems via KNX or ModBus RTU / TCP buses / protocols. The provider of this CAN-

Gateway software recommends productive usage of those gateways from Hoval AG with safety-critical TTE devices.

IMPORTANT NOTE: The usage of this software in connection with TTE devices may lead to the guarantee and warranty claims for these TTE devices being void. The user of this software is responsible for checking the existence of corresponding clauses in the documentation for his TTE device and the legal situation in his country.

WARNING: This software allows changing parameters of the TTE devices. This software does not check whether the change of the parameters is meaningful and harmless for the operation of the TTE device and other associated TTE devices and other systems as well as for users and operating personnel of these TTE devices and systems, also for the environment and the building where these devices and thus connected systems are installed. As a user of the software, you must be very careful with parameter changes and only allow and directly or indirectly control those parameterizations whose purpose you fully understand and whose harmlessness for the operation of the TTE device and other associated TTE devices and other systems as well as for users and operating personnel of these TTE devices and systems, also for the environment and the building where these devices and thus connected systems are installed.

WARNING: If you use the microcontroller on which this software is installed in your WiFi or LAN network, you must ensure that no unauthorized people gain access to this network, as everyone with access to your network can access the CAN-Gateway Software without restrictions.

WARNING: The microcontroller on which this software is installed must be physically inaccessible to unauthorized persons. Everyone who has physical access to the microcontroller can easily read out the information stored on it, including your settings and passwords.

IMPORTANT NOTE: Any use of the CAN-Gateway software other than described above is not intended and leads to an exclusion of warranty and liability.

IMPORTANT NOTE: Every change and modification of the software by the user leads to a warranty and liability exclusion of the software provider.

### 1.3 Liability of the software producer and the provider

The software producer and the software provider are liable for errors in the CAN-Gateway software in accordance with the statutory provisions of the German sales law (§§ 434 ff. BGB). In the event of slight negligence, the software producer and the software provider are only liable in the event of a breach of essential contractual obligations (cardinal obligations) as well as in the event of personal injury in accordance with the German Product Liability Act (“Produkthaftungsgesetz”). Incidentally, the pre-contractual, contractual and non-contractual liability of the software producer and the software provider is limited to intent and gross negligence, whereby the limitation of liability also in the case of the fault of a vicarious agent of software producer or provider applies.

The liability of the software producer and the software provider is completely excluded in the following cases:

1. An error and the resulting direct and / or indirect damages or injuries are caused by a defective execution of the software, e.g. due to defective hardware or due to external influences on the hardware (mechanical, electrical, electromagnetic or other type).
2. An error and the resulting direct and / or indirect damages or injuries are caused by incorrect usage of the software, including, for example, the initiation of inappropriate, incorrect or even dangerous parameter changes by the user. This includes direct control through the user interface, via Android or Windows app, or indirect control in cases where the user has programmed or set other devices in such a way that they cause the parameters to be changed using a communication protocol via CAN-Gateway software.
3. An error and the resulting direct and / or indirect damages or injuries are caused by other reasons for which the software producer and software provider are not responsible.

### 1.4 Binding of the software to a MAC address specified by the customer

This software, with the exception of the demo version, is linked to a MAC address of the WiFi module of the ESP32 microcontroller specified by the customer. This means that the software has its full range of functions only on the microcontroller with this MAC address.

The customer has the right to transfer the software to another microcontroller with a different MAC address (hereinafter referred to as transfer). To do this, he must contact the software provider by email, telephone or post and request the transfer. The MAC address of the old microcontroller and the MAC address of the new microcontroller (of their WiFi module) must be provided by the customer. The software provider will process the request within 10 working days. After commissioning the software on the new microcontroller, the customer must completely delete the software on the old microcontroller as well as any backup copies of the software that he may still have.

If a customer requests the transfer of the software often than once a year, he must provide a plausible explanation. If there is justified suspicion of misuse and infringement of the software provider's copyrights, the software provider can refuse to transfer the software.

### 2 Introduction

This software make it possible to connect devices from series „TopTronic® E“ (TopTronic® E is the registered trademark of Hoval AG company) manufactured by Hoval AG to the home automation system. Such devices from series „TopTronic® E“ manufactured by Hoval AG are called Devices in the following.

These Devices have a CAN-Bus connection. It is used for intercommunication between devices, for example if many of them are installed together. CAN-Gateway can be connected to this CAN-Bus and can read the data that are sent over the bus. It also can generate data („write” the bus). This way it is possible to read information form the Devices and also control them for test reasons.

This software can be installed on an ESP32 DevKit board. The detailed specification of the required hardware and the whole assembly is given in the next section of this document. The whole assembly with installed software is called CAN-Gateway in the following.

ESP32 DevKit board has a WiFi interface. Using this interface CAN-Gateway can communicate to the home automation system (such as Home Assistance, OpenHab, ioBroker, Domoticz). As communication protocols MQTT, Modbus TCP or REST-API can be used. MQTT protocol is recommended and Modbus TCP protocol has some limitations. CAN-Gateway can be configured over the WiFi interface using an internet browser (Web interface).

Additionally the software has following functions:

- Log can data sent on the bus and show them in the Web interface
- Detect devices that communicate on the can bus and list them in the Web interface
- List all parameters communicated through the can bus

### 3 Required hardware and its assembly

There are various options:

Option | Recom-mended? | Total hardware costs (including shipping to Germany, prices include shipping, as of February 15, 2022, prices may vary) | Advantages / Disadvantages
CAN-Gateway development board from https://wled.shop | Yes | approx. 52 € | Fully built and tested. Available throughout the EU.
CAN-Gateway Basis-Board (without uC) + Enclosure (https://shop.myhome-control.de) (https://shop.myhome-control.de/) + ESP32 DevKit board (various offer on the market available) | Yes | approx. 44 € | Easy assembly (plugging in, screwing; no soldering etc.), interfaces are tested for functionality; BG02E interface is offered as an equipped option. Only available in Germany.
Olimex ESP32-EVB(-EA) development Board incl. enclosure | With restric-tions | approx. 50 € | No BG02E interface possible, CAN connection: only screw terminals. No power supply possible via Hoval CAN bus. Available as a version with an external antenna. Deliverable worldwide.
Do-It-Yourself made of prefabricated modules available on the market, reference design V5 | No | approx. 15 € to 30 € | Soldering etc. necessary, deep understanding of electronics necessary, no Ethernet interface possible.

### 3.1 CAN-Gateway development board (recommended)

Please refer to http://wled.shop/wpcontent/uploads/2021/11/CAN_Gateway_Nutzungsinformationen.pdf (http://wled.shop/wp-content/uploads/2021/11/CAN_Gateway_Nutzungsinformationen.pdf)

This is the recommended option. The CAN-Gateway software can be installed on this board very easily with just a few clicks and without special knowledge. The board has Ethernet interface, "plugand-play" CAN RJ45 interfaces, micro-SD slot, USB interface, enclosure, DIP switch for CAN termination. No disadvantages. Attention! The additional CAN interface on this board is not equipped as standard: a special BG02E interface is only possible with additional components soldered!

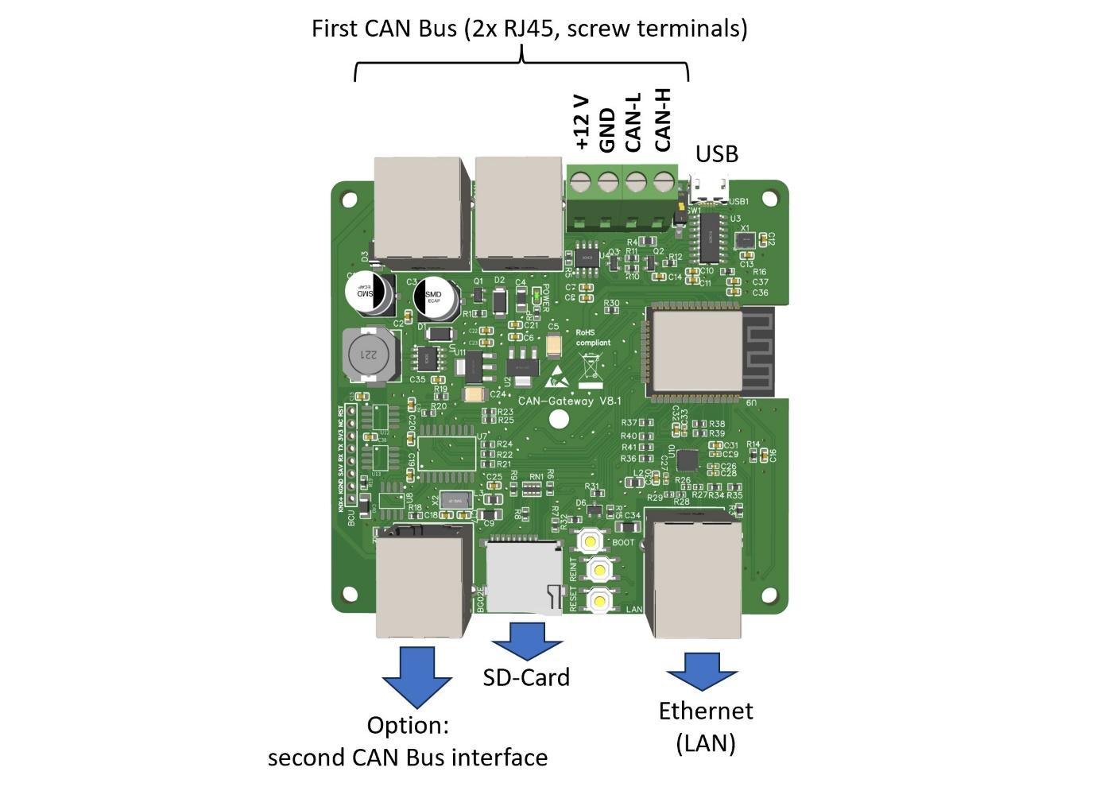
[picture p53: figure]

### 3.2 CAN-Gateway Basis-Board (without uC)

Please refer to https://shop.myhome-control.de/CAN-Gateway-Basis-Board-ohne-ESP32-uC/HW10001.2 (https://shop.myhome-control.de/CAN-Gateway-Basis-Board-ohne-ESP32-uC/HW10001.2)

This is another recommended option. In addition, an ESP32 DevKit Board (30-pin version, various suppliers) is required. The board has an Ethernet interface, "Plug-and-Play" CAN RJ45 interfaces, micro-SD slot, USB socket (only for power supply, no data, data interface via ESP32 DevKit Board!), housing, DIP switch for CAN termination. Additional equipment for the second CAN interface is available for a surcharge (only relevant for BG02E interface).

The SW variant is the same as for the CAN gateway development board from wled.shop.

### 3.3 Simple Do-It-Yourself hardware based on hardware modules available on the market

The following parts are required:

Part | Costs, approximately incl. shipping | Picture of the part (exemplarily)
ESP32 DevKit board with ESP-WROOM-32 module (not ESP32S !) and with 4MB Flash In the following 30-pin version is used. Other versions (for example 36-pin version) generally also can be sued, but have another pinning. | 5-10 €
SN65HVD230 CAN transceiver board (Attention: many China-parts are fake und does not work stable) | 1,5-5 €
LM2596 module for supply voltage (as 12 V to 5 V converter) | 1,2-5 €
Ethernet cable with RJ45 connector | 2-5 €

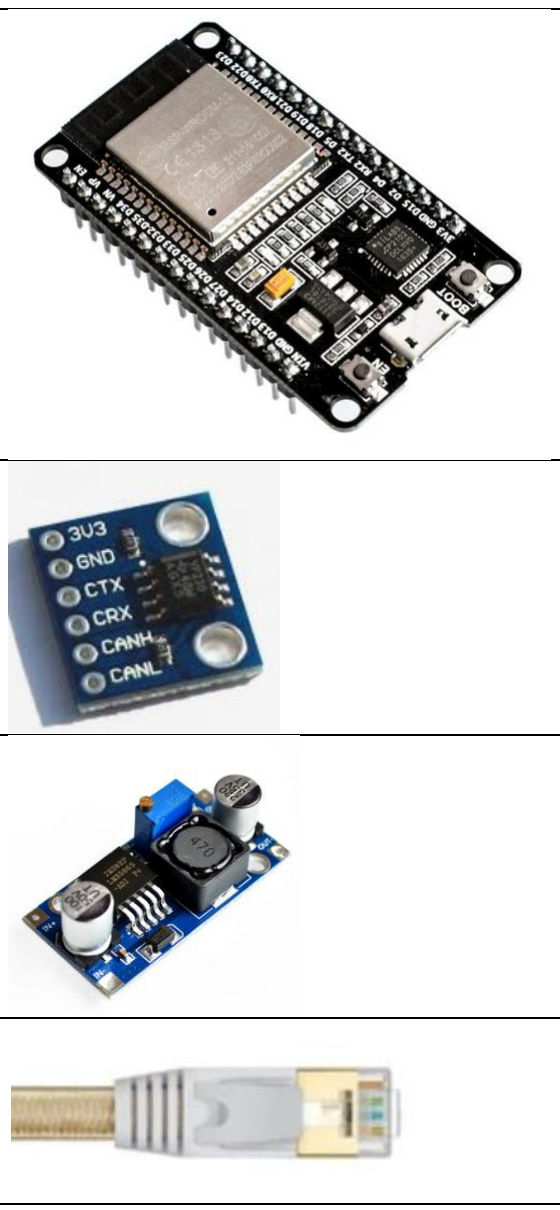
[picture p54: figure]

Attention! Ethernet cable is used, but it is for CAN bus and it has nothing common with a normal LAN communication. The CAN-Gateway should not be connected to a PC/laptop or router via Ethernet cable!

The assembly is as follows. Attention: LM2596 module must be adjusted first to 5V output voltage. This is done by the screw in the adjustable resistance (light blue on the picture below) and measuring the output voltage by a mustimeter. ESP32 module can work for a short time at 12 V, but gets hot over the time and can be damaged.


Important notes:

1) GND pin at RJ45: some devices use probably pin 3 instead of pin 7 or both. I recommend interconnect both pins (3 and 7) together to the ground.
2) CAN bus: CAN bus must be terminated on both ends. The devices from Hoval have termination resistances. They also have dip switches to switch the termination resistances on and off (for example, room control panel has them on the back side. Some devices have them close to the CAN connector, these dip-switches usually labelled as “R-CAN”). SN65VHD230 board has also termination resistance permanently installed. If you have only one Hoval device and can bus is not used, you can switch on the can-bus termination in your device and connect CAN-Gateway that is also terminated. If your installation already uses CAN bus (for example if you have ventilation device and room control unit), then your CAN bus is already fully terminated. You have to switch off one of the termination resistances using dip switches. If you are unclear regarding what you already have, you should use a multimeter to measure the resistance between CAN-high and CAN-low pins (devices must be switched off during this measurement!). The resistance must be approximately 60 Ohm in a full can bus system (including connected CAN-Gateway). If you measure resistance significantly lower than 60 Ohm, you CAN bus is “overterminated” and you have to switch off some termination resistances. ). If you measure resistance significantly higher than 60 Ohm, you CAN bus is “underterminated” and you have to switch on some termination resistances. For more details regarding CAN bus termination please refer to the respective information you can find in the internet (for example on Wikipedia).

There is an example of CAN-Gateway board with two RJ45 connectors. Two connectors can be used to integrate CAN-Gateway “in the middle” of your existing CAN bus system.

3) Power supply: you can supply the CAN gateway in two alternative ways:
a. Via the 12 V wire of the Hoval CAN buses (recommended). All Hoval main control units provide 12 V. It is used, for example, to supply the room control units. The CAN gateway can also be supplied from this 12 V wire and does not consume more power than one room control unit. Advantage: no additional power supply required.
b. Via the micro USB connection of the ESP32 board (optionally). If you already have many room control units that are supplied from a 12 V CAN bus line (please check Hoval documentation how many units can be supplied), you can supply the CAN gateway via the micro USB by a power supply (5 V / 0.5 A is sufficient, but please use high quality parts). In this case, the 12 V wire to Hoval devices must not be used, e.g. the corresponding wire in the RJ-45 cable must be disconnected. The GND wire must remain connected (in addition to CAN high and CAN low, of course).

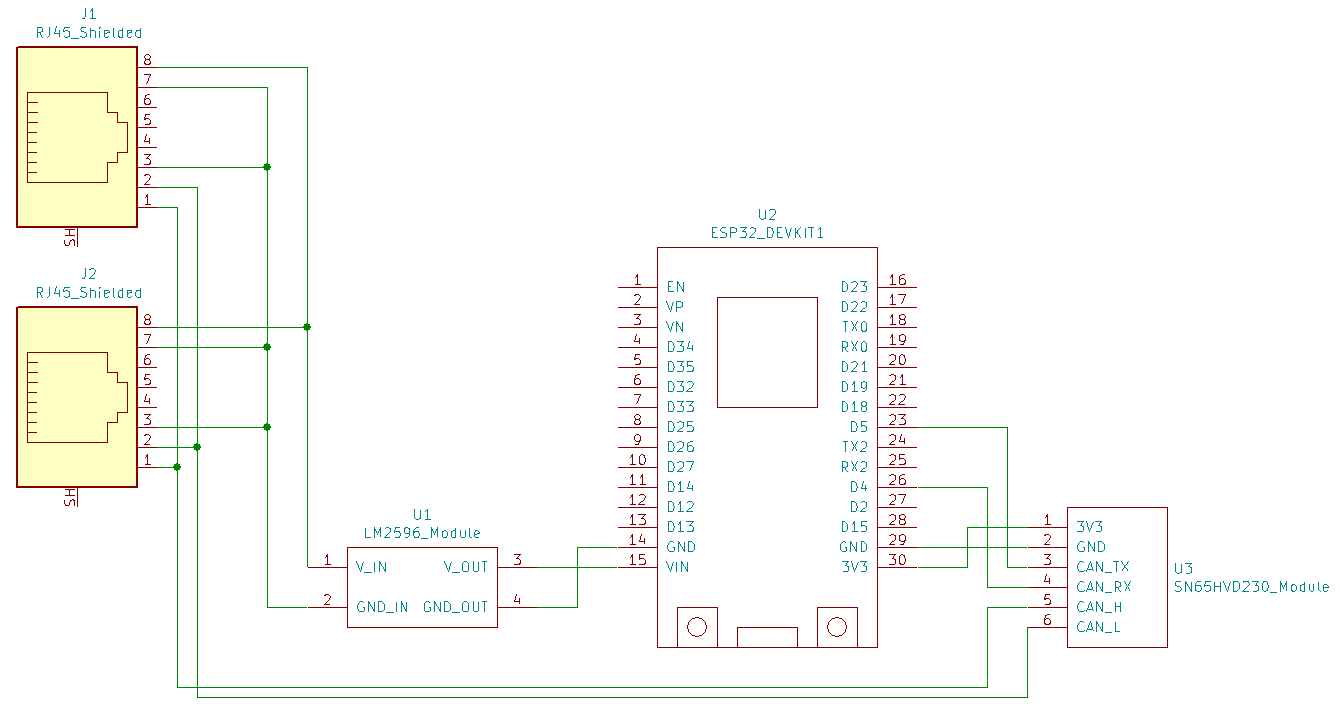
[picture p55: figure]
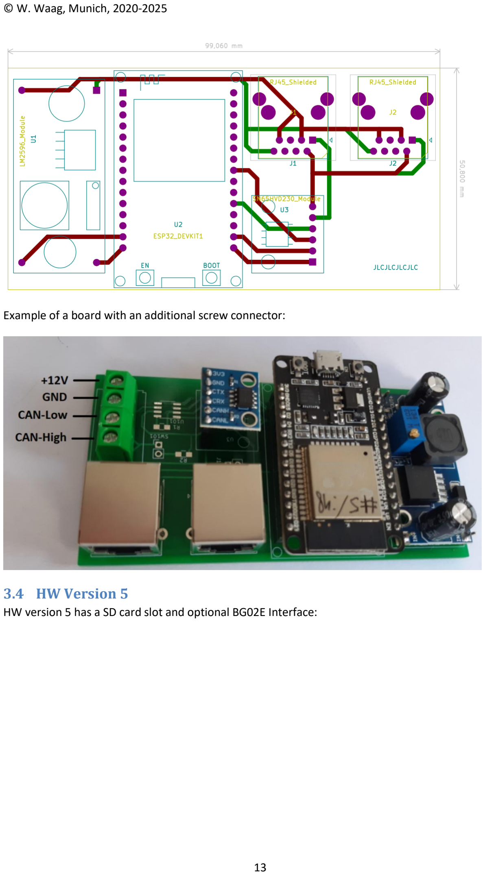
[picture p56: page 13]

Example of a board with an additional screw connector:

### 3.4 HW Version 5

HW version 5 has a SD card slot and optional BG02E Interface:

### 3.5 Use of the ESP32-EVB (-EA) development boards from Olimex as a CAN gateway

Company www.olimex.com offers a development board ESP-32-EVB (-EA), which can be used as CAN-Gateway hardware [new since SW version 28.001]:

Advantages of the Olimex board compared to CAN-Gateway HW V5:

- Ethernet (LAN) as an alternative to WLAN (initial configuration always takes place via WLAN, but you can then switch to Ethernet / LAN)
- -EA version with external WLAN antenna
- Metallic housing is available from Olimex for the -EA version

Disadvantages of the ESP32-EVB (-EA) board compared to CAN-Gateway HW V5:

- No RJ45 plugs for Hoval CAN bus, only screw terminals
- SD card: no automatic mount/unmount when inserting / ejecting during operation
- External power supply required, no power supply via Hoval CAN bus
- No BG02E interface option

Interfaces:

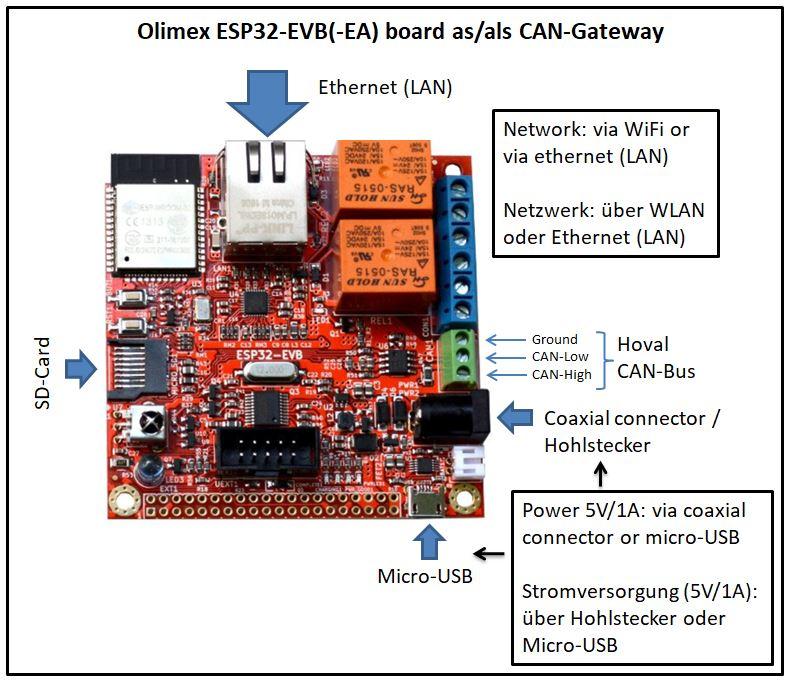
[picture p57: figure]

### 4 How to flash the software

### 4.1 Automated (recommended)

The DEMO version of the software can be easily installed via the web-based installer: https://wladwnt.github.io The DEMO version can later be updated to the purchased full version via the WEB interface of the CAN-Gateway.

### 4.2 Automated (recommended), only for CAN-Gateway development board

CAN-Gateway development board from wled.shop is delivered with software that allows other software to be easily flashed on it via the web interface. This way the CAN-Gateway demo or full version can be easily installed with just a few clicks.

### Manuell

The software is provided as a set of binaries und must be first installed on ESP32 based board. For that you have to connect the ESP32 board to the PC/notebook via USB cable and install the driver for the USB communication chip first. In total the following steps are required (assumed you use Windows 10):

1) Find out the required USB driver. The major of ESP32 DevKit boards use CP210x USB communication chip. The driver for this chip can be found there: https://www.silabs.com/products/development-tools/software/usb-to-uart-bridge-vcpdrivers (https://www.silabs.com/products/development-tools/software/usb-to-uart-bridge-vcp-drivers)
Olimex boards and some other use CH340 USB communication chip. The driver for this chip can be found there: http://www.wch-ic.com/downloads/CH341SER_EXE.html
2) Download the driver and install on your PC/notebook.
3) Restart your PC/laptop.
4) Check what COM-ports are already used in your PC/notebook. In Windows 10 do the following:
a. Open the Device Manager (right click on Windows symbol on your desktop and then on Device Manager).
b. In the Device Manager go to Ports (COM & LPT) and check the list.
5) Connect ESP32 DevKit board to the PC/notebook. A new virtual CAN-port will be set up and appear in the list. Remember its number.


6) Make a new folder on you C: drive. For example C:\CGW.
7) Download and unzip the ESP Download Tool in this folder. (https://www.espressif.com/en/support/download/other-tools, then under „Flash Download Tools“)
8) Unzip the CAN-Gateway software (files „CAN_Gateway.ino.bin” (or „CAN_Gateway_DEMO.ino.bin” for DEMO Version) in this folder too.
9) You will also need files (up to SW Version 29.101) „boot_app0.bin” (Source: https://github.com/espressif/arduino-esp32/blob/idfrelease/v3.3/tools/partitions/boot_app0.bin), (https://github.com/espressif/arduino-esp32/blob/idf-release/v3.3/tools/partitions/boot_app0.bin) bootloader_qio_80m.bin (Source: https://github.com/espressif/arduino-esp32/tree/idfrelease/v3.3/tools/sdk/bin/bootloader_qio_80m.bin) (https://github.com/espressif/arduino-esp32/tree/idf-release/v3.3/tools/sdk/bin/bootloader_qio_80m.bin) and CAN_Gateway.ino.partitions.bin (source:
https://github.com/wladwnt/wladwnt.github.io/blob/main/cangw/CAN_Gateway.ino.partiti ons.bin). (https://github.com/wladwnt/wladwnt.github.io/blob/main/cangw/CAN_Gateway.ino.partitions.bin) Download and save them in the folder above.
Starting with SW Version 29.201 the respective files are: https://github.com/wladwnt/wladwnt.github.io/blob/main/cangw/boot_app0_v202.bin,https://github.com/wladwnt/wladwnt.github.io/blob/main/cangw/CAN_Gateway.ino.partitions_v202.bin (https://github.com/wladwnt/wladwnt.github.io/blob/main/cangw/CAN_Gateway.ino.partitions_v202.bin) and
https://github.com/wladwnt/wladwnt.github.io/blob/main/cangw/CAN_Gateway.ino.bootloader_v202.bin. (https://github.com/wladwnt/wladwnt.github.io/blob/main/cangw/CAN_Gateway.ino.bootloader_v202.bin)
10) Now you must have the folder like this:

11) Execute ESP32 Download Tool (.exe from the folder flash_download_tool_vX.X.X, where X.X.X is the current version)
12) The following window will appear, please select for ChipType „ESP32” and forWorkMode “develop”.
13) Please enter the data into the next dialog window as shown below. The only parameter you have to select is the COM-port number. If you get some issues during flashing process, you also can try to select lower baud rate. Please take care that all check boxes are selected correctly. Then click on “Start”.

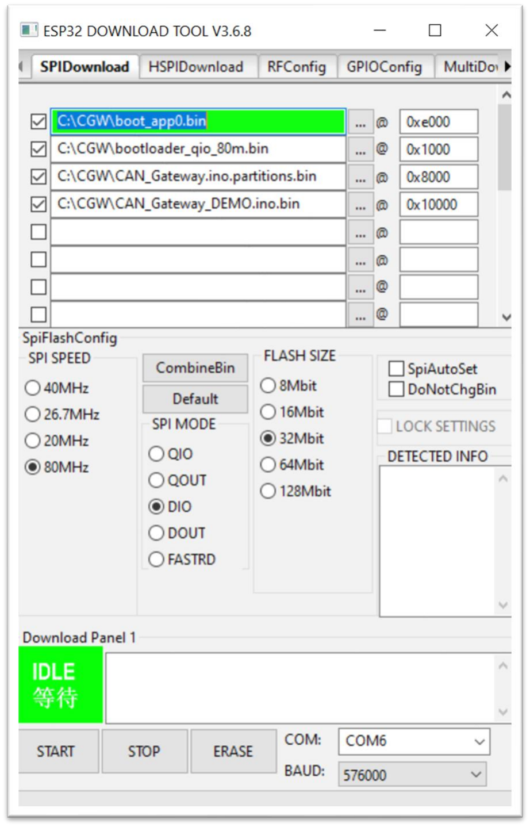
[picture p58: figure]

14) As soon as flashing ends, you will see green field „Finish“. Now you can exit flash tool.

Alternatively to the Flashtool other tools can be used (such as esptool.exe or esptool.py that are parts of the Arduino development environment with installed ESP32 Board extensions).

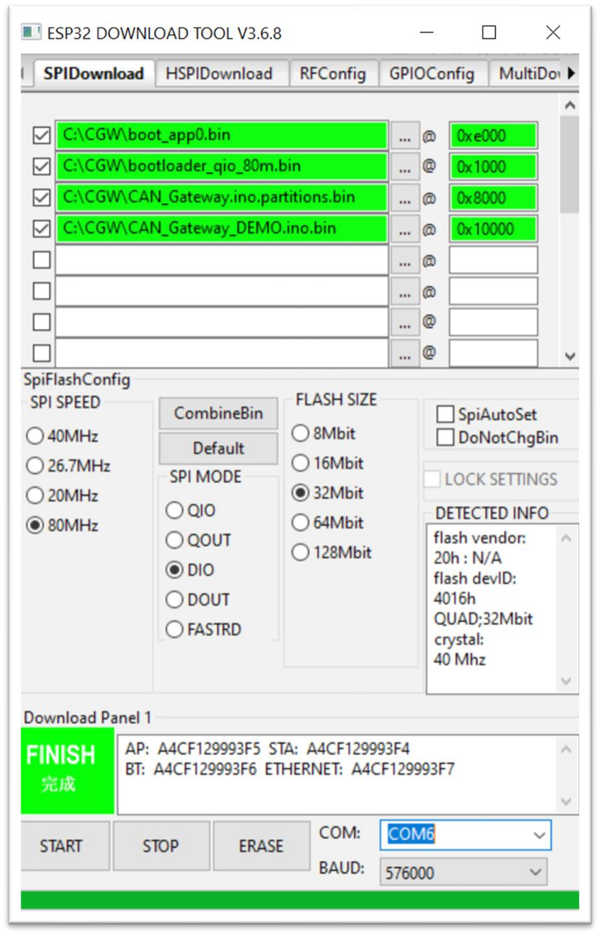
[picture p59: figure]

15) Restart ESP32 DevKit board either repower it via USB or using reset button on the board.

If you use esptool.exe for flashing, please use the following parameters and do not forget to use correct COM-Port number:

esptool.exe --chip esp32 --port COM6 --baud 256000 --before default_reset --after hard_reset write_flash -z --flash_mode dio --flash_freq 80m --flash_size detect 0xe000 C:\CGW/boot_app0.bin 0x1000 C:\CGW/bootloader_qio_80m.bin 0x10000 C:\CGW/CAN_Gateway.ino.bin 0x8000 C:\CGW/CAN_Gateway.ino.partitions.bin

### 5 First initialisation

If you power on the CAN-Gateway in the initial state, meaning you first time installed the software, it generates a WiFi access point with the name “cangateway”. You have to connect PC/notebook/tablet to this access point to configure the CAN-Gateway. The password is 000999555. In details, the following steps are required (assuming you run Windows 10):

1) Be sure you know your present WiFi name and password. In next steps you will connect your PC to the cangateway access point. Later you will need to connect it again to you home WiFi network. For this you might need to enter you home WiFi password.
2) Click on the desktop on WiFi Symbol. In the widow opened please find network named „cangateway“. Click on it and then on “Connect”.


3) Then you need to enter the network key (000999555).
4) Wait until the connection is established. It might show that there is no internet connection; that is OK.
5) Now you are connected to the CAN-Gateway.
6) Open you WEB browser and go to the address http://cangateway.de. You will see the Web interface of the CAN-Gateway. This web page is not somewhere on an internet server but on your CAN-Gateway directly. At first you can choose between German and English interface language.

7) Click on „Settings” and read carefully Terms and Conditions. They are exactly the same as described in section 1.2 and 1.3 of this operating manual. If you agree please click on „I agree to these terms and conditions.”:
8) On the next page click on „Download and show present CAN-Gateway settings“. Firstly you can enter your WiFi network name and password. All other settings you can leave as it is. Then click on „Save settings (send them to CAN-Gateway) & restart“. Now you can disconnect your PC/notebook/tablet from cangateway network and connect it back to your home WiFi access point. Attention: as soon as you change network name from “cangateway” to something different, the cangateway considers it as an existing WiFi network and does not initiates access point any more.

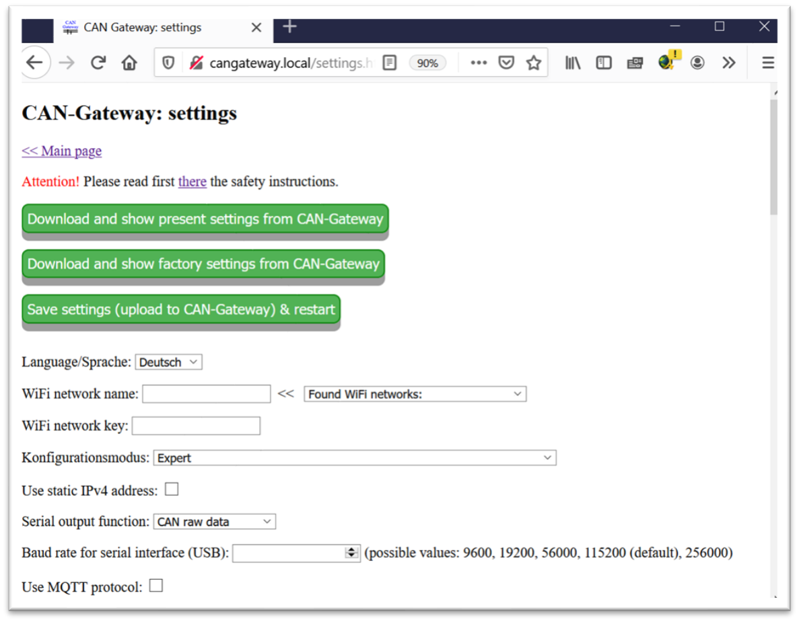
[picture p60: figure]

9) After restart the CAN-Gateway will try to connect to your home WiFi network. Your WiFi router must support 2,4 GHz frequency band, 802.11b/g/n standard, WEP/WPA-TKIP/WPA2-CCMP authentication as well as DHCP protocol (all that is typical for modern routers). Be sure that it is also configured to accept new WiFi clients (not to block unknown MAC addresses etc.). Now CAN-Gateway must be connected to your home WiFi network. I recommend restarting your PC/notebook now. It should allow you to reach CAN-Gateway interface under http://cangateway.local using your Web browser (works perfect for example with Firefox, but does not work with Chrome since it try to find this address in google, but this is a local address). CAN-Gateway uses mDNS protocol. Windows 10 identify new mDNS clients only if Bonjour service¹
is installed and only after restart. If you run iOS or Linux, they should support mDNS protocol out-of-the-box. If you run Android or other operating systems, the probably does not support mDNS protocol. If the address http://cangateway.local does not work, you have to find out IP address of the CAN-Gateway using your router. Please refer to your router documentation how to do that. If you have Fritzbox as a router, you can simple try “http://cangateway” (for CAN-Gateway software version 19.001 and newer) or “http://espressif” (for CAN-Gateway software below version 19.001).
[new in SW 27.400] CAN-Gateway supports SSDP protocol and is listed in Windows under “Network” section. With the right mouse click on the “CAN Gateway” you will get to "properties" and there you can read the IP address of the CAN Gateway.

1 How to install bonjour service can be found at: https://softwarekeep.com/help-center/what-is-bonjourservice-on-windows-10. (https://softwarekeep.com/help-center/what-is-bonjour-service-on-windows-10) After installation complete, please restart your PC/notebook.

### 6 Web interface: Main page

CAN-Gateway has a Web interface. It makes possible to use various functions of CAN-Gateway: configure it, change settings, list parameters, list devices found, read raw can data etc. Web interface can be accessed via address http://cangateway.local. The prerequisite is that the operating system on your PC/notebook supports the mDNS protocol (please refer to the previous chapter). Web interface can also be accessed via IPv4 address.

On this page you can also select the language of the CAN-Gateway interface. This selection is only valid until next reboot, it is not stored permanently. To change the language preference permanently, you have to change the respective option in “Settings”.

### 7 General information about devices and their parameters

Parameters are data that can be read from devices or that can be changed in the devices by a write request to control the respective device. Examples: temperature measured by the device, device name, device mode, set value for the temperature controlled by the device. Different device types have different parameters. Each parameter, also called “datapoint”, has a datapoint ID (that is its unique number), belongs to a certain function that is described by a function number and the function belongs to a certain function group that is also described by a number. Since each device is identified by a device type and device address, each parameter in total can be uniquely described by five numbers: device type, device address, function group, function number and datapoint ID.

- Device type: The mapping of device types to the respective device type numbers can be found on the page with CAN-Gateway settings in web interface.
- Device address: The device address can be seen, for example, in the room control unit. It also can be changed using room control unit if you have access to the respective user level (regarding user level please refer to the next chapter) or also using this CAN-Gateway software. Usually, however, there is no need to change it. The only reason might be if you want to connect the device of the same type to the CAN bus. All devices of the same device type must have different addresses. The standard address is usually 8. For easily identification of all devices connected to the can bus, the CAN-Gateway analyses the CAN bus communication and list all devices found with their types and addresses. This list is accessible through the CAN-Gateway web interface.
- Function group: The function group can be seen in the room control unit, if you have it. Under “Service” all devices available in your installation are listed. For each device different function groups can be seen and in the brackets the respective number. Function group is also given in the Excel file with the list of available parameters provided by Hoval.
- Function number: The function number can be seen on the room control unit similar to the function group or also in the Excel file mentioned above.
- Datapoint ID: Datapoint IDs can be seen similar to functions numbers on the room control unit or also in the Excel file mentioned above. On the room control unit it is the number shown between the parameter name and parameter value. It is given in the form XX-XXX and displayed in grey. The hyphen must be just ignored, so it is just one number.

All parameters that can be read from devices or set in the devices are generally available on the CAN bus. On the can bus also parameters available, that does not shown on the room control unit at some User Levels.

CAN-Gateway has a parameter logger integrated. It shows in the Web interface all the parameters currently passed over the CAN bus. This function, however, is only meaningful if a room control unit or gateway is installed in the system because parameters are only passed over the CAN bus if some device request for them. Parameters configured in CAN-Gateway are periodically requested by CAN-Gateway and when the devices answer to the respective request, the parameter is also shown in the parameter logger window of the Web interface.

Basically it is possible to request over the CAN bus a list of parameters supported by a certain device. The room control unit, for example, uses this functionality. This is, however, is not supported in the present version of CAN-Gateway.

### 7.1 Example

In the following the parameter is considered that belong to the room control unit itself and defines the time delay until touch screen is darkened after is not touched for a while (“Time until darkening”).

Since the parameter belongs to the room control module (TTE-BM), te respective device type is 16. The device address in this example is 8. The parameter belongs to the function group “Preferences”. This function group has number 80. The function is „Brightness“ with the number=1. Datapoint ID is „00-001“, that means = 1. The present value is 60s.

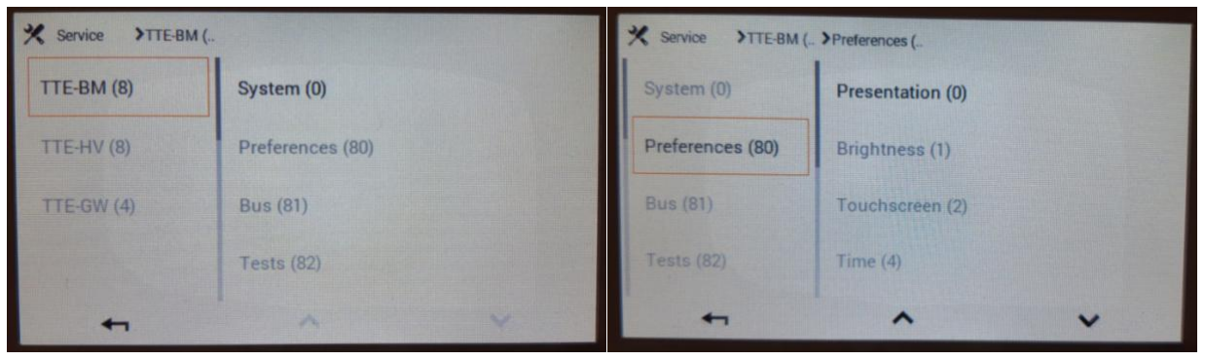
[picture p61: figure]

### 8 User Levels

User Level describes the access level: it defines what parameters the user can read and change using room control unit. In total there are 8 User Levels: 0 to 7. User Level = 0 (default) is the lowest one; User Level = 7 gives full access to all parameters available, also the write permissions for all parameters, even for those that should not be changed at all. Each user level (except the lowest one) is protected with a password. Important to understand, that User Levels are only related to the room control unit. On the CAN bus all parameters are available independent on User Level of the room control unit. That is why CAN-Gateway can read all parameters and even write all parameters (But please take care if you change values!). To mention, CAN-Gateway can work without room control unit. CAN-Gateway can also, for example, read out all User Level passwords from the room control unit.

### 9 Web interface: General settings

Web interface allows configuring the CAN-Gateway. The following settings are available:

- Web Interface language (German or English)
- [new in SW 28.001] Select WiFi or Ethernet (LAN, only for boards that support Ethernet: currently only Olimex ESP32-EVB(-EA) development boards)
- WiFi network name and network key (password)
- Option to use static IP address for WiFi network (default is the receiving the IP address from DHCP server of your router)
- Function of the serial interface (USB): there are 3 options to select:
- CAN raw data – over the serial interface all can raw data are provided: CAN-ID, DLC, data bytes.
- Parameters - over the serial interface all parameters detected on the CAN bus are provided.
- Debug information: over the serial interface debug information and current status of the CAN-Gateway is provided. It can be helpful for trouble-shooting.
- Baud rate of the serial interface (USB)
- MQTT server IP, server port, user name, password. Must be according the settings in your MQTT broker.
- MQTT prefix. This is the common part for all MQTT topics. Please refer to section “Parameter transmission using MQTT Protocol”.
- [new in SW version 26.001] Support Home Assistant (https://www.home-assistant.io/) / MQTT Discovery (https://www.home-assistant.io/docs/mqtt/discovery/) for sensors.
- Identification of the CAN-Gateways on the CAN bus (device type and address).
- Option (on/off) that controls if the CAN-Gateway is shown in room control unit, in the list of devices available in the system and if CAN-Gateway can be controlled via the room control unit (please refer to section „Control CAN-Gateway using room control unit“).
- [new in SW version 22.001] Time server to get the current time information over NTP protocol.
- [new in SW version 22.001] UTC Offset for the local time in seconds.
- [new in SW version 23.001] Option how historical data are stored in RAM for each parameter. The following options are available:
- Over last 6 hours: one value each 5 min.; over last 6 min.: one value each 10 sec.
- Over last 12 hours: one value each 10 Min.; over last 6 min.: one value each 10 sec.
- Over last 24 hours: one value each 20 Min.; over last 6 min.: one value each 10 sec.
- Over last 24 hours: one value each 20 Min.; over last 36 minutes: one value each min.
- Over last 3 days: one value each hour; over last 6 min.: one value each 10 sec.
- Over last 3 days: one value each hour; over last 36 minutes: one value each min.
- [new in SW version 26.001, only with HW V5 and above] Storage of data on SD card.

Before changing the settings, you should download and show the present settings of the CAN-Gateway. Then you can change them and click on “Save settings” to store changes on CAN-Gateway. After that the CAN-Gateway performs soft reset automatically.
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

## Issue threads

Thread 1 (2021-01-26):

Source code for ESP app

zittix, 2021-01-26:
Would it be possible to get access to the ESP source code to see how the CAN protocol is decoded?

Thanks!

zittix, 2021-01-28:
@chrishrb @bagges I came up with a super dirty python script to decode the Hoval CAN bus.. working great with Home Assistant. It's just a prototype for now but at least it's open. Have a look here: https://gist.github.com/zittix/b27ce4deb40a63a657fe6c0273cb2f05

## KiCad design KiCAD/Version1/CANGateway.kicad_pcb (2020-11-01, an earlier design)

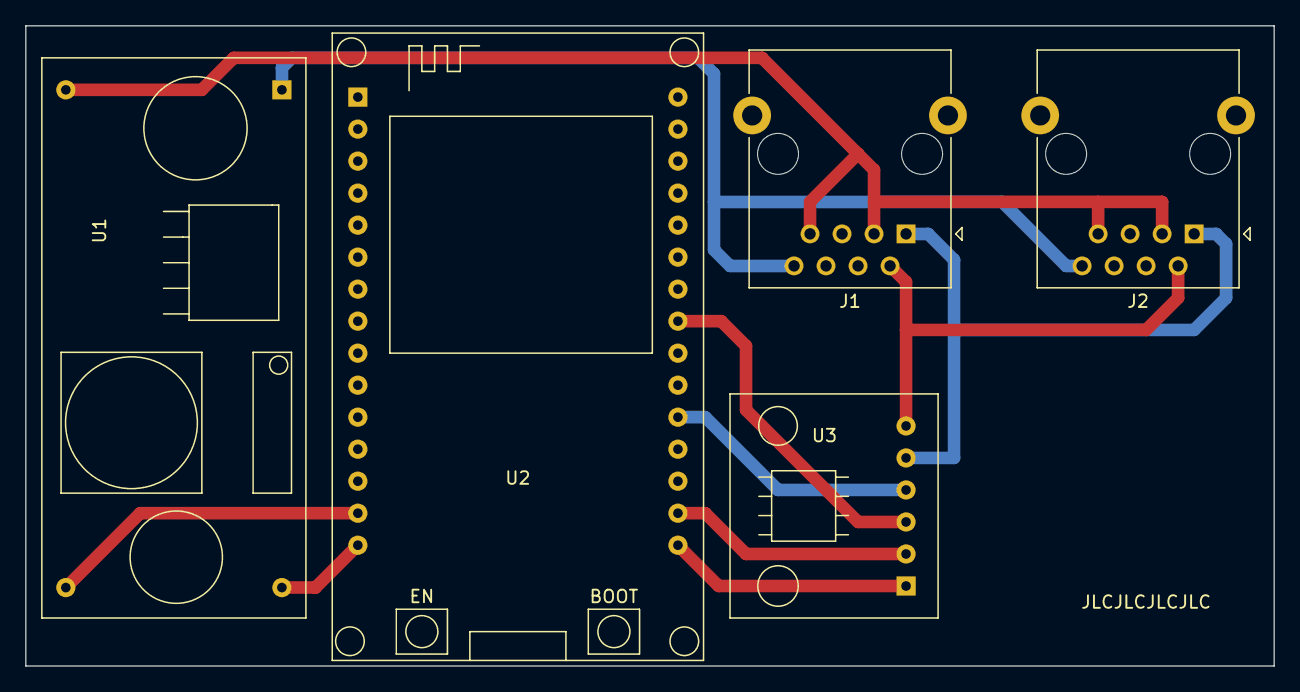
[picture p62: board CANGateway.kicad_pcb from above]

Board: 2 copper layers, 99.1 x 50.8 mm, 5 parts (0 on the bottom side), 10 nets.

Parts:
J1, J2: RJ45_Shielded; RJ45_Ninigi_GE
U1: LM2596_Module
U2: ESP32_DEVKIT1; ESP32_DEVKIT
U3: SN65HVD230_Module

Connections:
unnamed: J1.1, J2.1, U3.5
unnamed: J1.2, J2.2, U3.6
unnamed: J1.3, J1.7, J2.3, J2.7, U1.2
unnamed: J1.8, J2.8, U1.1
unnamed: U1.3, U2.15
unnamed: U1.4, U2.14
unnamed: U2.23, U3.3
unnamed: U2.26, U3.4
unnamed: U2.29, U3.2
unnamed: U2.30, U3.1

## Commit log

2020-03-22 Corrected HW (GND Pin)
2020-03-22 HW correction (GND Pin3 on RJ45)
2020-10-07 Klarstellung bzgl. GND Pins.
    Die beste Lösung ist wohl beide Pins (3 und 7 am RJ45) mit GND zu verbinden.
